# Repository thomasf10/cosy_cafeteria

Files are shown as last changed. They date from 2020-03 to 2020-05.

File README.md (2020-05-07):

# cosy cafeteria: project embedded systems design 2 
This repository contains the developed software and hardware for the lab project of embedded systems design 2.

## Structure
- [Software](Software)
  * [Python server script](Software/python_wifi/WiFi.py)
  * [ESP32 code](Software/fullcode)
- [Hardware](Hardware)
  * [Main PCB](Hardware/MainPCB)
  * [Sensor PCB](Hardware/SesnorBoard)
- [Website/Dashboard](Dashboard)
- [Report](Report/Report.pdf)

## Project discription
To  improve  the  experience  of  the  students  in  the  cafeteria,  an  embeddedsystem will be developed to gather a variety of data.  This data will then bedisplay to the students through an online medium such as a website.  Themain focus will be to gather information about the amount of people thatare in the cafeteria. There are two main goals. The first goal is to display theestimated waiting time to get a meal to the students.  Secondly the amountof available seats will be tracked and displayed to the students.  Next to thissome additional information will be gathered.  The temperature, air-qualityand sound level will be monitored to give the student a general idea about theconditions in the cafeteria.  This way the student can gauge if the cafeteriais suitable to study in at a certain moment.  An overview of the envisioned system is displayed in the figure bellow. 

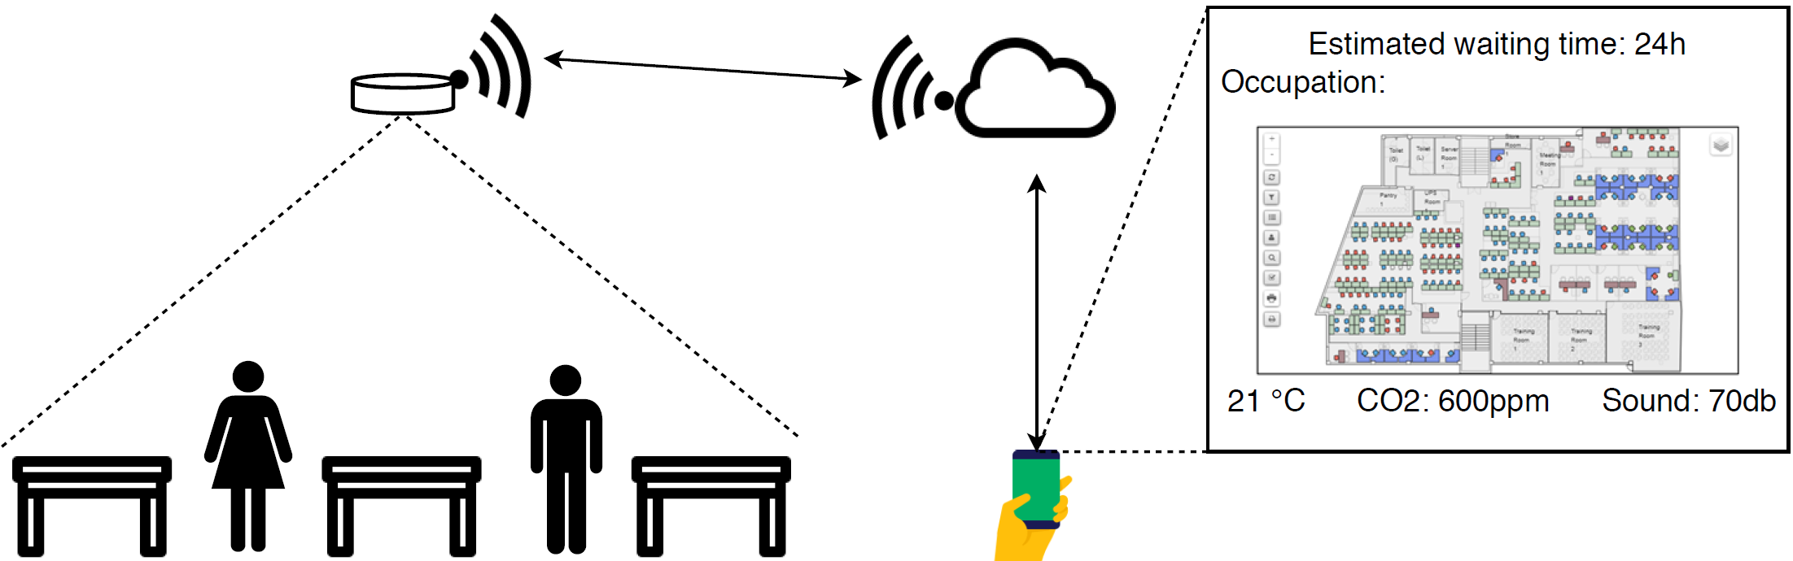
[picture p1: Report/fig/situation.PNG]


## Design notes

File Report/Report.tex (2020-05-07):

\documentclass[11pt,a4paper]{article}
\usepackage{siunitx} % si eenheden
\usepackage{hyperref}					% maak PDF van de thesis navigeerbaar
\usepackage{url}
\usepackage[toc,acronym,xindy]{glossaries}%voor afkortingen
\usepackage{amsmath}
\usepackage[official]{eurosym} % om euro symbool te kunnen gebruiken
\usepackage{graphicx}
\usepackage{svg}
\usepackage[final]{pdfpages}
\usepackage[square,numbers]{natbib} 
\bibliographystyle{IEEEtran}
\usepackage{tabularx}  % betere tabellen
\usepackage[small,bf,hang]{caption} % verbetering captions
\captionsetup[table]{singlelinecheck=off} % caption van tabellen links uitlijnen
\usepackage{color, colortbl}
\definecolor{Gray}{gray}{0.9}
\usepackage{longtable}
\usepackage{titlesec} 					% voor mooiere paragraph
\titleformat{\paragraph}
{\normalfont\normalsize\bfseries}{\theparagraph}{1em}{}
\titlespacing*{\paragraph}
{0pt}{3.25ex plus 1ex minus .2ex}{1.5ex plus .2ex} % nog steeds voor paragraph

% =========== BELANGRIJK VR IN HET VERSLAG: Tonen dat je hebt nagedacht over dimensionering componenten! ===========

% MFA: zet zoekpad voor figure
\graphicspath{{fig/}}
\usepackage{float}                      % De optie H voor de plaatsing van figuren op de plaats waar je ze invoegt. bvb. \begin{figure}[H]

\begin{document}
\title{Embedded systems 2\\
	\Huge Report Cosy Cafeteria
}
\author{Robin Van de Poel\and Arthur Van den Storme\and Tobias Cromheecke\and Thomas Feys}
\date{\today}
\maketitle
\newpage

\tableofcontents
\newpage

\section{Intro}
To improve the experience of the students in the cafeteria, an embedded system will be developed to gather a variety of data. This data will then be display to the students through an online medium such as a website. The main focus will be to gather information about the amount of people that are in the cafeteria. There are two main goals. The first goal is to display the estimated waiting time to get a meal to the students. Secondly the amount of available seats will be tracked and displayed to the students. Next to this some additional information will be gathered. The temperature, air-quality and sound level will be monitored to give the students a general idea about the conditions in the cafeteria. This way the students can gauge if the cafeteria is suitable to study in at a certain moment. An overview of the envisioned system is displayed in figure~\ref{fig:system}. All the developed hardware and software is displayed at: \url{https://github.com/thomasf10/cosy_cafeteria}.
\begin{figure}[H]
	\centering
	
	\caption{Situation sketch}
	\label{fig:system}
\end{figure}

\section{Specifications}
%Zoals we geleerd hebben in dit vak? eerst specs opstellen
%Hierbij moet de keuze's vermeld worden over:
% - Dimensions
% - Microcontroller 
\subsection{Functional specifications}
\begin{itemize}
	\item Monitor the available seats
	\item Monitor the queue to get a meal
	\item Display the data to the students
	\item Energy provision for 1 semester (4-5 months)
	\item Wireless coverage over the entire campus
	\item Measure new data every 10 minutes
	\item Send the data to the online medium every hour 
	\item If the data changes with a large amount (needs to be specified) update the online medium sooner
\end{itemize}

\subsection{Other technical specifications}
\begin{itemize}
	\item Enclosure: 10 x \SI{10}{\centi\meter}
	\item Easy deployment: the node must be easy to attach and detach from the sealing
	\item Must be easy to recharge (Wireless or via USB)
	\item Light weight: \SI{300}{\gram} (so it wont detach from the sealing)
\end{itemize}

\subsection{Non-technical specifications}
\begin{itemize}
	\item Cost: $<$ \euro{100}
	\item The data should be easy accessible to the students
\end{itemize}

\section{System architecture}
An overview of the full system is displayed in figure~\ref{fig:architecture}.
\begin{figure}[!ht]
	\centering
	
	\caption{System architecture}
	\label{fig:architecture}
\end{figure}
The developed system uses three sensors: 
\begin{itemize}
	\item AMG8833: IR grid sensor
	\item CSS811: air quality sensors
	\item Sparkfun sound detector: microphone
\end{itemize}
By incorporating these sensors into the system, a variety of sensor data is gathered, namely: ambient temperature [\SI{}{\celsius}], $CO_2$-level [ppm], TVOC-level (total volatile organic compounds) [ppb] and sound level [db]. Next to this the AMG8833 captures the temperature af a two dimensional area in 8 by 8 pixels. 
\\ \\
The 'brain' of the system is an ESP32, this microcontroller has an integrated Wi-Fi module, which will be used to transmit the data. The gathered data is sent to a server, which stores the received data in a database. 
\\ \\
Alongside the reception of data from the ESP32, the server hosts a website which is used to display the data to the students. The website uses the pixel data to generate a heatmap of the cafeteria, this allows the students to see how many people are present in the cafeteria. Unfortunately one module cannot cover the entire cafeteria, to generate the heatmap. In order to do this, several modules have to be deployed in the cafeteria. In this project only one module will be constructed as a proof of concept. Next to the heatmap, the other sensor data is displayed on the website this includes: ambient temperature, $CO_2$-level, TVOC-level and the sound-level. Based on these parameters the students can gauge if the cafeteria is currently suitable as a study-location.

\section{Power management design}
This section explains the different trade-off's which were made in designing the power management part of the system. The first part in designing the power management is choosing a way to supply the circuit. In our case, the device needs to be deployed at the ceiling of a cafeteria. You can't just tap off the electricity cable at any point here, so our device will need a battery to supply the power. Our first aim was to supply the device as long as one semester. Another aspect was the ability to recharge the battery for environmental reasons. This excludes standard cell batteries that have a much lower energy density and are not rechargeable. Our choice was quickly made for the type of battery, namely a Lithium-Ion (Li-Ion) battery which will be discussed in section \ref{sec:liIon}.

\subsection{Lithium-Ion battery}\label{sec:liIon}
Lithium-Ion batteries are now a commonly used battery in consumer electronics. Li-Ion batteries are the most commonly used batteries in phones, MP3 players and other portable equipment. The voltage of a single Li-Ion battery cell is usually fixed at 3.6 V or 3.7 V. We call this the nominal voltage. However, the actual voltage during use can vary from 2.4 V to 4.2 V. When the voltage drops below 2.4 V, the cell is discharged too deeply and damaged beyond repair. Therefore, a safety voltage of 3 V is often maintained. If the cell is discharged to this voltage, nothing is wrong. Charging a Li-Ion battery usually takes 3 hours. Don't be blinded by fast chargers for these batteries, practical tests have shown that it takes 3 hours until a battery is fully charged \cite{LiIon_ledscherp}. A few benefits of a Li-Ion battery are:
\begin{itemize}
	\item Very high energy density
	\item Minor self-discharge
	\item No memory effect
	\item High power, long service life
\end{itemize}
Some disadvantages are:
\begin{itemize}
	\item Relatively expensive to purchase
	\item Dangerous if used incorrectly, can explode/combust
	\item Need a protection circuit to not drop below the 2.4 V threshold value
	\item Charging and discharging process needed 
\end{itemize}
The most common Li-Ion battery is the 18650 cylindrical cell which is 18mm wide, 65mm long and the '0' stands for its cylindrical shape. Another common type of Lithium-Ion battery is the Lithium-Ion Polymer (Li-Po) battery.
%Li-Po's are:
%\begin{itemize}
%	\item Lighter
%	\item Faster recharge
%	\item Higher power: it's easy to produce batteries that can discharge 10C, 20C\footnote{\url{https://batteryuniversity.com/learn/article/what_is_the_c_rate}}.
%	\item Safer: less ability to explode/combust
%	\item Flexible: can bent (up to $90^\circ$) and deform + can be made in a variety of shapes
%	\item More expensive
%\end{itemize}
Li-Po's are preferred over standard Li-Ion batteries in application where weight reduction is important, fast charge opportunity is needed and which need a very high current during discharge time. Li-Po's are more used for drones (where lightweight is a requirement) and electric cars (fast charging requirement). Li-Po's are also less likely to combust or explode and are more expensive. Therefor a Li-Po would be overkill in our application \cite{LiIonVsLiPo_Ovonic,LiIon_Wiki,LiPo_Wiki}. 

\subsubsection{Selected battery}\label{sec:selected_battery}
The reason we chose a single cell Li-Ion battery was:
\begin{itemize}
	\item Voltage range: our microcontroller needs 3.3 V supply voltage, which is only a low dropout voltage of 0.4 V in comparison with the 3.7 V nominal voltage of a single cell Li-Ion battery. This results in less power dissipation in the voltage regulator. 
	\item Rechargeable: for environmental aspects
	\item High capacity: around 3000 mAh, to last a semester
\end{itemize}
The specifications of the chosen NCR18650B are:
\begin{itemize}
	\item Size/package: 18650
	\item Rated capacity: 3200 mAh
	\item Nominal voltage: 3.6 V
	\item Maximum voltage: 4.2 V
	\item Maximum charge current: 1625 mA
	\item Maximum discharge current: 6400 mA\footnote{Maximum discharge rate is 2C. This means discharging the battery capacity in 0.5 hours $\frac{3200 mAh}{0.5 h} = 6400 mA$ .} % https://batteryuniversity.com/learn/article/what_is_the_c_rate
	\item Maximum discharge voltage: 2.5 V
	\item Charge time: 4 hours
	\item No protection circuit
\end{itemize}
To charge the Li-Ion we had to include a charge circuit in our design. We found a high frequently used breakout board to charge a single cell Li-Ion battery via USB with battery protection \href{http://acoptex.com/project/9446/basics-project-082a-lithum-battery-charger-tp4056-at-acoptexcom/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}{here}. Such a charge circuit would be perfect for our application. Because we couldn't use a breakout board we had to integrate the components on one PCB. Unfortunately the components which were used on the breakout board were not available on the websites we're using to order components like Mouser, Digi-Key, Farnell, etc. After some research and a recommendation of a fellow student who had experience with battery charging applications in his master thesis, he advised to go for Texas Instruments IC's for charging Li-Ion batteries. The charger IC didn't have a protection circuit on it, so we also needed a circuit for this. Eventually we also went for a protection IC and voltage regulator of Texas Instruments. To protect the circuit from reverse polarity of the battery we also included a self-designed protection circuit which was first evaluated in LT Spice. All named components will be discussed in the following sections.

\subsection{Reverse polarity protection}
Reverse polarity protection is a nice feature to have te protect a circuit against polarity mismatches of the battery. For the design of this circuit we based us on a design found on the internet \href{http://kaktuscircuits.blogspot.com/2014/07/reverse-polarity-and-overvoltage.html}{here}. Before implementing this circuit in our design we first evaluated it's correct functioning using LT Spice in section \ref{sec:reverse_pol_prot_sim}.

\subsubsection{Simulation}\label{sec:reverse_pol_prot_sim}
Reverse polarity protection is simply done by including a P type MOSFET as shown in figure \ref{fig:reverse_polarity_protection_simulation}. Since the maximum voltage  of the battery is limited to 4.2 V, there is no need for high drain-to-source voltage $V_{DS}$ requirements for the MOSFET. A suitable MOSFET was found \cite{bib:NTR2101P}. Normally there should be a zener diode placed between gate and source to protect the maximum gate-to-source voltage $V_{GS}$. Since the selected MOSFET's $V_{DS}$ = $V_{GS}$ = 8 V there is no need for a zener diode to clamp the voltage. 
% NTR2101P Spice model: https://www.digchip.com/application-notes/52/54566.php
\begin{figure}[H]
	\centering
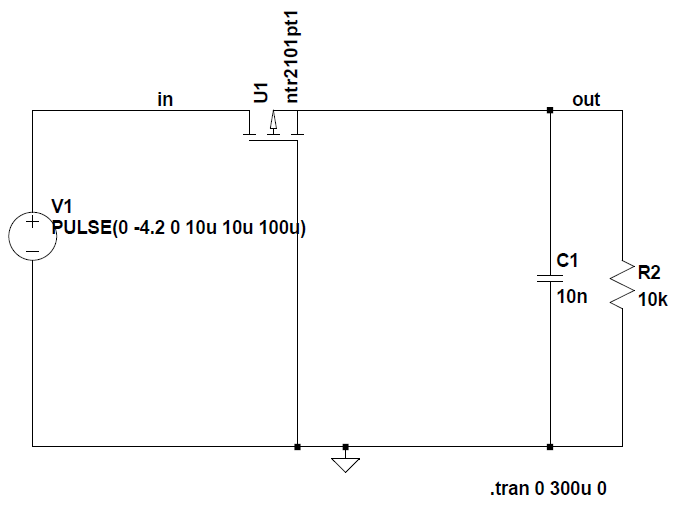
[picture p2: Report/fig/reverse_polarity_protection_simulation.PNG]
	
	\caption{Simulation reverse polarity protection circuit}
	\label{fig:reverse_polarity_protection_simulation}
\end{figure}
Figure \ref{fig:Transient_response_negative_input_pulse} shows the transient response when applying a negative pulse at the input. As can be seen in the figure, the negative pulse doesn't come through the rest of the circuit. The voltage at the output is 0 V.
\begin{figure}[H]
	\centering
	
	\caption{Transient response negative input pulse}
	\label{fig:Transient_response_negative_input_pulse}
\end{figure}
When applying a positive pulse at the input, it can be seen in figure \ref{fig:Transient_response_positive_input_pulse} the output follows the input. We can evaluate the circuit works properly to protect against reverse polarity protection. Now it can be implemented in our design discussed in section \ref{sec:reverse_pol_prot_implementation}.
\begin{figure}[H]
	\centering
	
	\caption{Transient response positive input pulse}
	\label{fig:Transient_response_positive_input_pulse}
\end{figure}

\subsubsection{Implementation}\label{sec:reverse_pol_prot_implementation}
As a precaution we included two batteries in the first version of our design. This was done for debugging reasons: in case our real current consumption would be too high after trying every possibility to reduce it in software, we had an extra battery to meet our lifetime goal. It was possible to include an extra battery because the PCB dimensions were still lesser then 100 x 100 mm. JP1 is a footprint to solder a wire so we are able to measure the current using a current probe. When the battery is inserted with the correct polarity, +BATT is connected to VDD1.
\begin{figure}[H]
	\centering
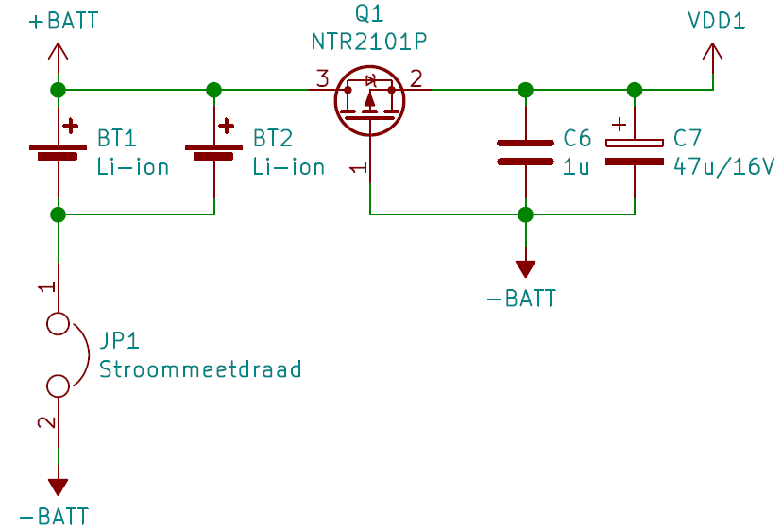
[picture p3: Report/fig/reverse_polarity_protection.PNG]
	
	\caption{Reverse polarity protection circuit}
	\label{fig:reverse_polarity_protection}
\end{figure}

\subsection{Charging choice}
For charging you're free to choose at which voltage and current you charge. Eventually a Li-Ion charger IC will step down the voltage to the maximum 4.2 V for a cell. For charging you could design your own AC-DC converter, we went for the ability to charge the device using USB. Here for we rely on a power adapter which transforms 240 VAC to 5 VDC, or the ability to charge our device using an USB port on a computer. Figure \ref{fig:microUSBinput} shows the input connector micro USB type B with two decoupling capacitors $C_1$ and $C_2$. The charging voltage source is labeled as Vin.
\begin{figure}[H]
	\centering
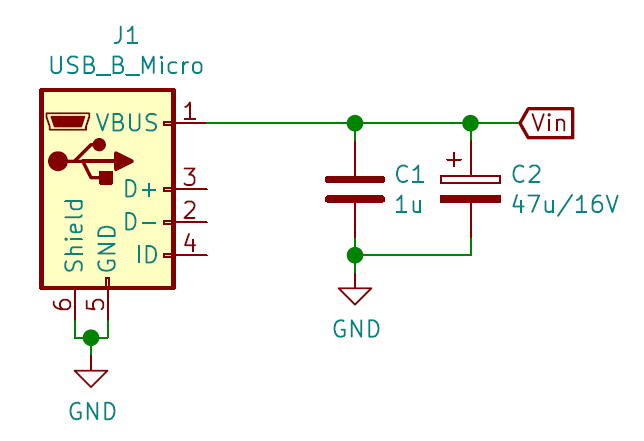
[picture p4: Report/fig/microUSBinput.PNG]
	
	\caption{Micro USB type B input}
	\label{fig:microUSBinput}
\end{figure}

\subsection{Battery charging circuit}
We considerd many chips from different kind of manufacturers. As previously said a TP4056 IC charger is commonly used for single cell Li-Ion batteries, but it's not available on Digi-Key, Farnell, etc. Eventually we went with the BQ24075 IC from Texas Instruments. It's a great choice because it's made to charge a single cell Li-Ion battery, and it's perfectly fit to charge using a USB port. The IC operates from either a USB port or an AC adapter and support charge currents up to 1.5 A. The input voltage range with input overvoltage protection supports unregulated adapters. The USB input current limit accuracy and start up sequence allow the BQ24075 to meet USB-IF inrush current specifications\footnote{\url{http://www.testusb.com/inrush_issue.htm}}. Additionally, the input dynamic power management (VIN-DPM) prevents the charger from crashing incorrectly configured USB sources. An additional specification that was decisive in the choice of charger IC was the availability of 2 pins for status indication:
\begin{enumerate}
	\item \textbf{power good indication:} if the input voltage Vin is in specified range.
	\item \textbf{charge indication:} if the charger is charging (bright up LED) and when the charge cycle is complete (quench LED)
\end{enumerate}
Figure \ref{fig:bq24075_toegepast} shows the BQ24075 IC implemented in our design. A green LED D1 indicates the power good signal, and blue LED D2 indicates the charging stage. When no voltage is applied at the input Vin, the internal transistor Q1 is opened and Q2 is closed. Therefor VDD1 is connected to VDD2. During charge cycle both transistors Q1 and Q2 are closed allowing the battery to charge. The BQ24075 feature a SYSOFF input that allows the user to turn Q2 off and disconnect the battery from the OUT pin. This is useful for disconnecting the system load from the battery, factory programming where the battery is not installed or for host side impedance track fuel gauging, where the battery open circuit voltage level must be detected before the battery charges or discharges. We don't use this feature so we connect SYSOFF to GND to close Q2 for normal operating mode \cite{bib:BQ24075}. %Connect SYSOFF high to turn off the FET connecting the battery to the system output. When an adapter is connected, charging is also disabled. Connect SYSOFF low for normal operation. SYSOFF is internally pulled up to VBAT through a large resistor (approximately 5 M$\Omega$). Do not leave SYSOFF unconnected to ensure proper operation.
The other features of BQ24075 and schematic components will be discussed in sections \ref{sec:charging_phases} to \ref{sec:BQ24075_caps}.
\begin{figure}[H]
	\centering
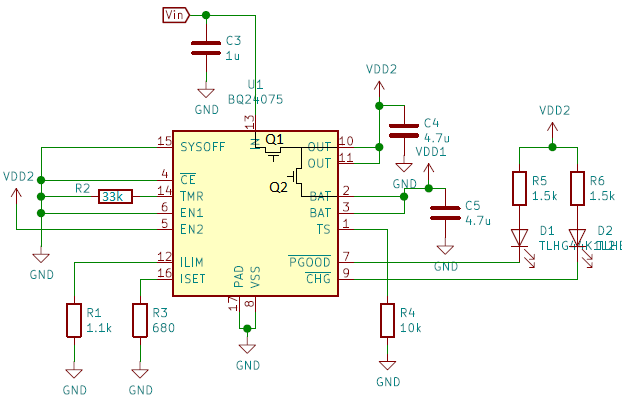
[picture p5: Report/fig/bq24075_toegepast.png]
	
	\caption{Typical application circuit BQ24075}
	\label{fig:bq24075_toegepast}
\end{figure}

\subsubsection{Charging phases}\label{sec:charging_phases}
Set $\overline{CE}$ low to initiate battery charging. The battery is charged in three phases: 
\begin{enumerate}
	\item Conditioning pre-charge
	\item Constant current (CC) fast charge (current regulation) 
	\item Constant voltage (CV) tapering (voltage regulation)
\end{enumerate}
Figure \ref{fig:Charge _cycle} illustrates the three charging phases. In the pre-charge phase, the battery is charged with the pre-charge current $I_{PRECHG}$. Once the battery voltage crosses the $V_{LOWV}$ threshold, the battery is charged with the fast-charge current $I_{CHG}$. As the battery voltage reaches $V_{BAT(REG)}$, the battery is held at a constant voltage of $V_{BAT(REG)}$ and the charge current tapers off as the battery approaches full charge. When the battery current reaches $I_{TERM}$, the CHG pin indicates the charging is done by going high-impedance.
\begin{figure}[H]
	\centering
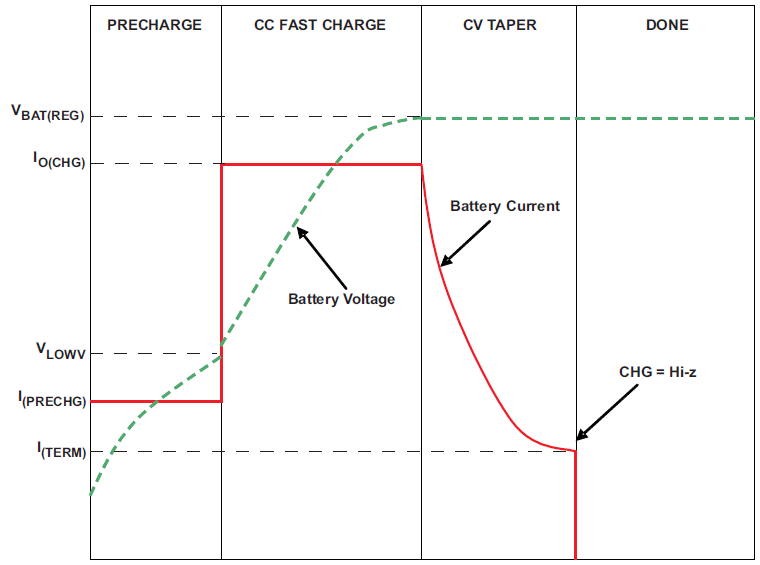
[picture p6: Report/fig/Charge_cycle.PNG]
	
	\caption{Charge cycle \cite{bib:BQ24075}}
	\label{fig:Charge _cycle}
\end{figure}

\subsubsection{Set input current limit $I_{LIM}$}
The BQ24075 IC offers a fully compliant USB charger, meaning:
\begin{enumerate}
	\item Selectable 100 mA and 500 mA maximum input current
	\item 100 mA Maximum current limit ensures compliance to USB-IF standard
	\item Input-based dynamic power management (VINDPM) for protection against poor USB sources
\end{enumerate}
As shown in table \ref{table:USBmode}, EN1 and EN2 are used to configure the USB charge current.
\begin{table}[H]
	\caption{EN1/EN2 Settings \cite{bib:BQ24075}}
	\label{table:USBmode}
	\begin{tabular}{c|c|l}
		EN2 & EN1 & MAXIMUM INPUT CURRENT INTO IN PIN            				\\
		\hline
		0   & 0   & 100 mA. USB100 mode                          				\\
		0   & 1   & 500 mA. USB500 mode                          				\\
		1   & 0   & Set by an external resistor from ILIM to VSS (max. 1.5 A) 	\\
		1   & 1   & Standby (USB suspend mode)                  
	\end{tabular}
\end{table}
USB1.0 specifications allow devices to draw up to 500 mA from one port. USB operates at 5V, so that means a maximum of 2.5 watts. USB 2.0 has the same power limit. But later there were add-ons to the spec for battery charging, allowing up to 1.5A (7.5W) while data transfer is going on, and up to 5A if not. Few USB 2.0 devices can deliver that much power. Also note that the Micro USB connector is only rated to carry 2.1A (10.5W). USB 3.0 increases the power limit to 900mA (4.5W). The battery charging spec from USB 2.0 can optionally be supported \cite{USBpowers}. Since almost all USB chargers and ports are 2.0 and 3.0 nowadays, we can step up the current above 500 mA. The value of the input current limit $I_{LIM}$ is set by the resistor connected from the ILIM pin (pin 12) to VSS, and is given by \cite{bib:BQ24075}
\begin{equation}\label{equ:relationK_ILIM}
R_{ILIM} = \frac{K_{ILIM}}{I_{LIM}} \,,
\end{equation}
with 
\begin{equation}\label{equ:K_ILIM}
K_{ILIM} = 1610 A\Omega \,.
\end{equation}
The valid resistor range is 1.1 k$\Omega$ to 8 k$\Omega$. A value of 1.1 k$\Omega$ results in an input current limit 
\begin{equation}\label{equ:I_LIM}
I_{LIM} = \frac{1610 A\Omega}{1.1 k\Omega} = 1.46 A \,.
\end{equation}
The maximum input current limit 1.5 A is reached. \textbf{Caution:} make sure this current doesn't exceed the value of the maximum charge current of the battery, which is in our case within the permitted limit of 1625 mA (section \ref{sec:selected_battery}).

\subsubsection{Fast charge safety timer (TMR)}
TMR controls the pre-charge and fast-charge safety timers. Leave TMR open to set to default safety timers. Connect to VSS to disable safety timers. Connect a 18 k$\Omega$ to 72 k$\Omega$ resistor between TMR and VSS to program the timers a desired length. Reset the timers by toggling the CE pin, or by toggling EN1, EN2 pin to put the device in and out of USB suspend mode (EN1 = 1, EN2 = 1). The charge time of the battery is 4 hours (section \ref{sec:selected_battery}). We will calculate the TMR resistor $R_{TMR}$ to meet the desired charge time of 4 hours, using equation \cite{bib:BQ24075}
\begin{equation}
R_{TMR} = \frac{t_{MAXCHG}}{10 \cdot K_{TMR}} \,,
\end{equation}
with 
\begin{equation}
K_{TMR} = 48 \, s/k\Omega \,,
\end{equation}
\begin{equation}
t_{MAXCHG} = 4 hr \,.
\end{equation}
\begin{equation}
R_{TMR} = \frac{t_{MAXCHG}}{10 \cdot K_{TMR}} = \frac{4 \, hr \cdot 3600 \, s/hr}{10 \cdot 48 \, s/k\Omega} = 30 \, k\Omega
\end{equation}
Select a resistor value of 33 k$\Omega$, so it's E6-E12 compliant an to extend its charge time a little bit. Connect this resistor between TMR (pin 2) and VSS.

\subsubsection{Set fast charge current $I_{CHG}$}\label{sec:fastchargecurrent}
The value of fast-charge current $I_{CHG}$ is set by the resistor connected from the ISET pin to VSS, and is given by \cite{bib:BQ24075}
\begin{equation}\label{equ:relationK_ISET}
R_{ISET} = \frac{K_{ISET}}{I_{CHG}} \,,
\end{equation}
with
\begin{equation}\label{equ:K_ISET}
K_{ISET} = 890 A\Omega \,.
\end{equation}
The charge current limit is adjustable up to 1.5 A. The valid resistor range is 590 $\Omega$ to 8.9 k$\Omega$. If $I_{CHG}$ is programmed as greater than the input current limit $I_{LIM}$, the battery will charge at the rate of $I_{LIM}$ instead of $I_{CHG}$. In this case, the charger timers will be proportionately slowed down. The maximum charge current for the Panasonic NCR18650B battery is 1625 mA (section \ref{sec:selected_battery}). Set charge current to 1.3 A to have some margin for the battery lifetime and calculate the resistor value
\begin{equation}
R_{ISET} = \frac{890 A\Omega}{1.3 A} = 684.62 \Omega \approx 680 \Omega \,.
\end{equation}
Select the closest standard value (E6,E12,...), which for this case is 680 $\Omega$. Connect this resistor between ISET (pin 16) and VSS.
%The eventual charge current will be 
%\[ I_{CHG} = \frac{890 A\Omega}{680 \Omega} = 1.31 A \,. \]

%\subsubsection{Charge Current Translator}
%When the charger is enabled, internal circuits generate a current proportional to the charge current at the ISET input. The current out of $I_{SET}$ is 1/400 ($\pm$10\%) of the charge current. This current, when applied to the external charge current programming resistor, $R_{ISET}$, generates an analog voltage that can be monitored by an external host to calculate the current sourced from BAT.
%\[ V_{ISET} = \frac{I_{CHG}}{400} R_{ISET} \]

\subsubsection{TS function}
The TS-pin is the external NTC thermistor input. Connect the TS input to the NTC thermistor in the battery pack. TS monitors a 10 k$\Omega$ NTC thermistor. For applications that do not use the TS function, connect a 10 k$\Omega$ fixed resistor from TS to VSS to maintain a valid voltage level on TS.

\subsubsection{Selecting IN-, OUT-, and BAT-pin capacitors}\label{sec:BQ24075_caps}
In most applications, all that is needed is a high-frequency decoupling capacitor (ceramic) on the power pin, input, output and battery pins. Using the values shown on figure \ref{fig:bq24075_toegepast} (these are taken from the typical application circuit in \cite{bib:BQ24075}) is recommended. After evaluation of these voltage signals with real system operational conditions, one can determine if capacitance values can be adjusted toward the minimum recommended values (DC load application) or higher values for fast high amplitude pulsed load applications. Note if designed high input voltage sources (bad/wrong adaptors), the capacitor needs to be rated appropriately. Ceramic capacitors are tested to 2x their rated values so a 16-V capacitor may be adequate for a 30-V transient (verify tested rating with capacitor manufacturer).

\subsection{Battery protection circuit}\label{sec:bat_prot_circuit}
Because the battery we selected doesn't have an integrated protection circuit, we also needed to consider a battery protection circuit in our design. As discussed in section \ref{sec:liIon} it could lead to battery defect when the voltage of the battery drops below 2.4 V threshold value. A Li-Ion is also likely to explode/combust when charging too high in voltage or current. Therefor a protection circuit is always needed. We went for the BQ29700 which is a battery cell protection IC that provides an accurate monitor and trigger threshold for overcurrent protection during high discharge/charge current operation or battery overcharge conditions. The BQ29700 provides the protection functions for Li-Ion/Li-Po cells, and monitors across the external power FETs for protection due to high charge or discharge currents. Figure \ref{fig:bq29700_principeschema} shows a typical application circuit of the BQ29700 IC. In normal mode FETs Charge FET (CHG) and Discharge FET (DSG) are closed, however in one of the following conditions the FETs will open to stop the current flow from/to the battery:
%The system is operating in NORMAL mode when the battery voltage range is between the over-discharge detection threshold (VUVP) and the overcharge detection threshold (VOVP), and the V– pin voltage is within the range for charge overcurrent threshold (VOCC) to over-discharge current threshold (VOCD) when measured with respect to VSS. If these conditions are satisfied, the device turns ON the drive for COUT and DOUT FET control.
\begin{enumerate}
	\item \textbf{Overcharge detection (OVP):} When the cell exceeds the overcharge detection threshold voltage $V_{OVP}$ during charge, the safety circuit will interrupt the flow of current into the cell. When the overcharge voltage is exceeded, a delay of up to $t_{OVP}$ will occur before the FETs open the circuit.
	\item \textbf{Over-discharge detection (UVP):} When the cell exceeds the over-discharge detection threshold voltage $V_{UVP}$ during discharge, the safety circuit will interrupt the flow of current out of the cell. When the over-discharge voltage is reached, a delay $t_{UVP}$ will occur before the FETs open the circuit.
	\item \textbf{Charge overcurrent detection (OCC):} When the pack output current the charge overcurrent detection threshold voltage $V_{OCC}$ during charge, the safety circuit will interrupt the flow of current out of the pack. When the charge overcurrent threshold voltage is exceeded, a delay of up to $t_{OCC}$ will occur before the FETs open the circuit.
	\item \textbf{Discharge overcurrent detection (OCD):} When the pack output current the discharge overcurrent detection threshold voltage $V_{OCD}$ during discharge, the safety circuit will interrupt the flow of current out of the pack. When the discharge overcurrent threshold voltage is exceeded, a delay of up to $t_{OCD}$ will occur before the FETs open the circuit.
	\item \textbf{Load short-circuit detection (SCD):} Similar to overcurrent threshold values, except a short circuit will result in a much higher current, thus a higher sense voltage. The short-circuit detection threshold voltage is indicated as $V_{SCD}$ with delay $t_{SCD}$.
\end{enumerate}
Specifications of the BQ29700 IC are \cite{bib:BQ29700}:
\begin{itemize}
	\item $V_{OVP}$ = 4.275 V
	\item $t_{OVP}$ = 1.25 s
	\item $V_{UVP}$ = 2.8 V
	\item $t_{UVP}$ = 144 ms
	\item $V_{OCC}$ = –0.1 V
	\item $t_{OCC}$ = 8 ms
	\item $V_{OCD}$ = 0.1 V
	\item $t_{OCD}$ = 20 ms
	\item $V_{SCD}$ = 0.5 V
	\item $t_{SCD}$ = 250 $\mu s$
\end{itemize}
\begin{figure}[H]
	\centering
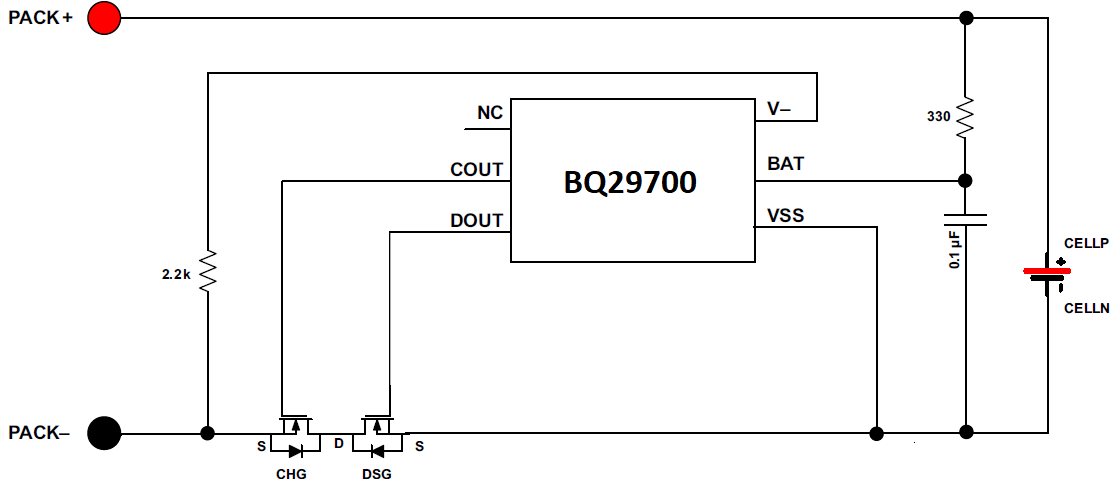
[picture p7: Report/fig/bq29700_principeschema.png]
	
	\caption{Typical application circuit BQ29700 \cite{bib:BQ29700}}
	\label{fig:bq29700_principeschema}
\end{figure}

\subsubsection{Dimensioning}
Figure \ref{fig:bq29700_toegepast} shows the implemented BQ29700 IC in our design. An RC filter is required on the BAT-pin for noise, and enables the device to operate during sharp negative transients. The 330 $\Omega$ resistor also limits the current during a reverse connection on the system. TI recommends placing a high impedance 5 M$\Omega$ across the gate source of each external FET to deplete any charge on the gate-source capacitance. The voltage sense node $V_-$ is a sense node used for measuring several fault detection conditions, such as overcurrent charging or
overcurrent discharging configured as Vds sensing for protection. This input, in conjunction with VSS, forms the differential measurement for the stated fault detection conditions. A 2.2 k$\Omega$ resistor is connected between this input pin and Pack– terminal of the system in the application.
\\ \\
\textbf{FET Selection:} These should be MOSFETs who operate at relativly low voltages (2.8-4.2V battery cell) and that can handle a current of 1.3 A for charging (section \ref{sec:fastchargecurrent}). Because the current is measured by the voltage drop across the FETs, it's $R_{DSON}$ value is also an important value when choosing the right MOSFET. We chose FDS9926A, as it's a dual N-channel MOSFET IC. So both charge and discharge MOSFETs are integrated in one IC. Each FET's $R_{DSON}$ = 35 m$\Omega$ at Tj = 25 $^\circ$C and Vgs = 3.7 V (nominal battery voltage) \cite{bib:FDS9926A}. Because both discharge and charge overcurrent detection levels are the same (100 mV), the discharge and charge current are limited to approximately $\frac{100 mV}{2 \cdot 35m\Omega}$ = 1.43 A \cite{bib:BQ29700, bib:FDS9926A}.
\begin{figure}[H]
	\centering
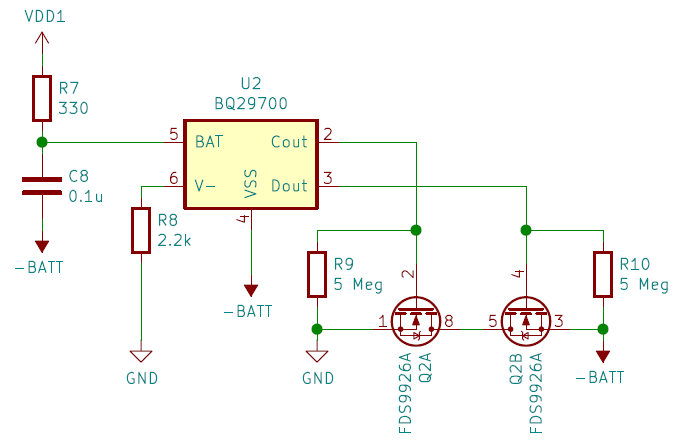
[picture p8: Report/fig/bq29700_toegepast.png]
	
	\caption{BQ29700 applied schematic}  %% AANPASSEN!!!
	\label{fig:bq29700_toegepast}
\end{figure}

\subsection{Voltage regulator}
A few important points to consider when selecting the voltage regulator are:
\begin{enumerate}
	\item Low quiescent current\footnote{Current which is flowing though the converter when no load is applied.} $I_Q$ to reduce power losses for extended battery lifetime.
	\item Low dropout voltage\footnote{The Dropout Voltage of a regulator is the amount of voltage that a regulator needs to be fed above its rated output voltage to maintain the output voltage.} $V_{DO}$ due to the small difference between the 3.7 V nominal voltage of the battery and 3.3 V supply voltage for the ESP32 microcontroller.
	\item At least 500 mA maximum output current $I_{OUT,MAX}$ needed for ESP32 spikes \cite{bib:ESP32-SOLO-1}.
\end{enumerate}
In low power applications a linear regulator is preferred over a switching regulator due the fact switching converters are inefficient at very low loads, and power dissipation in the linear regulator is also low when combined with a low dropout voltage ($P^{\downarrow\downarrow} = U_{DO}^\downarrow\cdot I^\downarrow$). Linear regulators also have much lower quiescent currents in comparison to switching regulators \cite{LDOvsSwitch:1, LDOvsSwitch:2}

\subsubsection{Selected regulator}
As shown in figure \ref{fig:TLV75533_toegepast} we chose TLV75533 from Texas Instruments, with the following parameters:
\begin{itemize}
	\item $I_Q$ = 25 $\mu$A (Typical)
	\item $V_{DO}$ = 150-238 mV (@ $I_{OUT}$ = 500 mA and $V_{OUT}$ = 3.3 V)
	\item $I_{OUT,MAX}$ = 500 mA
\end{itemize}
This device features an internal soft-start to lower inrush current, thus providing a controlled voltage to the load and minimizing the input voltage drop during start up. When shutdown, the device actively pulls down the output to quickly discharge the outputs and ensure a known start-up state. For protection reasons the TLV75533 has an integrated thermal shutdown, current limit, and undervoltage lockout (UVLO). 
\\ \\
Additionally, the TLV75533 has an enable functionality to minimize standby power. Unfortunately we can't use this function because the LDO supplies the microcontroller (these control signals to drive the enable pin should originate from the microcontroller). Therefor the enable pin is connected to the input pin to enable when an input voltage is supplied. 
\\ \\
The TLV75533 requires an output capacitance of 0.47-200 $\mu$F for stability. Use X5R- and X7R-type ceramic capacitors because these capacitors have minimal variation in capacitance value and equivalent series resistance (ESR) over temperature. Place a 1 $\mu$F or greater capacitor on the input pin of the LDO. Some input supplies have a high impedance. Placing a capacitor on the input supply reduces the input impedance \cite{bib:TLV755P}.
\begin{figure}[H]
	\centering
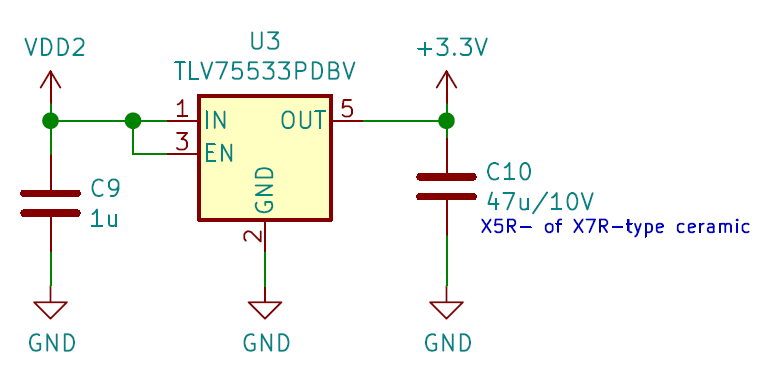
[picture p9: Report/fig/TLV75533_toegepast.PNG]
	
	\caption{TLV75533 applied schematic}
	\label{fig:TLV75533_toegepast}
\end{figure}

\subsection{Load switches}
To reduce power even further you can disable the sensors by shutting off their supply voltage if they're not needed. This can be done by load switches or relays. A load switch is a small electronic switch used to configure and manage power distribution. You can make a load switch with discrete components, but there are significant advantages to using a fully integrated IC load switch \cite{loadSwitch}:
\begin{enumerate}
	\item \textbf{Saves space:} A key advantage of the integrated device over discrete load switches is the small footprint. 
	\item \textbf{Simpler design:} No discrete design time is required. Just buy the integrated chip and design it in to get all benefits and features.
\end{enumerate}
Load switches also has several advantages over relays \cite{loadSwitch}:
\begin{enumerate}
	\item \textbf{Quick output discharge:} An internal resistance in the form of a conducting MOSFET is connected across the load. It serves to discharge to the output capacitor quickly when the enable input goes low.
	\item \textbf{Reverse-current blocking:} Some IC load switches implement a feature that blocks any reverse current. When the enable input goes low to turn off the switch, the reverse current block circuit is enabled thereby reducing any potential reverse current from output back to input to a very low level.
	\item \textbf{Saves power:} Using load switches to manage the power output of the supply minimizes power consumption, saves energy, and provides for longer battery life in portable applications. In its off state, the IC draws minimal quiescent current.
	\item \textbf{Manages inrush current:} This feature prevents input voltage droop that may transpire when the switch is first turned on. This is the result of a high inrush current that occurs when charging the output capacitor. Most load switches provide a controlled ramp up of the output voltage as it charges the output capacitor.
	\item \textbf{Implements sequencing:} Load switches let you implement the sequencing of loads during a turn-on or turn-off operation. Some designs with processors, FPGAs, and other chips require that different supply voltages be applied or disconnected in a specific order. Multiple load switches for each supply that are operated by the related embedded controller for timing meet this need. Certain load switches also feature an output signal that indicates when the output is fully turned on. This signal can be used in sequencing operations with other load switches in the system.
\end{enumerate}

\subsubsection{Selected load switches}
The TPS22919 device is a small, single channel load switch with controlled slew rate. The device contains an N-channel MOSFET that can operate over an input voltage range of 1.6 V to 5.5 V and can support a maximum continuous current of 1.5 A. A few important specifications are \cite{bib:TPS22919}:
\begin{itemize}
	\item Input operating voltage range $V_{IN}$: 1.6 V to 5.5 V
	\item Maximum output current $I_{OUT,MAX}$ = 1.5 A
	\item Low power consumption:
	\begin{itemize}
		\item ON-state $I_Q$ = 8 $\mu$A (typical)
		\item OFF-state $I_{SD}$ = 2 nA (typical)
	\end{itemize}
	\item On-Resistance $R_{ON}$: 89 m$\Omega$ (typical) @ $V_{IN}$ = 5 V
\end{itemize}
The switch ON state is controlled by a digital input that is capable of interfacing directly with low-voltage control signals. When power is first applied, a Smart Pull Down is used to keep the ON pin from floating until system sequencing is complete. Once the pin is deliberately driven High ($> V_{IH}$), the Smart Pull Down will be disconnected to prevent unnecessary power loss. The TPS22919 load switch is also self-protected, meaning that it will protect itself from short circuit events on the output of the device. It also has thermal shutdown to prevent any damage from overheating.
\\ \\
Figure \ref{fig:TPS22919_toegepast} shows the application of TPS22919 for our 3 sensors. The resistor between VOUT and QOD pin is a quick discharge resistor to discharge the output capacitor when the enable pin goes low. For both in- and output capacitors, and the resistor, we used the recommended value as given in the datasheet \cite{bib:TPS22919}.
\begin{figure}[H]
	\centering
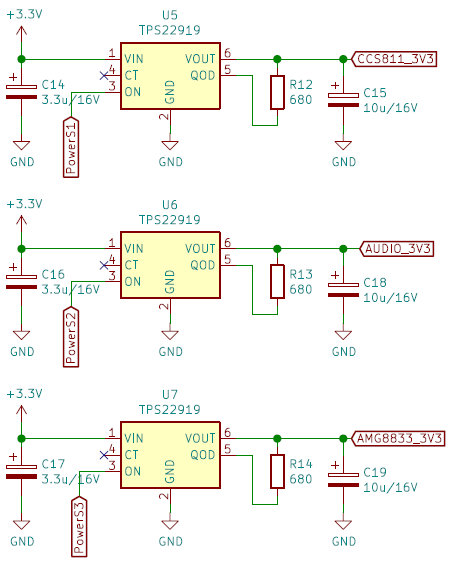
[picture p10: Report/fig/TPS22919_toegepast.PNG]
	
	\caption{TPS22919 applied schematic}
	\label{fig:TPS22919_toegepast}
\end{figure}

\section{Microcontroller}
The microcontroller for this project had to be able to do a few things: connect to the school network, which is an enterprise network, send data over Wi-Fi, have the necessary IO pins to read out all the sensors and be low power.
At first the ESP8266 was considered as this is an easy to use microcontroller. The problem with this microcontroller is that it can't connect to the Wi-Fi network at school as it doesn't support enterprise networks.
Because of this the ESP32 was used, this is the 'bigger' brother of the ESP8266 that supports the enterprise connection. To be more specific the single core version of this ESP32 is used because it uses less power then the normal two core model.
In figure~\ref{fig:ESP32_toegepast} the schematic design is displayed. The PowerS1-3 pins are used to control the loadswitches. SDA and SCL are the clock and data line for the i\textsuperscript{2}c  bus that is used to communicate with the AMG8833 and CSS811.
Then there are also interrupt pins, those are recognisable by the int in the name. The detector from the microphone is labelled Detector\_out and is connected to a pin that is internally connected to an ADC.
Two buttons were also added to be able to put the ESP32 in flash mode, the pins used to flash the ESP32 are the TX and RX pins. 
\begin{figure}[H]
	\centering
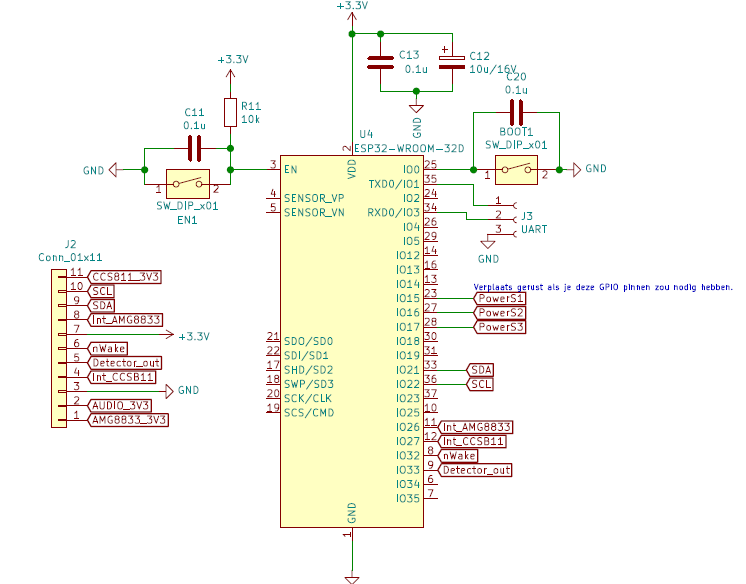
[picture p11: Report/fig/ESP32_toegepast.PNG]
	
	\caption{ESP32 applied schematic}
	\label{fig:ESP32_toegepast}
\end{figure}

\section{Sensorboard}
\subsection{Design considerations}
For the sensorboard design, we have decided to go for a separated board from the main board. This gave us the possibility to design it more freely. For the design, we have chosen to go for a two sided printed circuit board or PCB. All sensors will be placed on the top side of the board for it will be plugged onto the CPU board. Then, we looked what sensors are needed for the design. The parameters that need to be sensed are the sound level, air quality, temperature and the the presences of people.
With this in mind we have chosen the following sensors:
\begin{itemize}
	\item AMG8833 IR-sensor
	\item CCS811 air quality sensor
	\item BOB-12758 microphone breakout board
\end{itemize}
The main goal for the sensor board was to make it as low power as possible. As already mentioned above we have foreseen load switches to cut off the power to the sensors, when the system is non-active for a long period of time. Beside the load switches, we have studied the sensors to optimize the measuring sequence.

\subsection{AMG8833 IR-sensor}
\begin{figure}[H]
	\centering
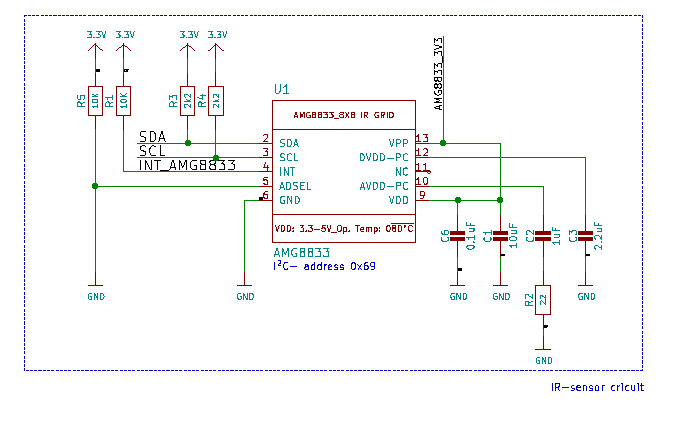
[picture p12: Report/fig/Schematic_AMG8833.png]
	
	\caption{Schematic AMG8833}
	\label{fig:AMG8833}
\end{figure}
To detect human presence, we have decided to use an infrared sensor. The human body produces quite some body heat that is emitted. The AMG8833 is an 8x8-pixel IR-sensor, that maps the heat per pixel this is illustrated in figure \ref{fig:heatmap}. This allows us to determine how many people are present in a certain area. For example we can determine if there is a single person present or a group of persons in a row.
\begin{figure}[H]
	\centering
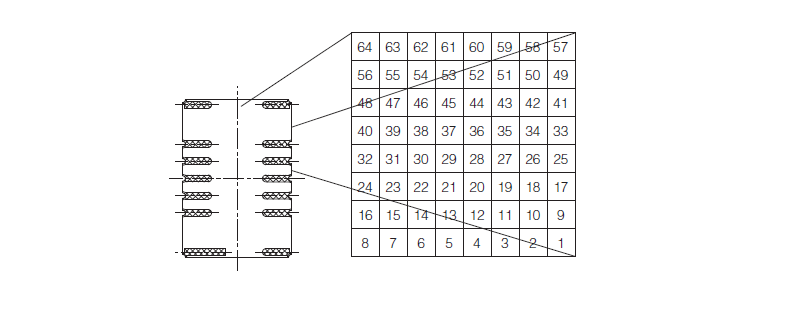
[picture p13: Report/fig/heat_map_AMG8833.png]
	
	\caption{Heatmap as a pixel grid \cite{bib:AMG8833}}
	\label{fig:heatmap}
\end{figure}
One of the considerations that has to be studied is the effect of distance, ambient temperature and the field of view of the sensor. The sensor has a total angle view of \SI{60}{\degree}, as illustrated in figure \ref{fig:angleview}, for the horizontal and vertical axis of the pixel grid \cite{bib:AMG8833}. Depending on the height, the area that the sensor covers, changes. If the height increases, the area also increases. Not only the field of view is influenced by the height but also the result of the measurements. The further the heat source is from the sensor, the lower the measured temperature will be.
\begin{figure}[H]
	\centering
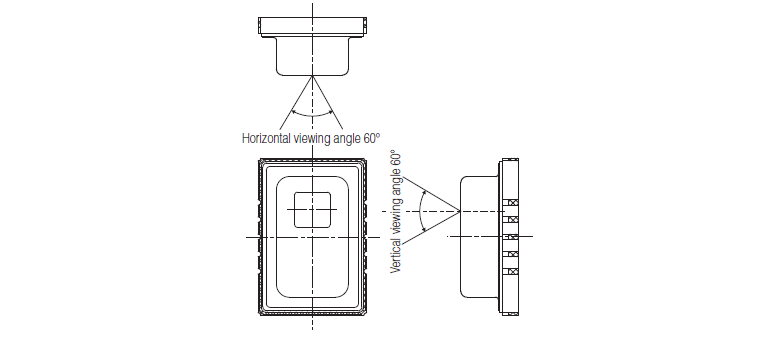
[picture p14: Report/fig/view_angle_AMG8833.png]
	
	\caption{View angle AMG8833 \cite{bib:AMG8833}}
	\label{fig:angleview}
\end{figure}
The sensor operates in a temperature range of \SI{0}{\celsius} up to \SI{50}{\celsius} for the full humidity range between the 15 \%RH and up to about 85 \%RH \cite{bib:AMG8833} . Higher temperatures can be handles if the humidity stays below a certain value. Because, the system will be deployed in the cafeteria, this should not be a problem. An other aspect is the ambient temperature. The sensor has to be capable to determine the difference between the heat of a person and the heat of the surroundings. This will be tested and implemented in the software. 
\\ \\
All communication to and from the sensor is done over $\text{I}^2$C. In addition to the $\text{I}^2$C-communication there is a AD-select input to set the $\text{I}^2$C-address, you can set the address to 0x58 or 0x59 \cite{bib:AMG8833} . There is also an interrupt output if you want to work with interrupts \cite{bib:AMG8833}. 
\\ \\
The last important aspect for this sensor is the power consumption. In the documentation it is stated that the sensor has a typical current of 4.5 mA in normal operation mode \cite{bib:AMG8833} . When the sensor is brought to sleep the current drops to 0.2 mA \cite{bib:AMG8833} . Our goal is to wake the sensor from sleep and when we have the measurement put it back to sleep as fast as possible.

\subsection{CCS811 air quality sensor}
\begin{figure}[H]
	\centering
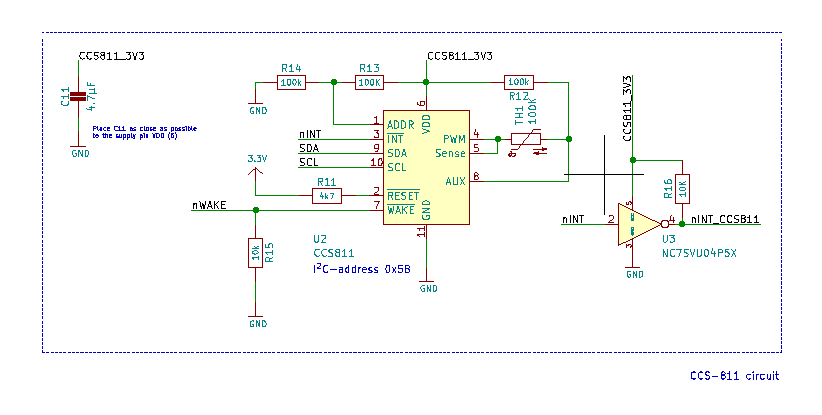
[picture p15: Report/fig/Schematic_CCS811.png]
	
	\caption{Schematic CCS811}
	\label{fig:CCS811}
\end{figure}
For the air quality in the cafeteria, we have chosen to go for the CCS811 air quality sensor. The CCS811 is an ultra low power gas sensor with probable algoritm system for detecting gasses \cite{bib:CCS811}. It has the ability to sense TVOC and an equivalent $CO_{2}$ concentration. This sensor has different measure modes which can help to make the application more flexible but also suitable for mobile equipment and battery powered systems. All settings and communication to the sensor is again done with $\text{I}^2$C. The $\text{I}^2$C-addresses are 0x5A and 0x5B, depending on the ADDR-pin. Besides the $\text{I}^2$C-communication there are some other signals that can control/monitor the sensor. 
\begin{itemize}
	\item There is a \textbf{ADDR}-pin for setting the $\text{I}^2$C-address to 0x5A or 0x5B
	\item The\textbf{ nINT}-pin is an active low pin, that generates interrupts depending on the settings. This pin can generate interrupts when a measurement is available or when the equivalent $CO_{2}$ is above or under a certain value. This is a value that is best buffered before monitoring with a GPIO-pin.
	\item The \textbf{nReset}-pin is not only a reset pin but it can also be monitored to detect a software reset. This can also be an input. If this pin is pulled low you can reset the sensor.
	\item The \textbf{nWake}-pin is also an active low pin. This pin can be used to put the sensor into sleep just by pulling the pin low.
\end{itemize}
The following modes \cite{bib:CCS811} are possible:
\begin{itemize}
	\item \textbf{Idle}: sensor does not perform a measurement: low current mode
	\item \textbf{Mode 1}: a measurement is performed every second: constant power mode
	\item \textbf{Mode 2:}  a measurement is performed every 10 seconds: Pulse heating mode
	\item \textbf{Mode 3}:  a measurement is performed 60 every seconds: Low power pulse heating mode
	\item \textbf{Mode 4}: a measurement is performed every 250 millisecond: constant power mode
\end{itemize}
The Idle-mode has a second purpose when switching from one mode to another. There is a requirement when changing the mode from one with a higher sample rate to one with a lower sample rate. If this occurs, the sensor has to be placed in idle mode for at least 10 minutes. However, this is not necessary in our application. When changing the mode from a lower to a higher sample rate this is not needed. In our application, we have chosen to search for one mode to operate in and always place the sensor back to sleep after the measurement has been read out.
\\ \\
In the documentation \cite{bib:CCS811} it is stated that the average current for a pulse cycle is 0.7 mA with a power supply of 1.8 V. If we calculate the power, we get the following result:
\\ \\
$P= U \cdot I=1.8 V \cdot 0.7 mA = 1.26 mW$
\\ \\
What is the power consumption of mode 3. And, if we compare it with the power consumption of mode 2 we can find:
\\ \\
$\frac{P_{pulse mode}}{P_{low pulse mode}}= \frac{7 mW}{1.26 mW}= 5.556$
\\ \\
This is not expected, You can perform 6 times the measurements with a lower power consumption.
\\ \\
If we now perform the same comparison with mode 1 \& 4, we get the following result:
\\ \\
$\frac{P_{constant power}} {P_{low pulse power}}= \frac{46mW}{1.2 mW}= 38.333$
\\ \\
The power consumption of the constant power modes is only a factor 38,333 bigger then it is in the low pulse power mode. While the amount of measurement is much higher in the constant power mode. This is something that could make our application more low power. This will be investigated by studying the measure behaviour of the sensor. To make it possible that we could use the interrupt functionality of the CSS811, we have foreseen a buffer with an operational amplifier for the nINT-signal.  This is foreseen in the prototype and if this is eventually not implemented in the final design, this can be removed. The nINT is not an essential connection for the CSS811 to work properly.

\subsection{BOB-12758 microphone breakout board}
We have informed us by colleague students who had used a microphone module in the first semester. One group came with a breakout board with a microphone and a triple operational amplifier circuit. The proposed breakout board could do several things, one of them was peak detection. For our application, there is only the need to check the average sound level, so we only needed a microphone and one operational amplifier. In figure \ref{fig:BOB-12758}, we can see the schematic of the breakout board \cite{bib:breakout_microphone}.

\begin{figure}[H]
	\centering
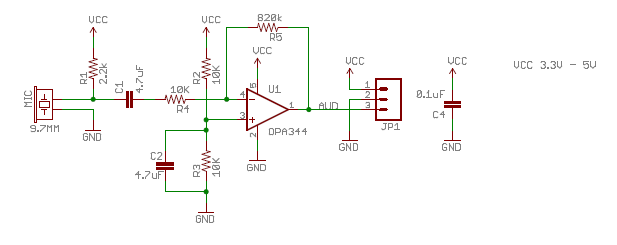
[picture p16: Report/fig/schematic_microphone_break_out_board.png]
	
	\caption{Schematic BOB-12758 microphone breakout board \cite{bib:breakout_microphone}}
	\label{fig:BOB-12758}
\end{figure}
Because we wanted to have the average sound level, we decided to place a detector behind the opamp. The second reason to use the detector is that the ESP32 can sample up to about 27 ksps \cite{ADC_speed}. By just looking at the sample rate, it is clear that the ADC is not fast enough to fulfil the Nyquist theorem. 
\\ \\
The detector needs time to come from the low level to the sound level. Finding the best value of $\tau$ will be one of the investigations. This will be determine along with the test of the other sensors. The microphone must receive power for about 10 times $\tau$. We know from the theory that after 5 $\tau$, 97\% of the applied voltage is reached. The extra 5 $\tau$ is chosen for two reasons. Firstly to compensate the rectified signal by the detector and secondly to have a stable value of the average sound level.

\subsection{Board design}
When designing the board, we have started from the basic schematics of the provided break out boards of the sensor boards (see figures \ref{fig:AMG8833} and \ref{fig:CCS811}) \cite{bib:AMG8833_schematic} \cite{bib:CCS811_schematic}. With some extra guidelines from the documentations of the sensors  \cite{bib:AMG8833} \cite{bib:CCS811}. For the microphone sensorboard as mentioned, we needed to design a detector circuit. We have chosen to go for a simple detector with a diode followed by an RC circuit, this is illustrated in figure \ref{fig:simple_detector}.
\begin{figure}[H]
	\centering
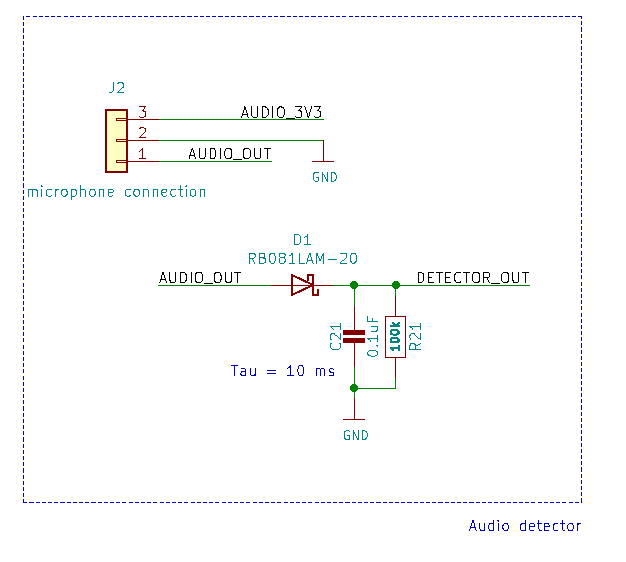
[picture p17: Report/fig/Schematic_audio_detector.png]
	
	\caption{Schematic simple detector \cite{bib:breakout_microphone}}
	\label{fig:simple_detector}
\end{figure}
During the documentation of the circuit it was noticed that the audiosignal of the breakout board is superpositioned onto a DC-voltage that is the half of the supply voltage \cite{bib:breakout_microphone}. This can be seen on figure \ref{fig:BOB-12758}. The resistor circuit R2 and R3 will divide the supply in half, so half of the supply voltage will be available at the non-inverting input of the operational amplifier.

 In the prototype of the board, this was not taken into consideration. This can be solved in different ways not only by hardware but also by software. If we want to solve this with hardware without loosing information, we can just put several diodes in series until we come to a sum of the forward voltages that is the half of our voltage supply. The power supply is $3.3 V$. This method will not increase the accuracy of the measurement so it is not an improvement. \\ \\
$V_{DC offset} = \frac{V_{CC}}{2}= \frac{3.3V}{2} = 1.65V$\\ \\
This $1.65 V$ can approximately be obtained by placing 2 Schottky diodes with $V_{f}=0.45 V$ and a normal diode with $V_{f} = 0.7 V$ in series.\\
$V_{f total} = 2\cdot V_{f schottkey} + V_{f normal diode} = 1.6 V$\\
This will almost eliminate all the DC-voltage in the audiosignal. But still, there could be some DC- voltage left or some information on the amplitude could get lost. \\
A better approach to the problem would be to solve this with software. Then, there is no chance that any information of the sound gets lost expect the information below $ 0.45 V$, but also this could be solved by providing an own DC-offset on top of the audio signal. To solve it with software, we need to know what the ADC value would be if no sound was detected. The DC-voltage after the detector will be $0.45 V$ lower because of the Schottky diode.\\
$V_{DC offset} = \frac{V_{CC}}{2}-V_{f schottkey}= \frac{3.3 V}{2}- 0.45 V = 1.2 V$ \\
The reference level for no sound is $1.2 V$. The maximum audio voltage level would be $2.85 V$. What sound level this would be is unknow to us. Because, it is more a relative perception with a visual indication, exact values are not necessary. The DC-offset has a positive effect on the detection of the sound level. Because the value is above the forward voltage of the diode we do not loose information on the amplitude. But as mentioned we need to do a comparison with the reference level. We can set some thresholds for indicating the experience of a certain value. For example, if the sound level is above a certain value, it is not pleasant to study in the cafeteria.

To determin the optimal value for the resistor and the capacitor of the detector, we would wait to look at the other response time of the other two sensors. We have taken a initial value of 1 ms. This can be realized with a resistor of $ 10 k\Omega$ and a capacitor of $0.1 \mu$F.
\\ \\
For the other two sensors we have, as mentioned, based our schematic on the schematic of the break out boards \cite{bib:AMG8833_schematic} \cite{bib:CCS811_schematic}. We only needed one extra component and that was an operational amplifier to buffer the nINt of the CCS811. This was recommended by the documentation of the CCS811. Also, if this interrupt function is not desired, we can just remove this part of the circuit and the system will work just fine. We have brought all the other connections of the sensors to a central header of 11 pins, so the board can be plugged onto the CPU board. The break out board of the microphone will be placed on top of this board by a 3 pins header.  The schematic drawing of the sensor board can be found in appendix \ref{app:sensorboard_schematic}.

Unfortunately during the prototype phase, the pitch of the pinheader was not found, we have based the pitch according to a recommended connector of the dealer. Afterwards, we came to the idea to check the value at the developer of the breakout board and found a recommended pinheader with a different pitch. The drawing has been updated. Also, this has not been verified because of the corona situation.
\\ \\
For making the system as low power as possible we have an exclusive power supply for every sensor, so we can control the supply for every single sensor separately.
So, the system is flexible depending on the need of what stimulus needs to be monitored.

\subsection{Investigations}
In this section, we are reviewing all our investigations on the sensors. The last part of this section will be the conclusion of all results and how we will implement the sensors in the system.

\paragraph{Time needed before measurement is available}
We started to do some measurements on the \textbf{CCS811} what is the difference in the following to situation:
\begin{itemize}
	\item Time needed for initialization
	\item Time needed for the sensor to wake from sleep
\end{itemize}
The first situation is to see if we could save some energy if we shut down the power supply of the sensor. Also, this is interesting to know if we use the load switches to turn of the power of each sensor. The second situation is as the CCS811 is normally used in an application. The test procedure for these tests was as followed. After the sensor was waked or initialized, a timer was started. After every ms, we looked in the registers of the sensor if a measurement was available. This was done with the following method \textbf{Adafruit\_CCS811::available()} from the \textbf{Adafruit\_CCS811} \cite{lib_CCS811} . If we get \textbf{True} back from this method, we stop the timer and made it visible.
\\ \\
We got the following results from these test.
\begin{itemize}
\item \textbf{Time after initialization:} It takes more than several sample period before we get a result. Also in the documentation, it is stated that after initialization the results are not that reliable.
\item \textbf{Time after sleep:} About the sample rate of the mode that the sensor is set in. the shortest time is 250 ms in \textbf{mode 4}. 
\item \textbf{ Time started from idle:} It took more time before the first measurement was available when changed from idle to the wanted mode.
\end{itemize}
\textbf{Conclusion:} \\ The first conclusion of these tests is that bringing the sensors out of sleep is the fastest way to get a measurement. This is because for getting the sensor out of sleep we just need to alter the mode. 
\\ Second conclusion, the sample period has always been respected. It is not the case that the sensor will perform a measurement at wake up. If the sensor is woken up, it will take the time of the sample period for a measurement to be available.
\\ \\
The second sensor we needed to check was the \textbf{AMG8833}. The procedure was the same, the only difference is, to bring the AMG8833 out of sleep, this needs to be done with an $\text{I}^2$C-command instead of a GPIO pin. Also, for this we use the library \textbf{SparkFun\_GridEYE\_Arduino\_Library} \cite{lib_AMG8833} . The method to wake the sensor is wake() and putting it back to sleep with sleep(). We have chosen to use the sample rate of 10 samples per second. For reading out the raw data of a single pixel there is the method "getPixelTemperatureRaw" \cite{lib_AMG8833} . We checked every millisecond if the first pixel data was available. We noticed during testing that not all pixel data was available after 100ms. So we changed the check so that the timer may be stopped if the first pixel and the last pixel of the array had a value. With this measurement principle, we found that after 105 ms the data of all pixels was available.
\\ \\  
Before going further with the last sensor, we wanted to see if we put the the readings after each other what the effect would be. How much time it cost to read out the AMG8833 sensor. We made a method that read both sensors after each other. We found that the CCS811 was ready to read out. What this means for the implementation will be explained further on in this report. 
\\  \\ Now, we have come to the last sensor the microphone, we have chosen to use a breakout pcb as mentioned above. The only thing, we needed to check is which $\tau$ we can take for the filter of the detector. We could not test this because there was no hardware available for this. Based on the previous results, there is a delay of 105 ms between waking the sensors and have the measurements available. As mentioned, we wanted a period of 10 $\tau$ beacause the detector has to reach a stable average value to measure. If we divide 105 ms  by 10, we get  a $\tau$ of 10.5 ms. If we round this to 10 ms, we can realized this $\tau$ with a resistor of 100 k$\Omega$ and a capacitor of 100 nF.\\
$\tau= R \cdot C =  100 k\Omega \cdot 100 nF= 10 ms$.\\
Which are values that are easily found as SMT-components. If we look more deeply into the 10.5 ms for $\tau$, this is also interesting for audio in another way. All frequency higher then 100 Hz will be detected quite enough. Only some lower frequencies will probably not be detected. But if we look at the chart of equal loudness for the different frequency at different sound pressures. We can see that for frequencies lower then say about 400 Hz the amount of sound pressure needed for a same loudness experience is much larger. 
\\ \\ With this substantiated scientific information, we can state the value of 10 ms is a good value for a quick and correct response for indicating the loudness of noise in the cafeteria. If we also take a look at the frequency response of the breakout board. The signals from 100 Hz will be picked up to about 1 kHz with the same gain value. Outside these boundaries, the gain of the audio signal will fall back. The value of 10 ms is again a good value for the $\tau$.

\paragraph{Human presence detection}\label{sec:amg}
For this we have done two straight forward experiments with the \textbf{AMG8833}.
\begin{itemize}
\item \textbf{First experiment:} Heat detection on a person
\item \textbf{Second experiment:} Detecting a person from a height
\end{itemize}
For the first experiment we have put a person in front of the AMG8833 at about 20 cm, 40 cm. Then measurements were performed when pointing the sensor at the face, a lined body part and the crown of the head. There was some difference in the measured values. The  difference between the lined body part and the face was noticeable. There is a small difference between the face and the crown but not that much. 
\\ \\ 
This concludes, we can detect a human by the radiation coming from the crown of the head.
\\ \\
With this confirmed, we progressed into the second experiment. Is it possible to detect a human below the sensor at a height of 3,4 metres (possible to test at home during corona pandemic). The height difference between the head of an average standing person and the sensor is about 1,7 metres \cite{average_height}. At this height the sensor will covers an area of $3.85 m^2$. We know the sensor had a angle view of \SI{60}{\degree}. If we then calculate according to the principal geometric drawing in figure \ref{fig:prinicipal drawing},  we find:
\\ \\
$ x = height \cdot tan (\SI{30}{\degree}) = 1.7 m \cdot 0.577 = 0.981 m$
\\ \\
\begin{figure}[H]
	\centering
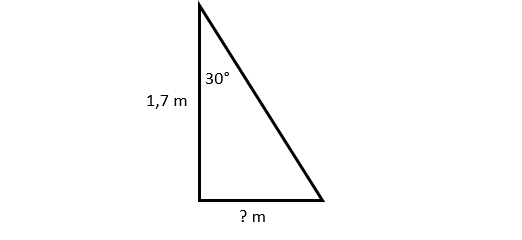
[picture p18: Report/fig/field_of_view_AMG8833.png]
	
	\caption{Principale drawing view sensor AMG8833}
	\label{fig:prinicipal drawing}
\end{figure}
Finding the field of view of the sensor at this height, $\textbf{x}$ must be doubled and squared:\\
$ A = (2 \cdot x)^2 = (2 \cdot 0.981 m)^2 =  3.85 m^2$
\\
If the sensor is at a height of 3.4 metres the covered area will be 3.85 $m^2$, which is a workable area for noticing someone is sitting at a table.
The area will be even bigger because the distance will be bigger. We wanted to know if it is possible to detect a person and to track the person.
For this we have placed the sensor at this height and analysed the results if someone moved beneath the sensor. When analysing the result we found that a person was represented by 1 or 2 pixels, with a value that is about 2-\SI{3}{\celsius} higher than the surroundings this is illustrated in figure~\ref{fig:humandetection}. 
\begin{figure}[H]
	\centering
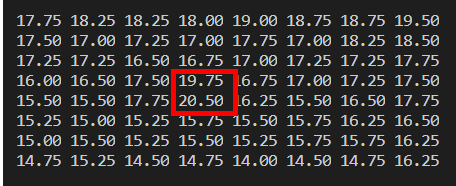
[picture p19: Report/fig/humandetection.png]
	
	\caption{Human detection at a height of 3.4 metre}
	\label{fig:humandetection}
\end{figure}
The test was performed in a space with an overall temperature of about 17 degrees on ground level. Which is not a normal room temperature. During testing the results were fluctuating about \SI{0.25}{\celsius} which is the resolution of the sensor in \SI{}{\celsius}. Notice the higher numbers at the top pixels. This could be because the test setup was attached on a wooden staircase at 3.4 metres high where some light bulbs hang.\\ \\
\textbf{Conclusion:} It is possible to detect a person at a height of 3.4 m in a room with a temperature of \SI{17}{\celsius}. It was also possible the follow his movements. If placing this into practice The best way is to compare the value of a pixel top an overall temperature or to a reference value. This should have been tested at the cafeteria during optimization of the system.

\subsection{Programming the sensors}
With the experiments mentioned above we made some methods for initializing the sensors and getting the measurement results of the sensors. For having a clear overview of our code we have made a own library with these methods, that combines our own code with code from the already mentioned libraries.  

We can divide the created methods in two types: initializations methods, for initializing the sensors after power on and methods for reading the sensor data. We have foreseen for the initialisation a main method were the different methods will be called one after each other with the correct flow. The slowest sensor will be initialized first so the time to start up can be use to initialize the other sensors.

For the initialization of the sensors, we just enable the $\text{I}^2$C-communication, set some GPIO-pins, set the ADC and set some sensor registers with the methods of the libraries. For setting, the GPIO's and the ADC we use the standard libraries of the system \textbf{driver/gpio.h}  and \textbf{driver/adc.h}.

For the methods for retrieving the data from the sensor. The method is made in the following steps:
\begin{itemize}
\item Wake the sensors
\item Wait until data available
\item Retrieve data
\item Put the sensor back to sleep
\end{itemize}

% ============ Geofrey wil zien dat we hebben nagedacht over de dimensionering van de componenten !!! ============

\section{Wireless connectivity}
\subsection{Wi-Fi connection} \label{wifiCon}
In order to transmit the sensor data to the server, the Wi-Fi connectivity of the ESP32 is used. The transmission is provided by a TCP connection that is established between the ESP32 and the python server. At the initialisation of the python server, a socket is opened, this socket is used to receive the data. In this manner the server is always listening on the socket, until a message is received. The ESP32 sends the data in the following order: pixeldata (64 floats), temperature (1 float), audio level (1 float), $CO_2$-level (1 unint16), TVOC-level (1 unint64) and an ID (1 uint8). The received data is processed by order to determine which data is represented by the received values. The data is parsed into different variable, these variables are then used to update the values in the database. 

\subsection{Power consumption}
To determine the power that is consumed when the sensor data is transmitted once, a measurement is performed. The result is displayed in figure~\ref{fig:wifi_pwr}.
\begin{figure}[H]
	\centering
	
	\caption{Power consumption of one Wi-Fi transmission}
	\label{fig:wifi_pwr}
\end{figure}
In order to interpret the current consumption, the used charge is displayed in [mAh]. This results in 0.041 mAh of charge that is used in order to transmit the sensor data once. With this knowledge, we can calculate the amount of Wi-Fi transmissions that are possible with the 6400 mAh battery:

\begin{equation}
	\frac{6400}{0.041} \approx 156097 \text{ transmissions}
\end{equation}

If there are 6 transmissions per hour and the system is active for 7 hours a day, this leads to a battery life off 3716 days.  However, this calculation only accounts for the Wi-Fi transmission, other power consumption such as stand-by power, CPU power and sensor power are not accounted for in this calculation. 

\section{Software design}
\paragraph{Functionality}
\begin{itemize}
	\item Pull sensors from sleep state every 10 minutes and read sensor values
	\item Send sensor data to server, over Wi-Fi
	\item Perform periodic synchronisations to get time information
	\item Use time information to disable power to sensors and put CPU in deepsleep during the night
\end{itemize}
\paragraph{Overview}
The software is based on a number of states, these states are: NTPsync, checktime, nightsleep, wakefromnightsleep, wakesensors, readsensors, senddata and sleep. An overview of the complete software and the transitions between the states is illustrated in figure~\ref{fig:statediagram}. The states are discussed further below. 
\begin{figure}[!ht]
	\centering
	
	\caption{State diagram}
	\label{fig:statediagram}
\end{figure}
\paragraph{NTP-sync}
In this state an NTP synchronisation is performed. This provides time information which is stored in the RTC memory and maintained by the RTC clock. The time information allows the system to know when it is night time. During the night the sensors can be disabled, using the load switches, and the microcontroller can go in to deepsleep until the morning. This way the sensors only receive power between 9 AM and 4 PM. 

\paragraph{Check time}
This state has two functionalities. Firstly the current time of day is retrieved from the RTC clock. If this time info is not available, the NTP synchronisation was not successful. When this is the case the microcontroller goes in to deepsleep for five minutes and the next state will be the NTP sync to retry the synchronisation. If the synchronisation fails three times, the system is rebooted. Next to this, when the synchronisation was successful, the time information will be available. This time information is then used to check the current time. If the time is between 9 AM and 4 PM the system remains active, thus the next state is set to wakesensors. If the time is after 4 PM and before 9 AM, the system has to go to sleep, thus the next state is set to nightsleep.

\paragraph{Night sleep}
This state is entered when it is past 4 PM and before 9 AM. During this time the sensors are disabled and the microcontroller goes in deepsleep. The sensors are disabled by raising the GPIO pins which control the load switches. When the GPIO pins are high, the load switches cut off the power to the sensors. Before entering deepsleep, the next state is set to wakefromnightsleep. During the night, no sensor data has to be collected and transmitted because the campus is closed. So by cutting off the power to the sensors and putting the microcontroller in deepsleep during the night the power consumption is drastically reduced. 

\paragraph{Wake from night sleep}
When the system wakes up at 9 AM, the power to the sensors has to be enabled. This is done by lowering the GPIO pins which control the load switches. Next to this, the system checks when the last synchronisation was performed. Because the RTC clock is derived from an internal RC oscillator with a frequency of \SI{150}{\kilo\hertz} and an accuracy of +/-5\% the clock time will drift away from the actual time. In order to prevent this, an NTP synchronisation has to be performed periodically. In order to retain an accurate clock, the synchronisation is performed every 14 days. Thus if the last synchronisation was performed 14 days ago, the next state is set to NTPsync. If the last synchronisation was more recent, the next state is set to checktime. 

\paragraph{Wake sensors}
In the wake sensors state, the sensors are taken out of their sleep state and put in active mode. When the sensors wake from their sleep state the sensor values can not be read immediately. A waiting period of 105 milliseconds is necessary in order to have stable sensor values. During these 105 milliseconds the sensors remain active but the microcontroller is put into deepsleep mode. Before entering deepsleep, the next state is set to readsensors. 

\paragraph{Read sensors}
In this state the sensor values are read out. Once the data is acquired, the sensors are put back in to their sleep state and the next state is set to senddata.

\paragraph{Send data}
In this state, the sensor data is transmitted to the python server which is running on a raspberry pi. Once the transmission is successful or the connection has timed-out the next state is set to sleep.

\paragraph{Sleep}
Once the sensor data has been transmitted to the server, the sleep state is entered. In this state, the microcontroller is put into deepsleep for 10 minutes. Before entering deepsleep, the next state is set to check time.

\section{Autonomy}

\subsection{Consumption sources}
In this section the different sources that consume power will be discussed.

\paragraph{Wi-Fi communication}
The system transmits the sensor data to the server over a Wi-Fi connection. This data transfer happens every 10 minutes. Because the sensors are disabled between 4 PM and 9 AM, no Wi-Fi connection is needed during that time. With a wake time of seven hours and 6 transmissions per hour, this leads to 42 transmissions per day. A measurement of the typical power consumption for one Wi-Fi transmission is illustrates in figure~\ref{fig:wifipwr}.
\begin{figure}[!ht]
	\centering
	
	\caption{Power consumption of one Wi-Fi transmission}
	\label{fig:wifipwr}
\end{figure}
The charge that is used for one transmission is 0.041 mAh. This leads to the following consumption per day:
\begin{equation}
42 \cdot 0.041 = 1.722 \text{ mAh/day}
\end{equation}

\paragraph{Sensors}
The sensors are read out every ten minutes. With a wake time of 7 hours\footnote{Only awake between 9 AM and 4 PM}, this leads to 42 sensor measurements per day. The power consumption to read out the sensors once is illustrates in figure~\ref{fig:sens_pwr}.

\begin{figure}[H]
	\centering
	
	\caption{Power consumption of one sensor measurement}
	\label{fig:sens_pwr}
\end{figure}

The charge that is used to read out the sensors once is 0.035 mAh. This leads to the following consumption per day:
\begin{equation}
	42 \cdot 0.035 = 1.47\text{ mAh/day}
\end{equation}

\paragraph{NTP synchronisation}
In order to synchronise the RTC clock an NTP synchronisation has to be performed periodically. This synchronisation is performed once every 14 days. The power consumption for one synchronisation is illustrates in figure~\ref{fig:ntp_pwr}.

\begin{figure}[H]
	\centering
	
	\caption{Power consumption of one NTP synchronisation}
	\label{fig:ntp_pwr}
\end{figure}

The charge that is used for one synchronisation is 0.08 mAh. However, this synchronisation only happens once every 14 days, this leads to the following consumption per day:
\begin{equation}
	\frac{1}{14} \cdot 0.08 = 0.0057 \text{ mAh/day}
\end{equation}

\paragraph{Standby daytime}\footnote{No measurement were performed to determine the stand-by power, this has two reasons. 1: the development board to test the software has an onboard LED which increases the power consumption so the gathered measurements wouldn't be representative. 2: to measure the power consumption a \SI{1}{\ohm} resistor was inserted between the power source and the development board. This resistor is used as a sense resistor but can not provide accurate \SI{}{\micro\ampere} measurements due to the noice that is introduced. }
Between 9 AM and 4 PM the system is 'active', this means that the sensors receive power. However when the sensors are not being read out they will be put in their respective sleep modes. The theoretical consumption that is gathered from the datasheets is listed below:
\begin{itemize}
	\item AMG8833 sleep mode: 0.2 mA
	\item CCS811 sleep mode: with $V_{dd}$ = \SI{1.8}{\volt}: 19 $\mu$A \\$\Rightarrow$ with $V_{dd}$ = \SI{3.3}{\volt}: $\frac{19}{1.8}\cdot 3.3 = 34.83 \text{ }\mu\text{A}$
	\item microphone: the power to the microphone is only enabled just before the measurement because of this the microphone has no stand-by/sleep consumption. 
\end{itemize}
Next to the consumption of the sensors, there is the sleep consumption of the microcontroller. If the microcontroller is not active, it is put in deepsleep. In deepsleep there is a consumption of 10 $\mu$A. Next to this consumption, two GPIO pins have to remain high during deepsleep: one to keep the CCS811 in sleep (nWake) and on to drive the load switch to disable the power to the microphone. The GPIO pins use an internal pull-up resistor of \SI{45}{\kilo\ohm} this leads to the following consumption for one GPIO pin: 
\begin{equation}
	\frac{3.3 \text{V}}{45000\Omega} = 73.33 \text{ } \mu\text{A} 
\end{equation}
For both GPIO pins this results in a consumption of 146.67 $\mu$A.
\\
For 7 hours a day the system is in active mode, this results in a charge consumption of:
\begin{equation}
	7 \cdot (0.2 + 0.03483 + 0.01 + 0.1467) = 2.74\text{ mAh/day}
\end{equation}

\paragraph{Standby nighttime}\footnote{No measurement were performed to determine the stand-by power, this has two reasons. 1: the development board to test the software has an onboard LED which increases the power consumption so the gathered measurements wouldn't be representative. 2: to measure the power consumption a \SI{1}{\ohm} resistor was inserted between the power source and the development board. This resistor is used as a sense resistor but can not provide accurate \SI{}{\micro\ampere} measurements due to the noice that is introduced. }
Between 4 PM and 9 AM the system goes in to sleep mode. In sleep mode no sensor measurements are performed and no data is transferred via Wi-Fi. To reduce the power, the power to the sensors is cut-off by using the load switches. The remaining stand-by/sleep consumption originates from the CPU consumption in deepsleep and the three GPIO pins that are kept high to drive the load switches. This leads to the following consumption:
\begin{equation}
	10 \text{ }\mu\text{A} + 3\cdot 73.33\text{ }\mu\text{A} = 230\text{ }\mu\text{A}
\end{equation}
The system remains in sleep mode for 17 hours a day this leads to the following consumption per day:
\begin{equation}
	17 \cdot 230\text{ }\mu\text{A}= 3.91\text{ mAh}
\end{equation}

\subsection{Total power consumption}
In the previous section all the different sources that consume power were discussed an overview is given in table~\ref{tab:pwr}.

\begin{table}[H]
	\centering
	\begin{tabular}{|l|l|}
	\hline
	\textit{\textbf{Source}} & \textbf{Charge per day {[}mAh/day{]}} \\ \hline
	Wi-Fi                    & 1.722 mAh/day                         \\ \hline
	Sensors                  & 1.47 mAh/day                          \\ \hline
	NTP sync                 & 0.0057 mAh/day                        \\ \hline
	Standby daytime          & 2.74 mAh/day                          \\ \hline
	Standby nighttime        & 3.91 mAh/day                          \\ \hline
	\rowcolor{Gray}
	Total                    & 9.85 mAh/day  						 \\ \hline
	\end{tabular}
	\captionsetup{justification=centering}
	\caption{Overview of the power consumption per day}
	\label{tab:pwr}
\end{table}

There are two Li-Ion cells that are used to power the system, they both have a capacity of 3200 mAh which results in a total capacity of 6400 mAh. This leads to the following battery life:
\begin{equation}
	\frac{6400}{9.85}=649 \text{ days}
\end{equation}
The original goal was to provide power to the system for one semester which is approximately 180 days. The final result can provide power for 649 days. This is a much better result than desired in advance. However, the actual power consumption will probably be a bit higher due to: self discharge of the batteries, quiescent current of the voltage regulator, quiescent current of the loadswitches, etc. Because the calculated result is 649 days, this leaves a good amount of buffer for this additional consumption. Thus we can conclude that the practical implementation will not have a battery provision of 649 days, but a little bit lower. However, the goal of one semester will definitely be met.

\section{DashBoard}
\paragraph{Functionality}
\begin{itemize}
	\item Receive the data from the sensor
	\item Store the data in a database
	\item Display an overview with the averages of every sensor
	\item Display the data from each sensor on a heatmap
\end{itemize}

\paragraph{Overview}
The intention of this dashboard is to display the data that the different sensors on all the devices in the cafeteria generate.
It gives an overview of what's happening in the cafeteria in an air quality, temperature and sound perspective. 
The infrared camera data which is an 8 by 8 pixel picture is drawn on a heatmap. 
This gives a nice overview of the busy and the less busy area's in the cafeteria.  

\subsection{Backend}
The backend is what runs on our server, in this project a raspberry pi was chosen as it's an easy to use and small computer
 that can easily be set up to be used as a webserver, apache2 was used in this project to host our dashboard. Myqsl is used for the database that stores the sensor data.

\paragraph{Recieve data}
To receive the data a python script (WiFi.py) is used that listens to the 8091 port, this is the port that the device sends his payload to.
The protocol that is used to send data from the device to the raspberry pi is TCP. A more in depth explanation can be found in \nameref{wifiCon}.

\paragraph{Store data}
The received data is stored in a mysql database, this is also implemented in the WiFi.py script that is used to receive the data.
To use the database in the python script a mysql.connector is used.
The database uses 3 tables: 
\begin{itemize}
	\item location: this table is used to store the location of the sensor. It has an x-, y-coordinate and the location id.
	\item sensor: this table stores the sensor id  and has the location id as a foreign key.
	\item readings: This is the table that stores all the sensor data with the date and time that it was received on. 
					All the data that isn't an array is stored as a float, the arrays with the 64 pixels from the infrared camera are stored as a json string.
					The two other columns in this table are the reading id and the sensor id.  
\end{itemize}
A visual representation of the database descript above can be seen in figure~\ref{fig:db_des}.

\begin{figure}[H]
	\centering
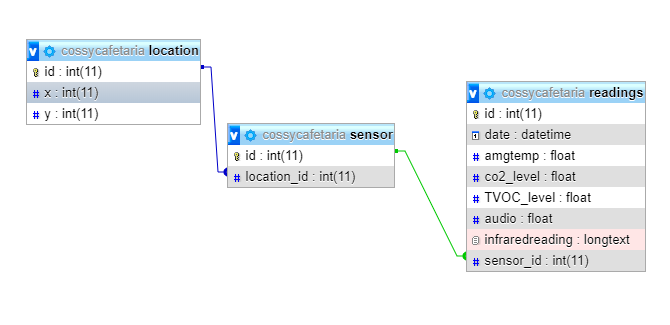
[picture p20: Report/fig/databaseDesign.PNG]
	
	\caption{Visual representation of the database}
	\label{fig:db_des}
\end{figure}

\paragraph{Data from database to dashboard}
A php script is used to serve the data to the frontend of the dashboard. This php script is called database.php. 
It's a simple script that connects to the database on the raspberry pi and gets the last received reading from all the different devices.
Then all this data is encoded as json and passed on to the website, this website is the dashboard. 

\subsection{Frontend}
The frontend is the part of the dashboard that people can interact with and view the data from all the different devices and sensors.
This website has 6 different pages, an overview page that shows the averages of all the sensor data from all the different sensornodes.
The other pages show a heatmap with the specific sensor data of each sensornode separately drawn on it. 
For example, there is an activity page that display where the infrared camera picks up heat signals, a temperature page that displays where it is warmer or colder.
Each type of sensor reading has it's own page.

\paragraph{Overview page}
As already stated in the short description above, this page takes the average of all the sensor data from the different sensornodes. 
On this page two subsection are made, the first one is named activity and under it the busyness of the cafeteria is show by giving the average of all the pixeldata from all the sensornodes.
In the second subsection the sensor data related the the environment is shown, the numbers displayed here are also an average taken from all the different sensornodes. 
The displayed data here is: Co2 level, TVOC level, Sound and temperature. Al this can be seen in figure~\ref{fig:overview_page}. 
\begin{figure}[H]
	\centering
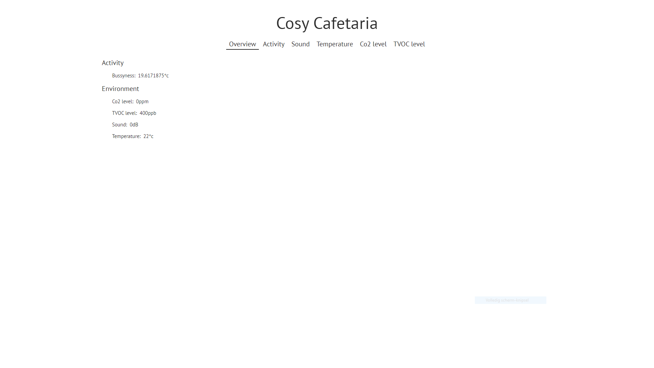
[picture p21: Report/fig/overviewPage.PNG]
	
	\caption{Screenshot from the overview page}
	\label{fig:overview_page}
\end{figure}
The averages of all the data are calculated using a javascript script in the website, so each time there is new data and the webpage is reloaded this will update to the latest data.
The javascript loops through the data from the database that it get's in the JSON format from the database.php backend script.

\paragraph{Page with heatmap}
These pages show one single type of data from that the sensor node gathers, in this case the pixeldata from the infrared camera.
On figure~\ref{fig:heatmap_example} you can clearly see the different elements of this dashboard page. up top there is the Cosy Cafeteria title with the menu to navigate all the different pages below it.
Under this menu is where the actual data is displayed on the floor plan of the cafeteria. This floor plan is loaded in as an image that is used as background to draw the heatmap over.
For the heatmap a javascript library is used called heatmap.js \cite{heatmap.js}, this library makes it easy to add the data points with there value and location and draw them on top of the floor plan.
It also draws a legend in the bottom right corner.
\begin{figure}[H]
	\centering
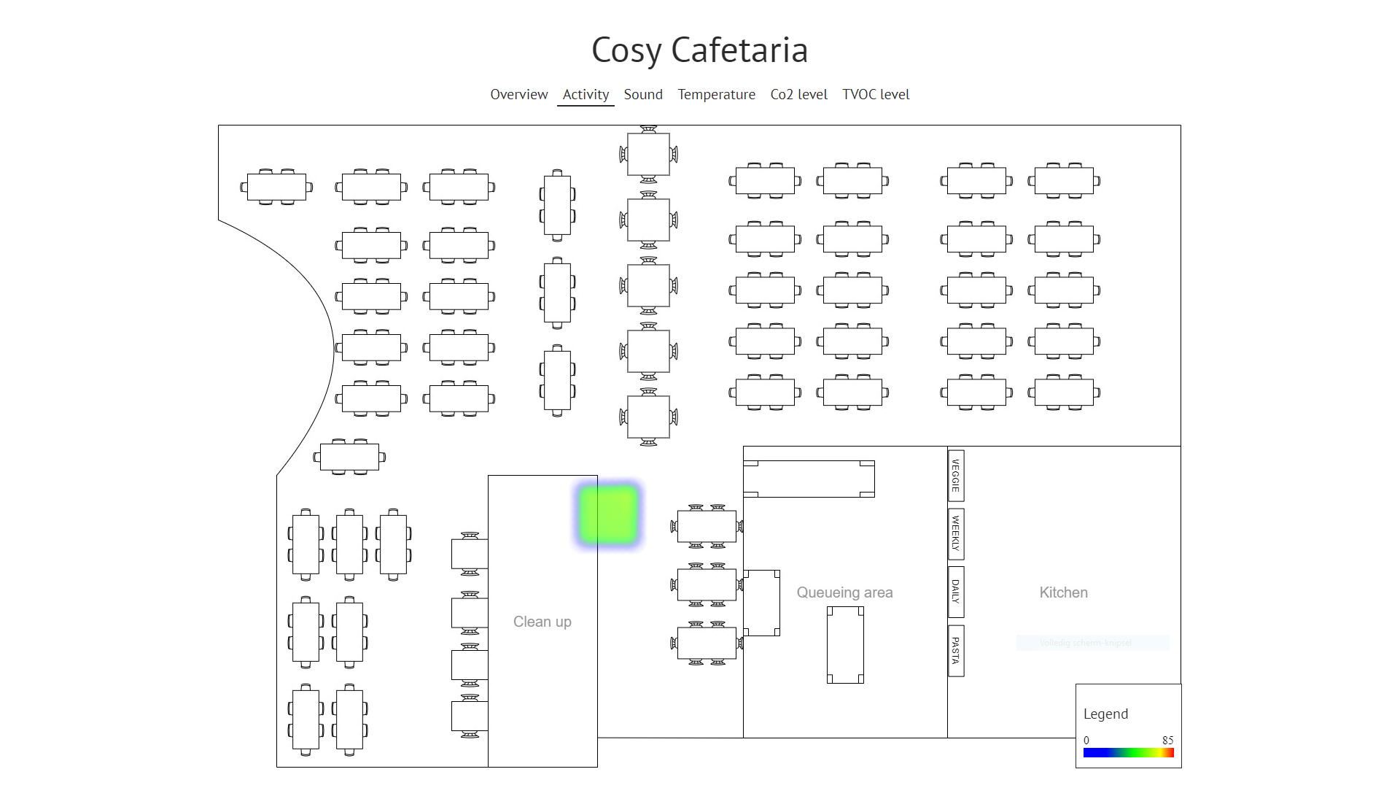
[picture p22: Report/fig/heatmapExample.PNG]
	
	\caption{Screenshot from the activity page}
	\label{fig:heatmap_example}
\end{figure}
If the cafeteria would be fully equipped with our sensornodes a completer map could be drawn on which you could clearly see the heat signature of every person in the cafeteria.
This would make it easy to see if your favourite spot was still available or not and how busy it is in the queue.
\\
On the other pages of the dashboard the other sensor data is displayed in the same way. 
The temperature data would make it easy to spot where it's is hotter or rather where it's colder.
Same goes for the other data that is collected by the sensornodes.

\section{Case Design}
\begin{figure}[H]
	\centering
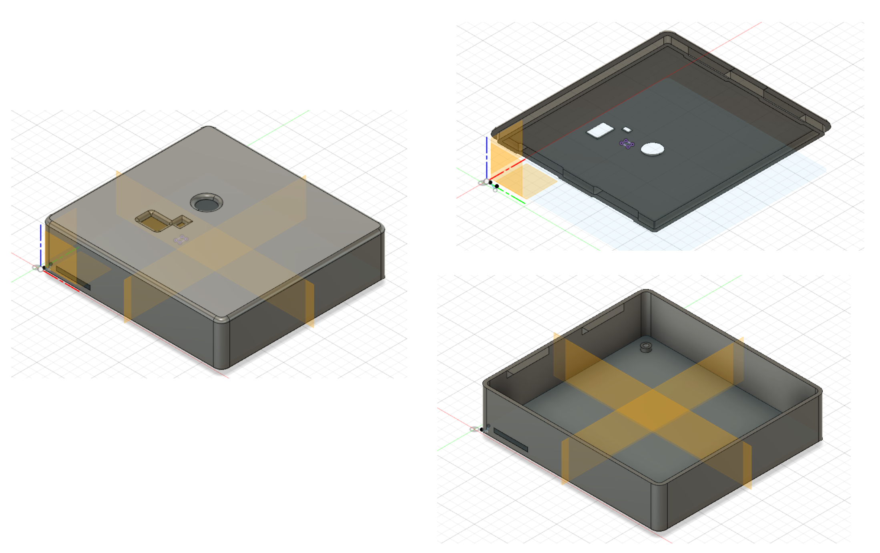
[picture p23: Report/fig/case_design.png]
	
	\caption{Case design different parts}
	\label{fig:case_design}
\end{figure}
For our system, we have designed a simple case with snapfits for building in the system, this is illustrated in figure \ref{fig:snapfits_total}. We have made the design with fusion 360. 
\begin{figure}[H]
	\centering
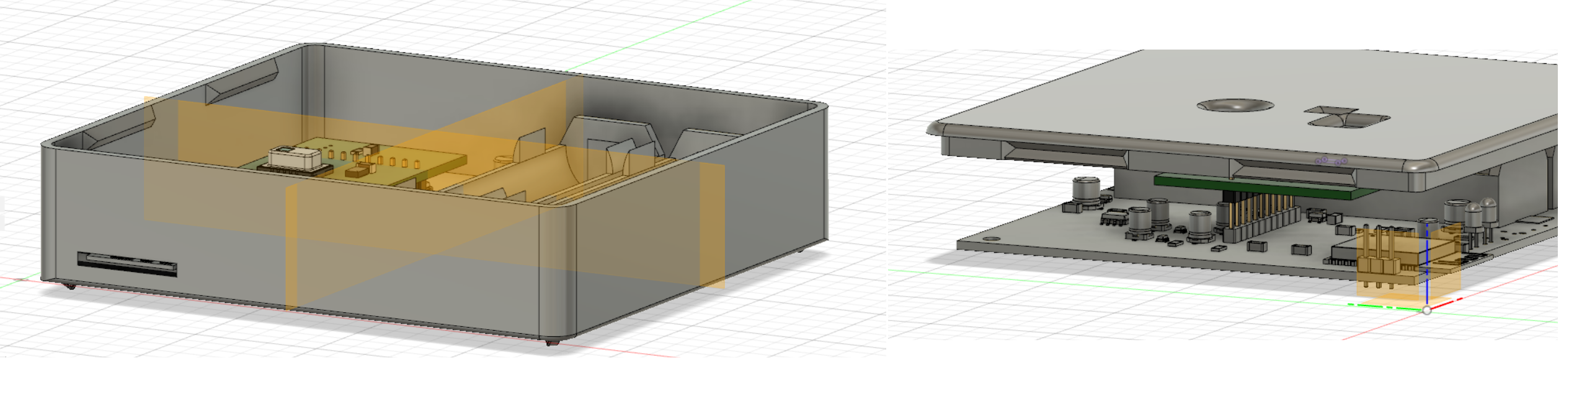
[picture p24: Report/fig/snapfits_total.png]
	
	\caption{Design with internal parts integrated}
	\label{fig:snapfits_total}
\end{figure}
This program has the ability to import different types of 3D-files, as can be seen in figure \ref{fig:electronic_system}. 
\begin{figure}[H]
	\centering
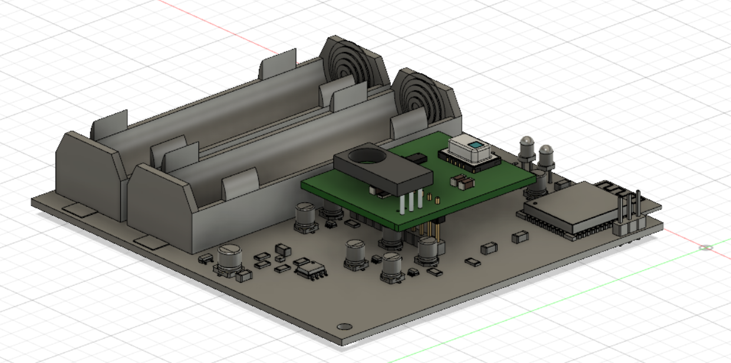
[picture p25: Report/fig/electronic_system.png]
	
	\caption{Individual parts imported in Fusion 360}
	\label{fig:electronic_system}
\end{figure}
By importing all our separate parts of the design and aligning them. We could make a case that fits with some holes so the sensors have an opening above them to measure the different parameters, as can be seen in figure \ref{fig:opening_sensors}. 
\begin{figure}[H]
	\centering
	
	\caption{Opening in cover for sensors}
	\label{fig:opening_sensors}
\end{figure}
There is also a slot for the Wi-Fi-antenna, this is visible in figure \ref{fig:snapfits_total}. This antenna is uncovered but the circuit is placed in such a way that the antenna is not coming outside of the case. This is to protected and expose it at the same time.
\\ \\
The design of the case is not a very complex design but there have been taken some important design considerations. For the opening above the AMG8833, we have made the opening a little bit wider so it will not cover parts of the field of view of the sensor (see figure \ref{fig:opening_sensors}). To instal the design to the ceiling, we have put four loops at the upper side of the case, as can be seen in figure \ref{fig:loops_hang_system}. With these loops the case can be fixed with a cable to the ceiling everywhere the systems needs to be installed at the chosen height.
\begin{figure}[H]
	\centering
	
	\caption{Loops for installing the system to the ceiling}
	\label{fig:loops_hang_system}
\end{figure}
\paragraph{Possible improvements}
The case could be made more closely to the internal parts. Specific at the AMG8833 and the CCS811. For the CCS811 this is not  really an issue because it is a gas sensor but for the AMG8833, the case could block the view of the sensor if the opening is not big enough. The weight distribution is not optimal, the batteries are at one side of the design, so the balance is not even spread through the design. This could result in a not perfect horizontal hanging case. We could adapt the string to balance out the weight so it will hang horizontal.

\section{Financial estimate}
The price of all the components used in this project is 71,70 Euro, this price can be found in the BOM in appendix~\ref{app:BOM}.
For the case we calculated the price of the print based on how much filament it would use to print it. It takes about 60 grams of filament and that would cost about 1 euro.
The price for both the pcb's is about 71,45 euro. The total estimated price for this project would be \euro 144,15. 

\section{Validation and testing}
In this section the different functionalities are validated. The aspects that couldn't be validated because of the lack of equipment during the corona pandemic are also discussed. 
\subsection{Successfully validated}
In order to validate the correct operation of the system a number of tests were performed. The system was tested on an ESP32-DEVKitC which is illustrated in figure~\ref{fig:devkit}.
\begin{figure}[H]
	\centering
	
	\caption{ESP32-DeVKit~\cite{devkit}}
	\label{fig:devkit}
\end{figure}
This devkit uses the same ESP32-SOLO-1 chip that is used in our design, which makes it perfect to test the software. Next to this devkit two breakout boards were used, namely a breakout board for the AMG8833 and one for the CCS811. Unfortunately no breakout board was available for the microphone, so this wasn't fully tested. 
\paragraph{AMG8833}
To verify the correct functionality of the AMG8833 the developed code was tested on the ESP32-DEVKitC, together with a breakout board for the AMG8833. When a heat source is brought closer to the sensor, it is clear that this is picked up by the sensor and correctly translated in a higher pixel value. This has already been discussed in section~\ref{sec:amg}. We can conclude that the AMG8833 functions correctly. 
\paragraph{CCS811}
To verify the correct functionality of the CCS811 the developed code was tested on the ESP32-DEVKitC, together with a breakout board for the CCS811. This sensor measures $CO_2$ levels and TVOC levels. To verify that the correct values are read out, a person exhaled on the sensor, this resulted in higher $CO_2$ and TVOC levels, as expected. This ensures that we can conclude that the sensor is working correctly
\paragraph{Microphone}
Unfortunately no breakout board was available for the microphone. However, the microphone produces an analog signal that has to be read out with the ADC of the ESP32. The correct operation of the ADC was tested by connecting an analog output pin of the ESP32 to the ADC of the ESP32. By setting a value on the output pin and registering the same value with the ADC, the correct functionality of the ADC was verified. Given that the developed sensorboard for the microphone produces a correct output signal, it can be read out correctly by the ESP23. 

\paragraph{Full system}
In order to test the full system, the final code was uploaded to the ESP32-DeVKitC. The devkit was connected to the AMG8833 and the CCS811 on a breadboard, the ADC pin for the microphone was left floating, because no microphone board was available. This was set up at one students house. Next to this a raspberry pi was setup in another students house, to act as the server which receives the sensor data and hosts the website. This setup was used to test the system for one full day. Every ten minutes the system correctly read out the sensors and successfully sent the data to the server that was running on the raspberry pi. On the server side the sensor values that were received, were then used to update the Mysql databases that stores the data. From this test we can conclude that the full system works correctly and can retrieve and send the sensor data every 10 minutes. \\

To verify the correct working of the NTP synchronisation and the use of the timing information, the system was tested for one full day. As expected, when it was 4 PM the system went to sleep for the night and raised the GPIO pins to disable the power to the sensors through the load switches. Unfortunately the final hardware wasn't available to test the correct functionality of the load switches. However, the correct functionality of the software can be assured. 

\subsection{To validate}
\paragraph{Hardware}
The hardware has been fully developed but unfortunately due to the corona pandemic, couldn't be verified. The main parts that need verification are:
\begin{itemize}
	\item Power management
	\item Correct functionality load switches
	\item Correct functionality sensor board
	\item Correct functionality ESP32
\end{itemize}

\paragraph{Power consumption}
The power consumption of the different sensors, Wi-Fi communication and NTP synchronisation could be verified by placing a one ohm resistor between the power supply and the devkit and measuring the voltage across this resistor. However, the stand-by/sleep consumption could not be verified because the devkit has an onboard LED which causes an additional consumption. Next to this, the measurement principle couldn't provide the necessary accuracy to measure \SI{}{\micro\ampere} currents, because there was a lot of noise present in the measurement. 

% bibliografie toevoegen
\newpage
\bibliography{bibliography}	

%----------------------------------------------------------------------------------------
%	Bijlagen
%----------------------------------------------------------------------------------------
\newpage
\appendix
\section{MainPCB schematic}\label{app:mainpcb_schematic}
%\begin{figure}[H]
%	\centering
%	\includegraphics[width=1\linewidth]{MainPCB_schematic.pdf}
%\end{figure}
\includepdf[pages=-,landscape=true]{fig/MainPCB_schematic.pdf}

\newpage

\section{Sensor board schematic}\label{app:sensorboard_schematic}
%\begin{figure}[H]
%	\centering
%	\includegraphics[width=1\linewidth]{schematic drawing sensorboard.pdf}
%\end{figure}
\includepdf[pages=-,landscape=true]{fig/schematic_drawing_sensorboard.pdf}
\newpage

\section{Pricing main PCB}\label{app:pricing main pcb}
%\begin{figure}[H]
%	\centering
%	\includegraphics[width=1\linewidth]{schematic drawing sensorboard.pdf}
%\end{figure}
\includepdf[pages=-]{fig/Pricing_information_PI-1200952.pdf}
\newpage

\section{pricing sensor PCB}\label{app:pricing sensor pcb}
%\begin{figure}[H]
%	\centering
%	\includegraphics[width=1\linewidth]{schematic drawing sensorboard.pdf}
%\end{figure}
\includepdf[pages=-]{fig/Pricing_information_PI-1200953.pdf}
\newpage

\section{BOM for main pcb and sensor pcb}\label{app:BOM}
%\begin{table}
 %   \centering
    \begin{longtable}{|p{.15\textwidth}|p{.15\textwidth}||p{.15\textwidth}|p{.15\textwidth}||p{.11\textwidth}|p{.09\textwidth}||p{.09\textwidth}|} %{\linewidth}{|X|X|X|X|X|X|X|}
    \hline
        Function & Description & Part No. & Package & Quantity & Prijs & Prijs tot \\ \hline
        Battery & 18650 Li-ion Batterij, 3350mAh & NCR18650B &  & 2 & \euro 4,95 & \euro 9,90 \\ \hline
        Battery holder & BATTERY HOLDER 18650 PC PIN & 534-1042P &  & 2 & \euro 2,17 & \euro 4,34 \\ \hline
        Power management & Charger chip & BQ24075 RGTR & VQFN-16 & 1 & \euro 1,99 & \euro 1,99 \\ \hline
         & Protection IC & BQ29700 DSER & WSON-6 & 1 & \euro 0,60 & \euro 0,60 \\ \hline
         & Dual N-channel MOSFETs & 512-FDS9926A & 8-SOIC & 1 & \euro 0,54 & \euro 0,54 \\ \hline
         & LDO 3,3V 500 mA & TLV75533 PDBVR & SOT23-5 & 1 & \euro 0,56 & \euro 0,56 \\ \hline
        Micro USB  B &  & Wurth 629105 150521 &  & 1 & \euro 1,89 & \euro 1,89 \\ \hline
        Reverse polarity protection & PMOS & NTR2101 PT1G & SOT-23-3 & 1 & \euro 0,33 & \euro 0,33 \\ \hline
        Load switch &  & TPS22919 DCKT &  & 3 & \euro 0,38 & \euro 1,14 \\ \hline
        Microfoon & BOB-09964  & BOB-12758 & Eval bord & 1 & \euro 6,26 & \euro 6,26 \\ \hline
        Air quality sensor  & CCS-811 & CCS811B-JOPR5K & LGA & 1 & \euro 10,17 & \euro 10,17 \\ \hline
        IR sensor & AMG8833 & AMG8833  &  & 1 & \euro 27,04 & \euro 27,04 \\ \hline
        Shottkey-diode & RB081LAM-20 & RB081LAM-20 & SOD-128 & 1 & \euro 0,35 & \euro 0,35 \\ \hline
        Microcontroller + WiFi module & ESP32 & ESP32-SOLO-1 &  & 1 & \euro 3,06 & \euro 3,06 \\ \hline
        Buttons &  & 430481 035816 &  & 2 & \euro 0,46 & \euro 0,92 \\ \hline
        Inverter & Unbuffered inverter interrupt CCS811 & NC7SV U04P5X & SC-70 & 1 & \euro 0,42 & \euro 0,42 \\ \hline
        Thermistor & 100kOhm thermistor & NCU18WF1 04D60RB & 1608 & 1 & \euro 0,30 & \euro 0,30 \\ \hline
        Blue led &  & TLHB44 K2M1 & TH & 1 & \euro 0,92 & \euro 0,92 \\ \hline
        Green led &  & TLHG4 4K1L2 & TH & 1 & \euro 0,52 & \euro 0,52 \\ \hline
        11 Pin header &  &  & TH & 2 & \euro 0,32 & \euro 0,64 \\ \hline
        11 jumper wires female-female &  &  &  &  &  & \euro 0,00 \\ \hline
        Resistors (main board) & 22 Ohm & CRCW 12062 2R0FKEAC & 1206 & 1 & \euro 0,09 & \euro 0,09 \\ \hline
         & 330 &  & 1206 & 1 & \euro 0,09 & \euro 0,09 \\ \hline
         & 680 &  & 1206 & 4 & \euro 0,09 & \euro 0,36 \\ \hline
         & 1,1k &  & 1206 & 1 & \euro 0,09 & \euro 0,09 \\ \hline
         & 1,5k &  & 1206 & 2 & \euro 0,09 & \euro 0,18 \\ \hline
         & 2,2k &  & 1206 & 1 & \euro 0,09 & \euro 0,09 \\ \hline
         & 4,7 kOhm & CRCW12 064K70 FKEAC & 1206 & 1 & \euro 0,09 & \euro 0,09 \\ \hline
         & 10k &  & 1206 & 6 & \euro 0,09 & \euro 0,54 \\ \hline
         & 47k &  & 1206 & 1 & \euro 0,09 & \euro 0,09 \\ \hline
         & 100 kOhm & CRCW1206 100KFKEAC  & 1206 & 4 & \euro 0,09 & \euro 0,36 \\ \hline
         & 5 Meg &  & 1206 & 2 & \euro 0,09 & \euro 0,18 \\ \hline
        Pol Capacitors (main board) & 47u/16V & EDK476 M016A 9DAA & 5x5,4mm & 2 & \euro 0,23 & \euro 0,46 \\ \hline
         & 10u/16V & EDH106M0 16A9BAA & 4x5,4mm & 4 & \euro 0,22 & \euro 0,88 \\ \hline
         & 3,3u/16V & 710-86525034 0001 & 4x5,5mm & 3 & \euro 0,24 & \euro 0,72 \\ \hline
        Capacitors & 100 nF & GRM319R7 2A104K A01D & 1206 & 5 & \euro 0,35 & \euro 1,75 \\ \hline
         & 1 $\mu$F & GRM31M R71C105 KA01L & 1206 & 5 & \euro 0,26 & \euro 1,31 \\ \hline
         & 2,2 $\mu$F & GRM31MR 71C225 KA35L & 1206 & 1 & \euro 0,30 & \euro 0,30 \\ \hline
         & 4,7 $\mu$F & GRM31C R61A475 KA01L & 1206 & 3 & \euro 0,37 & \euro 1,11 \\ \hline
         & 10 $\mu$F & GRM319 C81C106M A12J & 1206 & 1 & \euro 0,28 & \euro 0,28 \\ \hline
         & 47u/10V X5R & GRM31CR 61A476 ME15L & 1206 & 1 & \euro 0,76 & \euro 0,76 \\ \hline
         &  &  &  &  &  &  \\ \hline
         &  &  &  &  & Tot: & \euro 71,70 \\ \hline
    \end{longtable}
%\end{table}
\end{document}

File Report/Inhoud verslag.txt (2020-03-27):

afmetingen print moet kleiner zijn dan 100x100mm

Inhoud verslag:
 - wat gaat uw systeem juist doen
 - functionaliteit
 - opgebouwd
 - bespreking
 - energiebeheer - autonomiteit
 - manier om aan te tonen dat het werkt - metingen
 - url's github
 - financiële schatting

Tonen dat je hebt nagedacht over dimensionering componenten.

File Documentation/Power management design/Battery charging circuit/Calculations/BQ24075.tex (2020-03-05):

\documentclass{article}
\usepackage[utf8]{inputenc}
\usepackage{graphicx}
\graphicspath{ {./fig/} }

\title{Calculations BQ24075}
\author{Tobias Cromheecke}

\begin{document}
\maketitle

\section{Charging}
Set $\overline{CE}$ low to initiate battery charging. The battery is charged in three phases: 
\begin{enumerate}
\item Conditioning pre-charge
\item Constant current fast charge (current regulation) 
\item Constant voltage tapering (voltage regulation)
\end{enumerate}
\begin{figure}[!ht]
	\centering
	
	\caption{Charge cycle}
	\label{fig:Charge _cycle}
\end{figure}
In the pre-charge phase, the battery is charged at with the pre-charge current $I_{PRECHG}$. Once the battery voltage crosses the $V_{LOWV}$ threshold, the battery is charged with the fast-charge current $I_{CHG}$. As the battery voltage reaches $V_{BAT(REG)}$, the battery is held at a constant voltage of $V_{BAT(REG)}$ and the charge current tapers off as the battery approaches full charge. When the battery current reaches $I_{TERM}$, the CHG pin indicates charging done by going high-impedance.

The value of the fast-charge current is set by the resistor connected from the ISET pin to VSS, and is given by the equation:
\[ I_{CHG} = \frac{K_{ISET}}{R_{ISET}} \]
The charge current limit is adjustable up to 1.5 A. The valid resistor range is 590 $\Omega$ to 8.9 k$\Omega$. If $I_{CHG}$ is programmed as greater than the input current limit, the battery will not charge at the rate of $I_{CHG}$, but at the slower rate of $I_{IN(MAX)}$ (minus the load current on the OUT pin, if any). In this case, the charger timers will be proportionately slowed down.

\subsection{Charge Current Translator}
When the charger is enabled, internal circuits generate a current proportional to the charge current at the ISET input. The current out of $I_{SET}$ is 1/400 ($\pm$10\%) of the charge current. This current, when applied to the external charge current programming resistor, $R_{ISET}$, generates an analog voltage that can be monitored by an external host to calculate the current sourced from BAT.
\[ V_{ISET} = \frac{I_{CHG}}{400} R_{ISET} \]

\section{System enable input}
Connect SYSOFF high to turn off the FET connecting the battery to the system output. When an adapter is connected, charging is also disabled. Connect SYSOFF low for normal operation. SYSOFF is internally pulled up to VBAT through a large resistor (approximately 5 M$\Omega$). Do not leave SYSOFF unconnected to ensure proper operation.
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

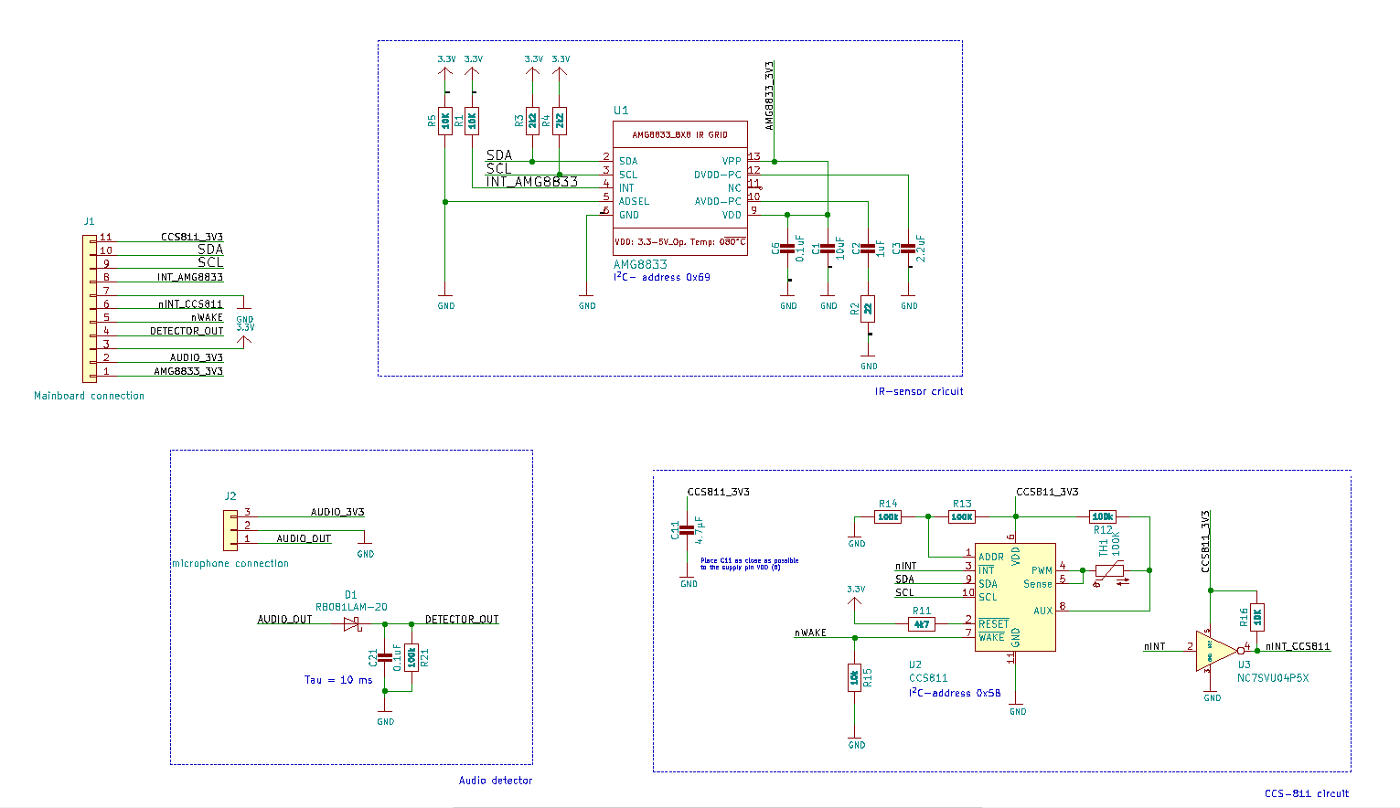
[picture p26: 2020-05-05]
Report/fig/Schematic sensor board.png

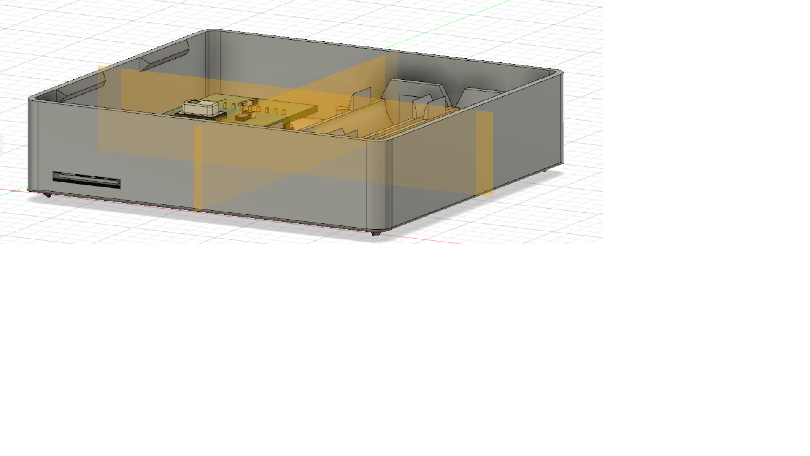
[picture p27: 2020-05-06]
Report/fig/snapfits_case_opening_wifiantenne.png

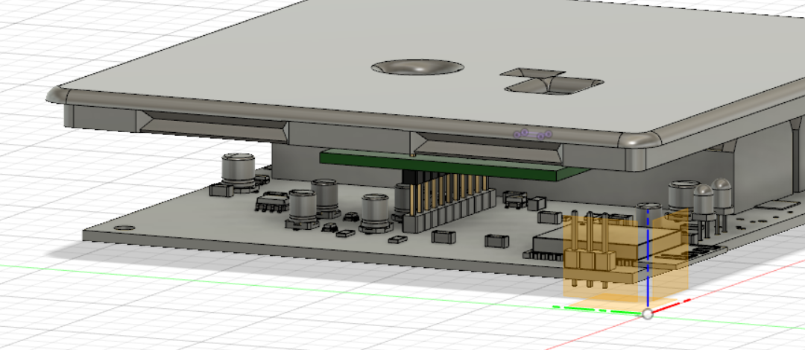
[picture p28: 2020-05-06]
Report/fig/snapfits.png

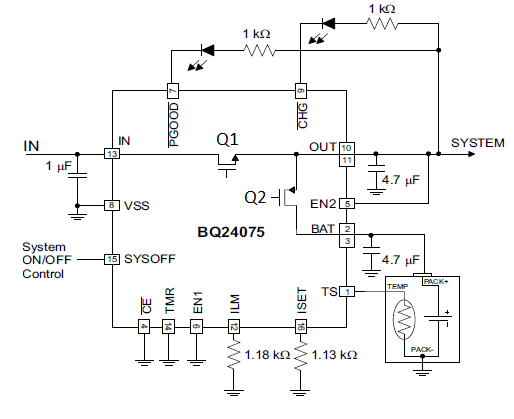
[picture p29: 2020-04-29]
Report/fig/bq24075_principeschema.png

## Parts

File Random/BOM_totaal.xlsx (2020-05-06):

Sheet: Blad1
Function | Description | Part No. | Package | Quantity | Prijs | Prijs tot | link
Battery | 18650 Li-ion Batterij, 3350mAh | NCR18650B |  | 2 | €4.95 | €9.90 | https://www.tinytronics.nl/shop/nl/batterij-en-accu/18650/panasonic-18650-li-ion-batterij-3350mah-6.7a-ncr18650b
 |  |  |  |  | battery is too expensive on farnell and digi-key (30 euro) | #VALUE!
Battery holder | BATTERY HOLDER 18650 PC PIN | 534-1042P |  | 2 | €2.17 | €4.34 | https://www.mouser.be/ProductDetail/Keystone-Electronics/1042P
Power management | Charger chip | BQ24075RGTR | VQFN-16 | 1 | €1.99 | €1.99 | https://www.mouser.be/ProductDetail/Texas-Instruments/BQ24075RGTR
 | Protection IC | BQ29700DSER | WSON-6 | 1 | €0.60 | €0.60 | https://www.mouser.be/ProductDetail/Texas-Instruments/BQ29700DSER
 | Dual N-channel MOSFETs | 512-FDS9926A | 8-SOIC | 1 | €0.54 | €0.54 | https://www.mouser.be/ProductDetail/ON-Semiconductor-Fairchild/FDS9926A
 | LDO 3,3V 500 mA | TLV75533PDBVR | SOT23-5 | 1 | €0.56 | €0.56 | https://www.mouser.be/ProductDetail/Texas-Instruments/TLV75533PDBVR
Micro USB B |  | Wurth 629105150521 |  | 1 | €1.89 | €1.89 | https://www.mouser.be/ProductDetail/Wurth-Elektronik/629105150521
Reverse polarity protection | PMOS | NTR2101PT1G | SOT-23-3 | 1 | €0.33 | €0.33 | https://www.mouser.be/ProductDetail/ON-Semiconductor/NTR2101PT1G?qs=sGAEpiMZZMtqO%252BWUGLBzeMZnYjT0HBB3
Load switch |  | TPS22919DCKT |  | 3 | €0.38 | €1.14 | https://www.mouser.be/ProductDetail/Texas-Instruments/TPS22919DCKT
Microfoon | BOB-09964 | BOB-12758 | Eval bord | 1 | €6.26 | €6.26 | https://www.mouser.be/ProductDetail/SparkFun/BOB-12758
Air quality sensor | CCS-811 | CCS811B-JOPR5K | LGA | 1 | €10.17 | €10.17 | https://www.mouser.be/ProductDetail/ams/CCS811B-JOPR5K
IR sensor | AMG8833 | AMG8833 |  | 1 | €27.04 | €27.04 | https://www.mouser.be/Search/Refine?Keyword=AMG8833
Shottkey-diode | RB081LAM-20 | RB081LAM-20 | SOD-128 | 1 | €0.35 | €0.35 | https://www.mouser.be/ProductDetail/ROHM-Semiconductor/RB081LAM-20TR
Microcontroller + WiFi module | ESP32 | ESP32-SOLO-1 |  | 1 | €3.06 | €3.06 | https://www.mouser.be/ProductDetail/Espressif-Systems/ESP32-SOLO-1
Buttons |  | 430481035816 |  | 2 | €0.46 | €0.92 | https://www.mouser.be/ProductDetail/Wurth-Elektronik/430481035816
Inverter | Unbuffered inverter interrupt CCS811 | NC7SVU04P5X | SC-70 | 1 | €0.42 | €0.42 | https://www.mouser.be/ProductDetail/ON-Semiconductor-Fairchild/NC7SVU04P5X?qs=38EqnX883HDDLypsSV1NLg==
Thermistor | 100kOhm thermistor | NCU18WF104D60RB | 1608 | 1 | €0.30 | €0.30 | https://www.mouser.be/ProductDetail/Murata-Electronics/NCU18WF104D60RB
Blue led |  | TLHB44K2M1 | TH | 1 | €0.92 | €0.92 | https://www.mouser.be/ProductDetail/Vishay-Semiconductors/TLHB44K2M1
Green led |  | TLHG44K1L2 | TH | 1 | €0.52 | €0.52 | https://www.mouser.be/ProductDetail/Vishay-Semiconductors/TLHG44K1L2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
11 Pin header |  |  | TH | 2 | €0.32 | €0.64 | https://www.mouser.be/ProductDetail/Harwin/M20-9771146
11 jumper wires female-female |  |  |  |  |  | €0.00
Resistors (main board) | 22 Ohm | CRCW120622R0FKEAC | 1206 | 1 | €0.09 | €0.09 | https://www.mouser.be/ProductDetail/Vishay-Dale/CRCW060322R0FKEAC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
 | 330 |  | 1206 | 1 | €0.09 | €0.09 | https://www.mouser.be/ProductDetail/Vishay-Dale/CRCW1206330RFKEA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
 | 680 |  | 1206 | 4 | €0.09 | €0.36 | https://www.mouser.be/ProductDetail/Vishay-Dale/CRCW1206680RJNEAIF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
 | 1,1k |  | 1206 | 1 | €0.09 | €0.09 | https://www.mouser.be/ProductDetail/Vishay-Dale/CRCW12061K10FKEA
 | 1,5k |  | 1206 | 2 | €0.09 | €0.18 | https://www.mouser.be/ProductDetail/Vishay-Dale/CRCW12061K50FKEAC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
 | 2,2k |  | 1206 | 1 | €0.09 | €0.09 | https://www.mouser.be/ProductDetail/Vishay-Dale/CRCW12062K20FKEAC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
 | 4,7 kOhm | CRCW12064K70FKEAC | 1206 | 1 | €0.09 | €0.09 | https://www.mouser.be/ProductDetail/Vishay-Dale/CRCW06034K70FKEAC
 | 10k |  | 1206 | 6 | €0.09 | €0.54 | https://www.mouser.be/ProductDetail/Vishay-Dale/CRCW120610K0FKEAC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
 | 47k |  | 1206 | 1 | €0.09 | €0.09 | https://www.mouser.be/ProductDetail/Vishay-Dale/CRCW120647K0FKEAC
 | 100 kOhm | CRCW1206100KFKEAC | 1206 | 4 | €0.09 | €0.36 | https://www.mouser.be/ProductDetail/Vishay-Dale/CRCW1206100KFKEAC
 | 5 Meg |  | 1206 | 2 | €0.09 | €0.18 | https://www.mouser.be/ProductDetail/Vishay-Dale/CRCW12064M99FKEA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
Pol Capacitors (main board) | 47u/16V | EDK476M016A9DAA | 5x5,4mm | 2 | €0.23 | €0.46 | https://www.mouser.be/ProductDetail/KEMET/EDK476M016A9DAA
 | 10u/16V | EDH106M016A9BAA | 4x5,4mm | 4 | €0.22 | €0.88 | https://www.mouser.be/ProductDetail/KEMET/EDH106M016A9BAA
 | 3,3u/16V | 710-865250340001 | 4x5,5mm | 3 | €0.24 | €0.72 | https://www.mouser.be/ProductDetail/Wurth-Elektronik/865250340001
Capacitors | 100 nF | GRM319R72A104KA01D | 1206 | 5 | €0.35 | €1.75 | https://www.mouser.be/ProductDetail/Murata-Electronics/GRM319R72A104KA01D
 | 1 µF | GRM31MR71C105KA01L | 1206 | 5 | €0.26 | €1.31 | https://www.mouser.be/ProductDetail/Murata-Electronics/GRM31MR71C105KA01L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
 | 2,2 µF | GRM31MR71C225KA35L | 1206 | 1 | €0.30 | €0.30 | https://www.mouser.be/ProductDetail/Murata-Electronics/GRM31MR71C225KA35L
 | 4,7 µF | GRM31CR61A475KA01L | 1206 | 3 | €0.37 | €1.11 | https://www.mouser.be/ProductDetail/Murata-Electronics/GRM31CR61A475KA01L
 | 10 µF | GRM319C81C106MA12J | 1206 | 1 | €0.28 | €0.28 | https://www.mouser.be/ProductDetail/Murata-Electronics/GRM319C81C106MA12J
 | 47u/10V X5R | GRM31CR61A476ME15L | 1206 | 1 | €0.76 | €0.76 | https://www.mouser.be/ProductDetail/Murata-Electronics/GRM31CR61A476ME15L
 |  |  |  |  | Tot: | €71.70

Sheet: niet nodig normaal
TS321 | 1 | TS321IDBVRE4 | SOT23-5 | €0.70 | https://www.mouser.be/ProductDetail/Texas-Instruments/TS321IDBVRE4
CMA-4544PF-W | 1 | CMA-4544PF-W | microfoon | €0.70 | https://www.digikey.be/product-detail/en/cui-devices/CMA-4544PF-W/102-1721-ND/1869981

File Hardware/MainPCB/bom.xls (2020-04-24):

Index | Reference | Value | Footprint | Count | Rating | PartNumber | Description
1 | U2 | BQ29700 | WSON-6_1.5x1.5mm_P0.5mm | 1
2 | Q2 | FDS9926A | SOIC-8_3.9x4.9mm_P1.27mm | 1
3 | R3,R12,R13,R14 | 680 | R_1206_3216Metric_Pad1.42x1.75mm_HandSolder | 4
4 | R6,R5 | 1.5k | R_1206_3216Metric_Pad1.42x1.75mm_HandSolder | 2
5 | U1 | BQ24075 | VQFN-16-1EP_3x3mm_P0.5mm_EP1.6x1.6mm | 1
6 | D1 | LED_Green | LED_D3.0mm | 1
7 | D2 | LED_Blue | LED_D3.0mm | 1
8 | BT1,BT2 | Li-ion | BatteryHolder_Keystone_1042_1x18650 | 2
9 | R1 | 1.1k | R_1206_3216Metric_Pad1.42x1.75mm_HandSolder | 1
10 | R4,R11 | 10k | R_1206_3216Metric_Pad1.42x1.75mm_HandSolder | 2
11 | C3,C1,C9,C6 | 1u | C_1206_3216Metric_Pad1.42x1.75mm_HandSolder | 4
12 | C8,C13,C11,C20 | 0.1u | C_1206_3216Metric_Pad1.42x1.75mm_HandSolder | 4
13 | R7 | 330 | R_1206_3216Metric_Pad1.42x1.75mm_HandSolder | 1
14 | C5,C4 | 4.7u | C_1206_3216Metric_Pad1.42x1.75mm_HandSolder | 2
15 | R8 | 2.2k | R_1206_3216Metric_Pad1.42x1.75mm_HandSolder | 1
16 | U3 | TLV75533PDBV | SOT-23-5 | 1
17 | C10 | 47u/10V | C_1206_3216Metric_Pad1.42x1.75mm_HandSolder | 1
18 | C2,C7 | 47u/16V | CP_Elec_5x5.4 | 2
19 | R9,R10 | Meg" | R_1206_3216Metric_Pad1.42x1.75mm_HandSolder | 2
20 | J1 | USB_B_Micro | USB_Micro-B_Wuerth_629105150521 | 1
21 | Q1 | NTR2101P | SOT-23 | 1
22 | R2 | 47k | R_1206_3216Metric_Pad1.42x1.75mm_HandSolder | 1
23 | JP1 | Stroommeetdraad | Wire | 1
24 | U5,U6,U7 | TPS22919 | SOT-363_SC-70-6 | 3
25 | C14,C16,C17 | 3.3u/16V | CP_Elec_4x5.4 | 3
26 | C15,C12,C18,C19 | 10u/16V | CP_Elec_4x5.4 | 4
27 | U4 | ESP32-WROOM-32D | ESP32-WROOM-32 | 1
28 | EN1,BOOT1 | SW_DIP_x01 | SW_Push_1P1T_NO_6x6mm_H9.5mm | 2
29 | J3 | UART | PinHeader_1x03_P2.54mm_Vertical | 1
30 | J2 | Conn_01x11 | PinHeader_1x11_P2.54mm_Vertical | 1

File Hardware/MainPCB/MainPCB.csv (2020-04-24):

Id | Designator | Package | Quantity | Designation | Supplier and ref
1 | REF**,REF** | MountingHole_3.2mm_M3 | 2 | MountingHole_3.2mm_M3
2 | U4 | ESP32-WROOM-32 | 1 | ESP32-WROOM-32D
3 | C20,C13,C11,C8 | C_1206_3216Metric_Pad1.42x1.75mm_HandSolder | 4 | 0.1u
4 | J2 | PinHeader_1x11_P2.54mm_Vertical | 1 | Conn_01x11
5 | BT1,BT2 | BatteryHolder_Keystone_1042_1x18650 | 2 | Li-ion
6 | J1 | USB_Micro-B_Wuerth_629105150521 | 1 | USB_B_Micro
7 | U1 | VQFN-16-1EP_3x3mm_P0.5mm_EP1.6x1.6mm | 1 | BQ24075
8 | U7,U6,U5 | SOT-363_SC-70-6 | 3 | TPS22919
9 | R14,R13,R12,R3 | R_1206_3216Metric_Pad1.42x1.75mm_HandSolder | 4 | 680
10 | C19,C18,C15,C12 | CP_Elec_4x5.4 | 4 | 10u/16V
11 | C17,C16,C14 | CP_Elec_4x5.4 | 3 | 3.3u/16V
12 | C7,C2 | CP_Elec_5x5.4 | 2 | 47u/16V
13 | JP1 | Wire | 1 | Stroommeetdraad
14 | D2 | LED_D3.0mm | 1 | LED_Blue
15 | D1 | LED_D3.0mm | 1 | LED_Green
16 | U3 | SOT-23-5 | 1 | TLV75533PDBV
17 | U2 | WSON-6_1.5x1.5mm_P0.5mm | 1 | BQ29700
18 | R11,R4 | R_1206_3216Metric_Pad1.42x1.75mm_HandSolder | 2 | 10k
19 | R10,R9 | R_1206_3216Metric_Pad1.42x1.75mm_HandSolder | 2 | 5 Meg
20 | R8 | R_1206_3216Metric_Pad1.42x1.75mm_HandSolder | 1 | 2.2k
21 | R7 | R_1206_3216Metric_Pad1.42x1.75mm_HandSolder | 1 | 330
22 | R6,R5 | R_1206_3216Metric_Pad1.42x1.75mm_HandSolder | 2 | 1.5k
23 | R2 | R_1206_3216Metric_Pad1.42x1.75mm_HandSolder | 1 | 47k
24 | R1 | R_1206_3216Metric_Pad1.42x1.75mm_HandSolder | 1 | 1.1k
25 | Q2 | SOIC-8_3.9x4.9mm_P1.27mm | 1 | FDS9926A
26 | Q1 | SOT-23 | 1 | NTR2101P
27 | J3 | PinHeader_1x03_P2.54mm_Vertical | 1 | UART
28 | EN1,BOOT1 | SW_Push_1P1T_NO_6x6mm_H9.5mm | 2 | SW_DIP_x01
29 | C10 | C_1206_3216Metric_Pad1.42x1.75mm_HandSolder | 1 | 47u/10V
30 | C9,C6,C3,C1 | C_1206_3216Metric_Pad1.42x1.75mm_HandSolder | 4 | 1u
31 | C5,C4 | C_1206_3216Metric_Pad1.42x1.75mm_HandSolder | 2 | 4.7u

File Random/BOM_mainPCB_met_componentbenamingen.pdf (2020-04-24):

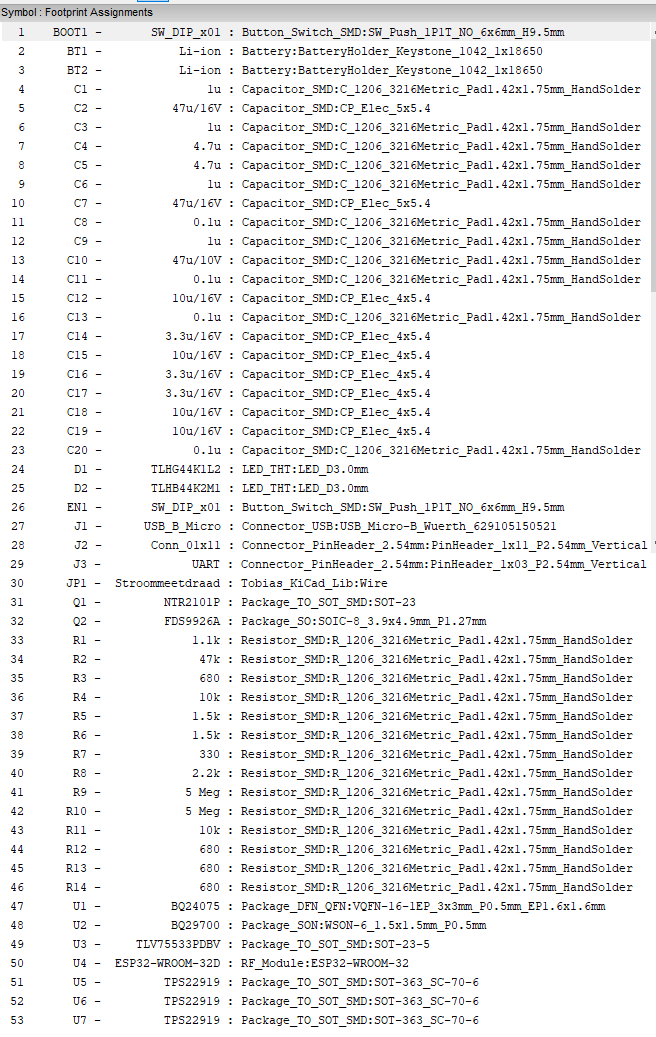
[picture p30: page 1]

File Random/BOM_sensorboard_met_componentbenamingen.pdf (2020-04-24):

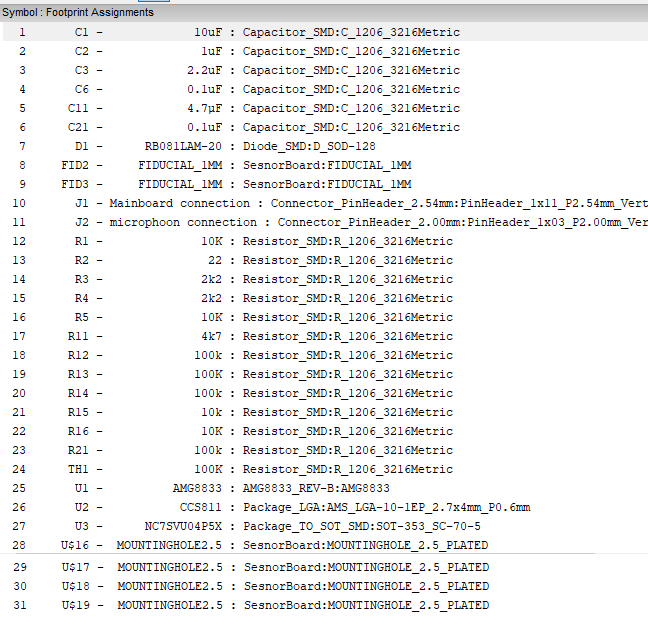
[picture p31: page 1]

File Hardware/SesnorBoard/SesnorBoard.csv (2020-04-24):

Id | Designator | Package | Quantity | Designation | Supplier and ref
1 | J1 | PinHeader_1x11_P2.54mm_Vertical | 1 | Mainboard connection
2 | U1 | AMG8833 | 1 | AMG8833
3 | C3 | C_1206_3216Metric | 1 | 2.2uF
4 | R2 | R_1206_3216Metric | 1 | 22
5 | D1 | D_SOD-128 | 1 | RB081LAM-20
6 | R16,R5,R1 | R_1206_3216Metric | 3 | 10K
7 | C2 | C_1206_3216Metric | 1 | 1uF
8 | R15 | R_1206_3216Metric | 1 | 10k
9 | C6,C21 | C_1206_3216Metric | 2 | 0.1uF
10 | U2 | AMS_LGA-10-1EP_2.7x4mm_P0.6mm | 1 | CCS811
11 | R21,R14,R12 | R_1206_3216Metric | 3 | 100k
12 | R13,TH1 | R_1206_3216Metric | 2 | 100K
13 | R11 | R_1206_3216Metric | 1 | 4k7
14 | C11 | C_1206_3216Metric | 1 | 4.7µF
15 | C1 | C_1206_3216Metric | 1 | 10uF
16 | U3 | SOT-353_SC-70-5 | 1 | NC7SVU04P5X
17 | R3,R4 | R_1206_3216Metric | 2 | 2k2
18 | J2 | PinHeader_1x03_P2.00mm_Vertical | 1 | microphoon connection

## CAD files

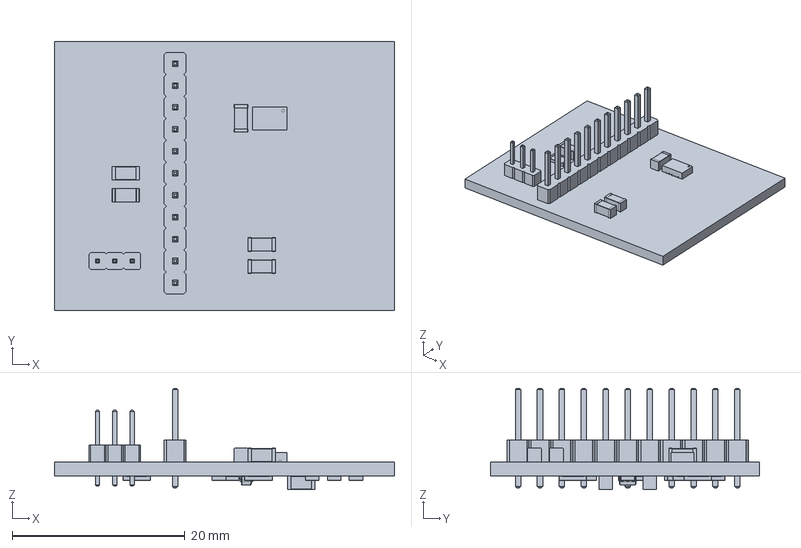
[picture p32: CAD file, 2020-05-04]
Hardware/SesnorBoard/sensorboard.iges
39.4 x 31.1 x 11.7 mm

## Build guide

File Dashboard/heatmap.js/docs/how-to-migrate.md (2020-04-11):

# How to migrate from heatmap.js v1.0 to v2.0

This document will describe the major public API changes and how you have to adapt your code to make your project work with heatmap.js v2.0

## element -> container
I thought this would describe the config property better, now the element property should be called container property:

```javascript

var cfg = {
   "container": domElement
};

```

## opacity -> maxOpacity
With the new heatmap.js v2.0 the opacity config property is affecting the global opacity (it sets the opacity for all datapoints and prevents smooth gradients). If you want to achieve smooth datapoint gradients you now have to use the maxOpacity config property:

```javascript

var cfg = {
   "maxOpacity": .8
}
```

Also, opacity, maxOpacity, and minOpacity should now be a decimal number within [0,1].

## Feeding heatmap.js with data

I decided to reduce the API to a more flat structure. That means you don't have to access the datastore of a heatmap to add the data but rather can add the new data directly at your heatmap instance. I also got rid of naming redundance ( `heatmap.store.addDataPoint` -> `heatmap.addData`, `heatmap.store.setDataSet` -> `heatmap.setData`).

```javascript
var datapoint = { x: 100, y: 100, value: 10 };

heatmap.addData(datapoint);

heatmap.setData({
   max: 10,
   data: [datapoint]
});
```

Also, as you probably have noticed: the count property of a datapoint is now called value by default BUT for migration sake you can tell heatmap.js to use "count" as a valueField:

```javascript
var datapoint = { x: 100, y: 100, count: 10 };

var heatmap = h337.create({
   container: domElement,
   // ...
   valueField: 'count'
});

heatmap.addData(datapoint);

heatmap.setData({
   max: 10,
   data: [datapoint]
});
```

---

# Summary

Old configuration example:

```javascript

var cfg = {
   "element": domElement,
   "opacity": 80
}

var heatmap = h337.create(cfg);

heatmap.store.setDataSet(data);
```

turns into new configuration:

```javascript

var cfg = {
   "container": domElement,
   "maxOpacity": .8
}

var heatmap = h337.create(cfg);

heatmap.setData(data);
```

Have a look at the documentation (it's inside the repo at /docs/) to see the full API

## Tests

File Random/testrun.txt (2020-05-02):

ets Jun  8 2016 00:22:57

rst:0x1 (POWERON_RESET),boot:0x13 (SPI_FAST_FLASH_BOOT)
configsip: 0, SPIWP:0xee
clk_drv:0x00,q_drv:0x00,d_drv:0x00,cs0_drv:0x00,hd_drv:0x00,wp_drv:0x00
mode:DIO, clock div:2
load:0x3fff0018,len:4
load:0x3fff001c,len:1044
load:0x40078000,len:8896
load:0x40080400,len:5828
entry 0x400806ac
Wakeup was not caused by deep sleep
E (133) gpio: gpio_set_intr_type(102): GPIO interrupt type error
IN SYNC
Connecting to telenet-F0116 .. CONNECTED
Thursday, April 30 2020 15:02:56
IN WAKESENSORS
Try to initialize CCS811
Going to sleep...
ets Jun  8 2016 00:22:57

rst:0x5 (DEEPSLEEP_RESET),boot:0x13 (SPI_FAST_FLASH_BOOT)
configsip: 0, SPIWP:0xee
clk_drv:0x00,q_drv:0x00,d_drv:0x00,cs0_drv:0x00,hd_drv:0x00,wp_drv:0x00
mode:DIO, clock div:2
load:0x3fff0018,len:4
load:0x3fff001c,len:1044
load:0x40078000,len:8896
load:0x40080400,len:5828
entry 0x400806ac
Wakeup caused by timer
E (133) gpio: gpio_set_intr_type(102): GPIO interrupt type error
IN READSENSORS
Try to initialize CCS811
audio voltage: 0.04
AMG pixels: 
20.25 : 21.00 : 19.75 : 20.25 : 20.25 : 20.50 : 20.25 : 20.50 : 19.75 : 21.25 : 22.50 : 22.00 : 21.00 : 19.75 : 20.25 : 20.50 : 19.25 : 19.75 : 19.50 : 20.50 : 21.50 : 20.25 : 19.75 : 19.50 : 20.25 : 19.75 : 19.50 : 19.75 : 19.75 : 20.25 : 19.75 : 19.25 : 23.00 : 21.50 : 19.75 : 20.00 : 20.00 : 19.75 : 20.00 : 19.50 : 23.25 : 22.25 : 19.50 : 19.75 : 19.50 : 19.25 : 19.25 : 18.50 : 22.50 : 22.25 : 20.25 : 19.50 : 19.50 : 19.00 : 19.75 : 18.50 : 22.50 : 22.50 : 20.25 : 19.00 : 19.00 : 18.50 : 19.25 : 19.00 :  
 AMG temp: 25.06
CO2: 0
TVOC: 400
IN CHECK time
Thursday, April 30 2020 15:02:58
hour
15
IN SENDDATA
connecting to network
...
WiFi connected
IP address set: 
192.168.0.186
[E][WiFiClient.cpp:258] connect(): socket error on fd 54, errno: 104, "Connection reset by peer"
Connection to server failed
connecting to network
..
WiFi connected
IP address set: 
192.168.0.186
[E][WiFiClient.cpp:258] connect(): socket error on fd 55, errno: 104, "Connection reset by peer"
Connection to server failed
connecting to network
...
WiFi connected
IP address set: 
192.168.0.186
[E][WiFiClient.cpp:258] connect(): socket error on fd 56, errno: 104, "Connection reset by peer"
Connection to server failed
Data transmission failed!IN SLEEP
Going to sleep...

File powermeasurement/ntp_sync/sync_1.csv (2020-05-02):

#Digilent WaveForms Oscilloscope Acquisition
#Device Name: Discovery2
#Serial Number: SN:210321A4216E
#Date Time: 2020-04-30 20:16:13.865
#Sample rate: 800Hz
#Samples: 8000
#Trigger: Source: Channel 1 Type: Edge Condition: Rising Level: 0 V Hyst.: Auto HoldOff: 0 s
#Channel 1: Range: 50 mV/div Offset: -200 mV
Time (s) | Channel 1 (V)
-5 | -0.00172475
-4.99875 | -0.00272614
-4.9975 | -0.00239234
-4.99625 | -0.00172475
-4.995 | -0.000723349
-4.99375 | -0.00038955
-4.9925 | -0.00038955
-4.99125 | -0.000723349
-4.99 | -0.00038955
-4.98875 | 0.000945647
-4.9875 | 0.00228084
-4.98625 | 0.000278049
-4.985 | -0.00139095
-4.98375 | -0.00172475
-4.9825 | -0.00105715
-4.98125 | -0.000723349
-4.98 | -0.00172475
-4.97875 | -0.00272614
-4.9775 | -0.00272614
-4.97625 | -0.00205855
-4.975 | -0.000723349
-4.97375 | -0.00038955
-4.9725 | -0.00038955
-4.97125 | -0.000723349
-4.97 | -0.00038955
-4.96875 | 0.00127945
-4.9675 | 0.00228084
-4.96625 | 0.000278049
-4.965 | -0.00139095
-4.96375 | -0.00205855
-4.9625 | -0.00105715
-4.96125 | -0.000723349
-4.96 | -0.00139095
-4.95875 | -0.00272614
-4.9575 | -0.00239234
-4.95625 | -0.00205855
-4.955 | -0.000723349
-4.95375 | -0.00038955
-4.9525 | -0.00038955
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

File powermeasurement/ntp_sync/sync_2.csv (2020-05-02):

#Digilent WaveForms Oscilloscope Acquisition
#Device Name: Discovery2
#Serial Number: SN:210321A4216E
#Date Time: 2020-04-30 20:21:10.167
#Sample rate: 800Hz
#Samples: 6230
#Trigger: Source: Channel 1 Type: Edge Condition: Rising Level: 0 V Hyst.: Auto HoldOff: 0 s
#Channel 1: Range: 50 mV/div Offset: -200 mV
Time (s) | Channel 1 (V)
-5 | 0.0743815
-4.99875 | -0.00139095
-4.9975 | -0.00205855
-4.99625 | -0.00038955
-4.995 | -0.000723349
-4.99375 | -0.00205855
-4.9925 | -0.00272614
-4.99125 | -0.00205855
-4.99 | -0.00139095
-4.98875 | -5.57504e-05
-4.9875 | -5.57504e-05
-4.98625 | -5.57504e-05
-4.985 | -0.00038955
-4.98375 | 0.000278049
-4.9825 | 0.00194704
-4.98125 | 0.00194704
-4.98 | -5.57504e-05
-4.97875 | -0.00139095
-4.9775 | -0.00205855
-4.97625 | -0.00038955
-4.975 | -0.000723349
-4.97375 | -0.00205855
-4.9725 | -0.00272614
-4.97125 | -0.00205855
-4.97 | -0.00139095
-4.96875 | -0.00038955
-4.9675 | -5.57504e-05
-4.96625 | -0.00038955
-4.965 | -0.000723349
-4.96375 | 0.000278049
-4.9625 | 0.00194704
-4.96125 | 0.00194704
-4.96 | -0.00038955
-4.95875 | -0.00139095
-4.9575 | -0.00205855
-4.95625 | -0.00038955
-4.955 | -0.000723349
-4.95375 | -0.00205855
-4.9525 | -0.00272614
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

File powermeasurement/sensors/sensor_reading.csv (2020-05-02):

#Digilent WaveForms Oscilloscope Acquisition
#Device Name: Discovery2
#Serial Number: SN:210321A4216E
#Date Time: 2020-04-30 20:02:49.283
#Sample rate: 800Hz
#Samples: 4922
#Trigger: Source: Channel 1 Type: Edge Condition: Rising Level: 0 V Hyst.: Auto HoldOff: 0 s
#Channel 1: Range: 20 mV/div Offset: 0 V
Time (s) | Channel 1 (V)
-3.99875 | 0.00808849 | 8.85E-05 | 8.85E-05
-3.9975 | 0.0067533 | -0.0012467 | -0.0012467
-3.99625 | 0.0060857 | -0.0019143 | -0.0019143
-3.995 | 0.0064195 | -0.0015805 | -0.0015805
-3.99375 | 0.0070871 | -0.0009129 | -0.0009129
-3.9925 | 0.00842229 | 0.00042229 | 0.00042229
-3.99125 | 0.00875609 | 0.00075609 | 0.00075609
-3.99 | 0.00842229 | 0.00042229 | 0.00042229
-3.98875 | 0.00808849 | 8.85E-05 | 8.85E-05
-3.9875 | 0.00875609 | 0.00075609 | 0.00075609
-3.98625 | 0.0107589 | 0.0027589 | 0.0027589
-3.985 | 0.0107589 | 0.0027589 | 0.0027589
-3.98375 | 0.00875609 | 0.00075609 | 0.00075609
-3.9825 | 0.0074209 | -0.0005791 | -0.0005791
-3.98125 | 0.0067533 | -0.0012467 | -0.0012467
-3.98 | 0.00842229 | 0.00042229 | 0.00042229
-3.97875 | 0.00808849 | 8.85E-05 | 8.85E-05
-3.9775 | 0.0067533 | -0.0012467 | -0.0012467
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

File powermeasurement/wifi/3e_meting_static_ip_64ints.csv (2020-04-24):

#Digilent WaveForms Oscilloscope Acquisition
#Device Name: Discovery2
#Serial Number: SN:210321A4216E
#Date Time: 2020-04-19 17:14:44.497
#Sample rate: 1600Hz
#Samples: 8000
#Trigger: Source: Channel 1 Type: Edge Condition: Rising Level: 0 V Hyst.: Auto HoldOff: 0 s
#Channel 1: Range: 50 mV/div Offset: -240 mV
#Power Supplies: OFF
#Positive Supply: Rdy
#Voltage: 1 V
#Negative Supply: Rdy
#Voltage: -1 V
Time (s) | Channel 1 (V)
-2.50062 | 4.9312e-05
-2.5 | 4.9312e-05
-2.49937 | 0.00138451
-2.49875 | 0.00205211
-2.49812 | 0.00138451
-2.4975 | 0.000383111
-2.49687 | -0.00128588
-2.49625 | -0.00195348
-2.49562 | -0.00228728
-2.495 | -0.00295488
-2.49437 | -0.00295488
-2.49375 | -0.00128588
-2.49313 | -0.000618286
-2.4925 | -0.000952086
-2.49187 | -0.000952086
-2.49125 | -0.00161968
-2.49063 | -0.00395628
-2.49 | -0.00362248
-2.48937 | -0.00362248
-2.48875 | -0.00328868
-2.48812 | -0.00295488
-2.4875 | -0.00295488
-2.48687 | -0.000618286
-2.48625 | 4.9312e-05
-2.48562 | 0.000383111
-2.485 | 0.000383111
-2.48438 | -0.000284487
-2.48375 | -0.000952086
-2.48312 | -0.000952086
-2.4825 | -0.000952086
-2.48188 | -0.00128588
-2.48125 | -0.00128588
-2.48062 | 4.9312e-05
-2.48 | 4.9312e-05
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

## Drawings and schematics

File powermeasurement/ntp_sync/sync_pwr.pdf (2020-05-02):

## Charge = 0.080 mAh

## Power consumption

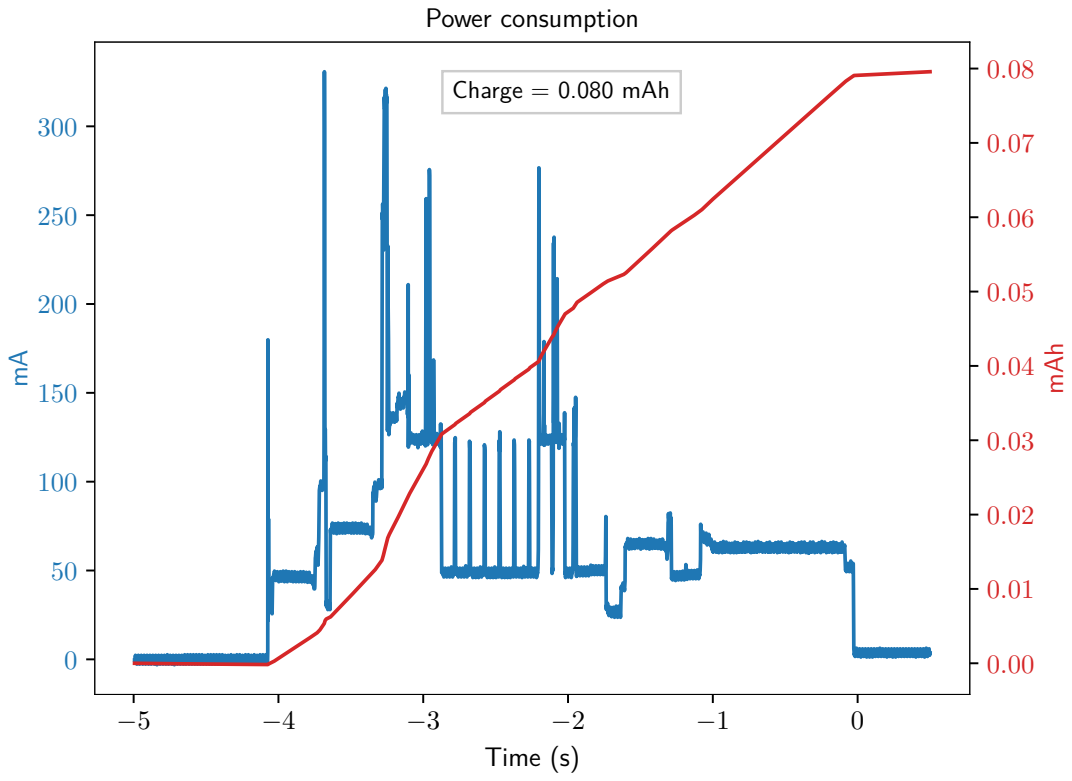
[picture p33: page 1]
Time (s); mAh

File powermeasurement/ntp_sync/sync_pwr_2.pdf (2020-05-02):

## Charge = 0.066 mAh

## Power consumption

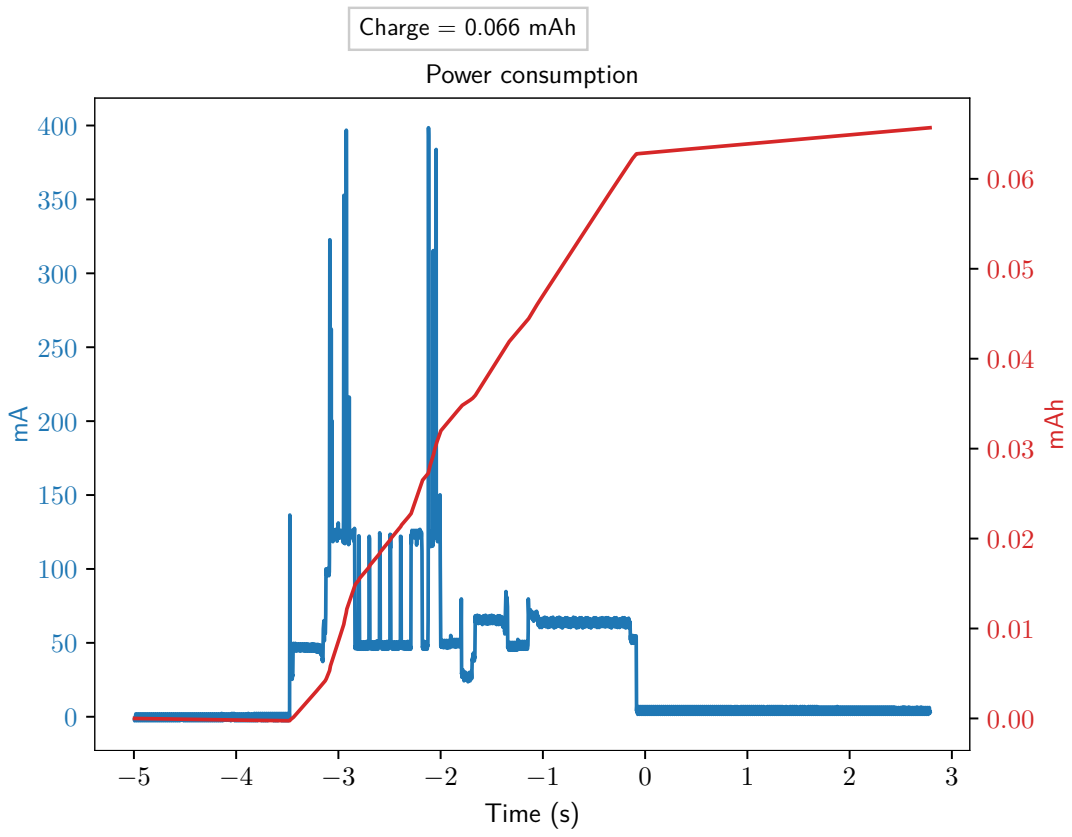
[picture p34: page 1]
Time (s); mAh

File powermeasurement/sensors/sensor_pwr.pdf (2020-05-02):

## Charge = 0.035 mAh

## Power consumption

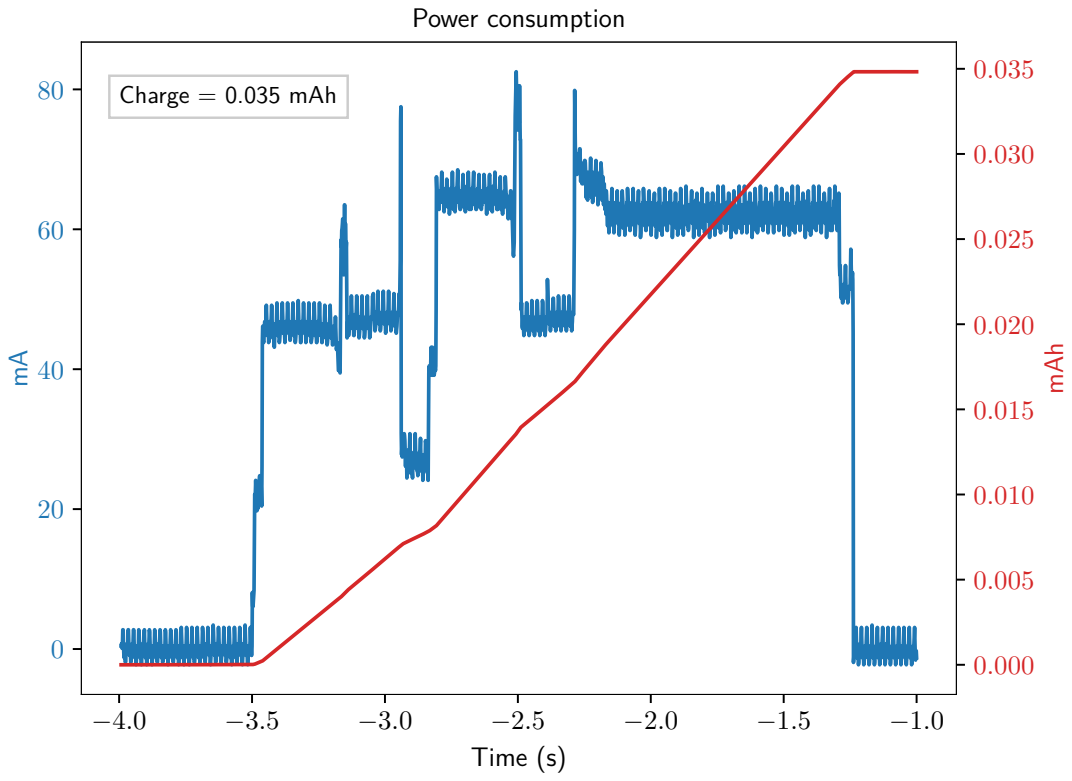
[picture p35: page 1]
Time (s); mAh

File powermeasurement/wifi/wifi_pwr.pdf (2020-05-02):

## Charge = 0.041 mAh

## Power consumption

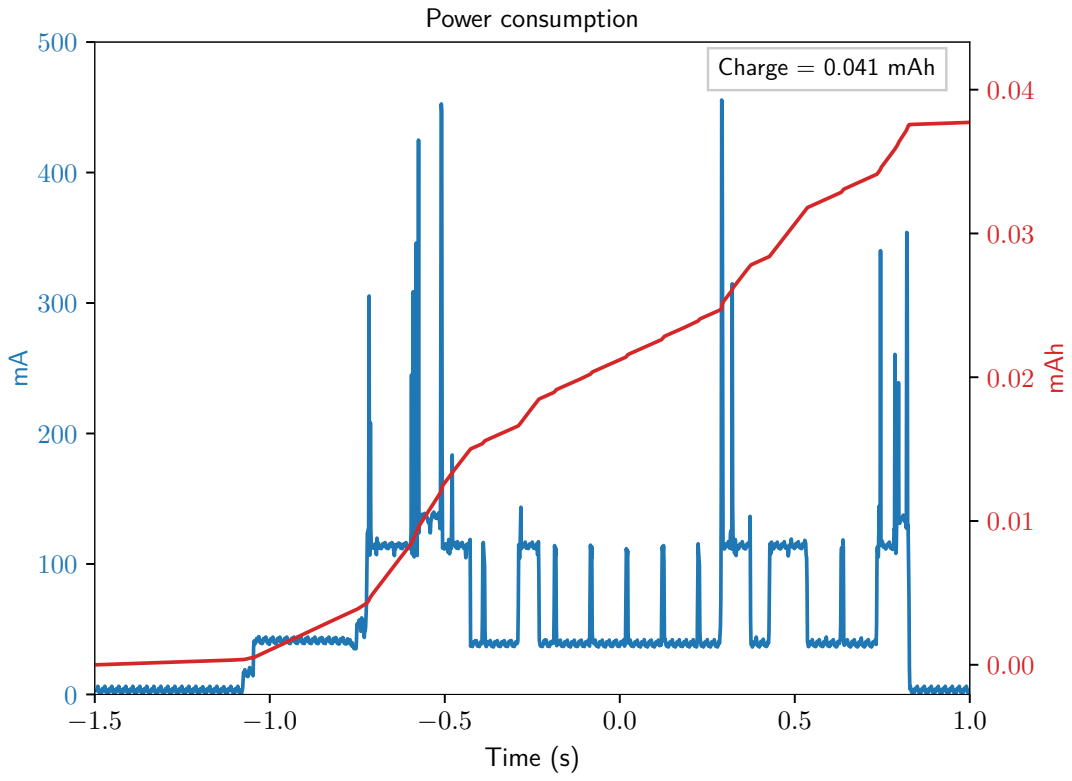
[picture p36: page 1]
Time (s); mAh

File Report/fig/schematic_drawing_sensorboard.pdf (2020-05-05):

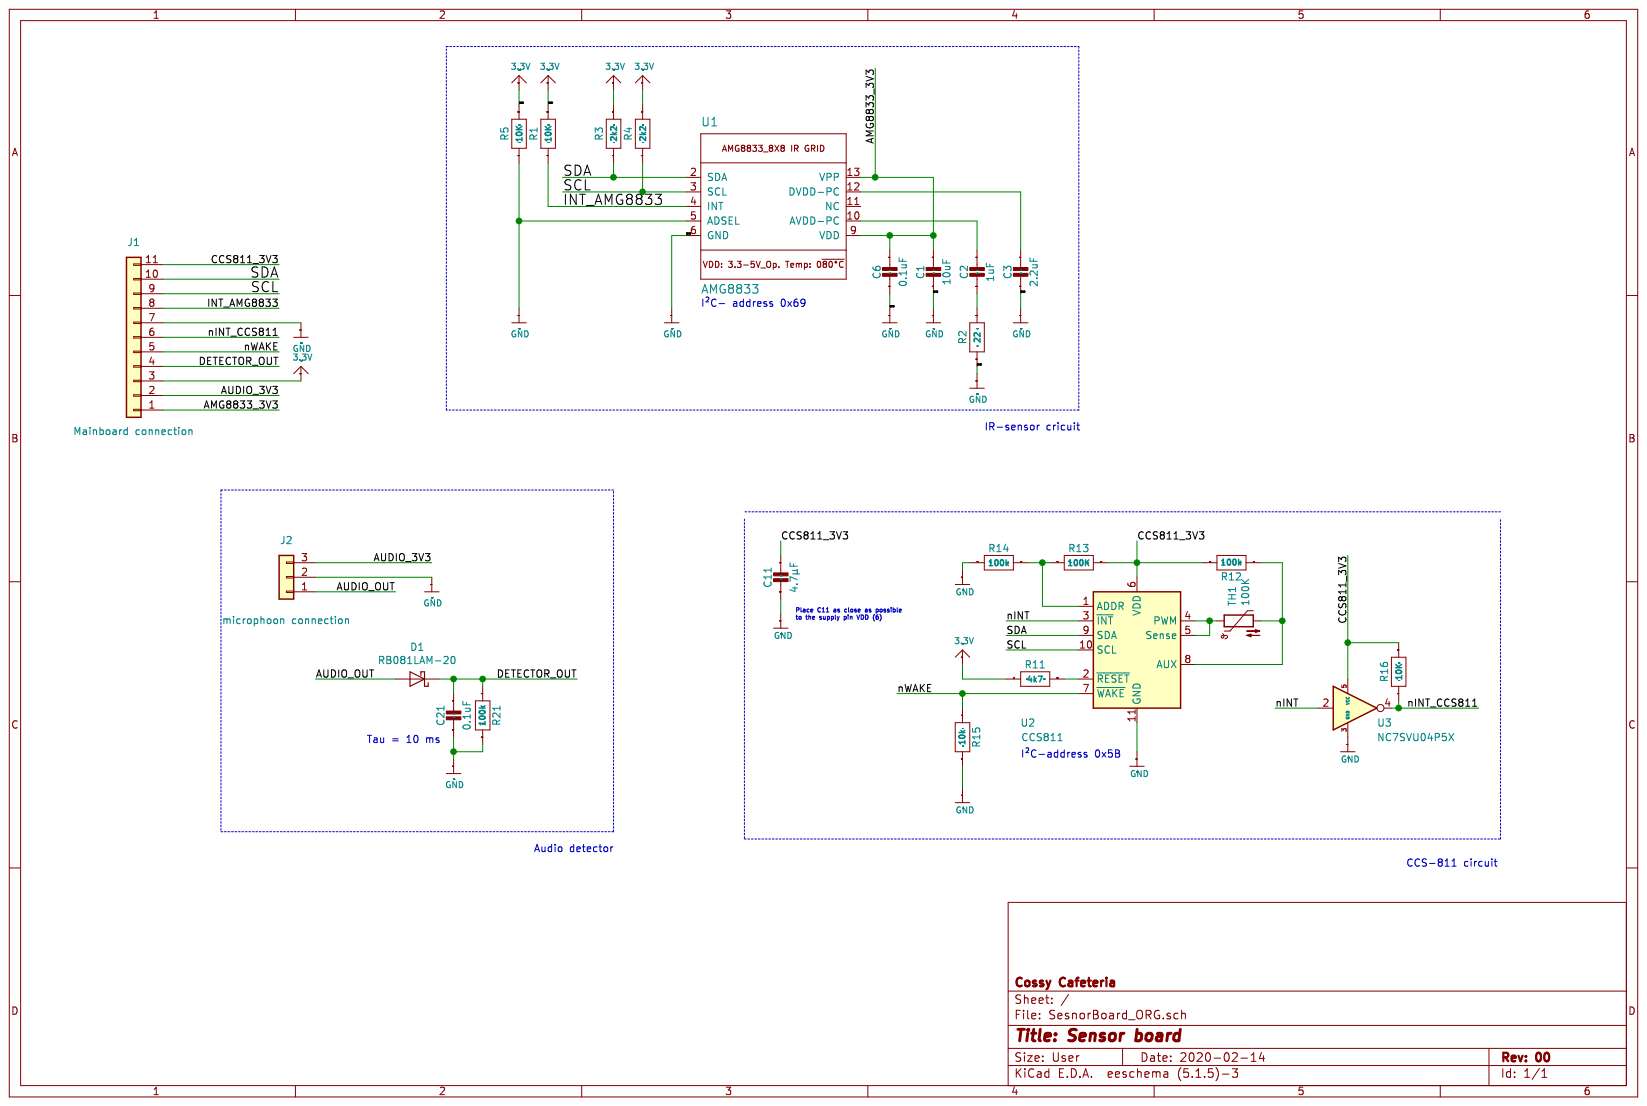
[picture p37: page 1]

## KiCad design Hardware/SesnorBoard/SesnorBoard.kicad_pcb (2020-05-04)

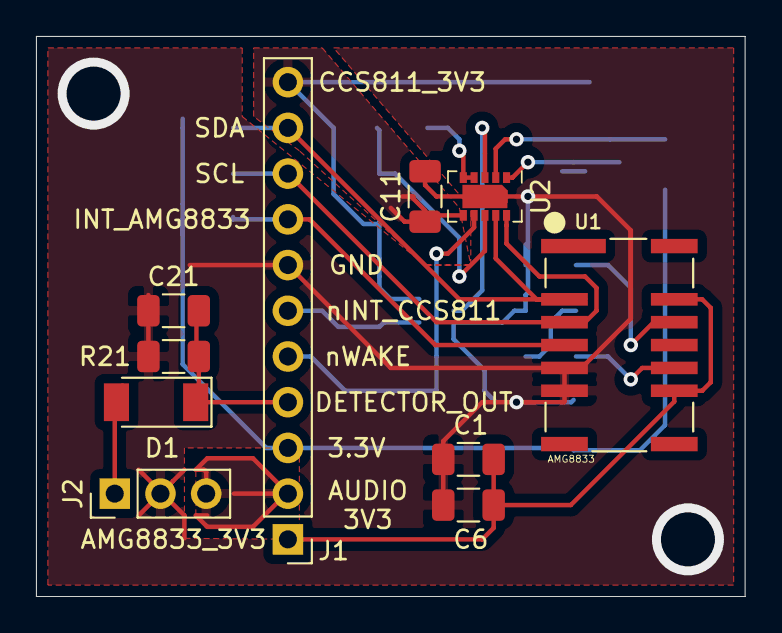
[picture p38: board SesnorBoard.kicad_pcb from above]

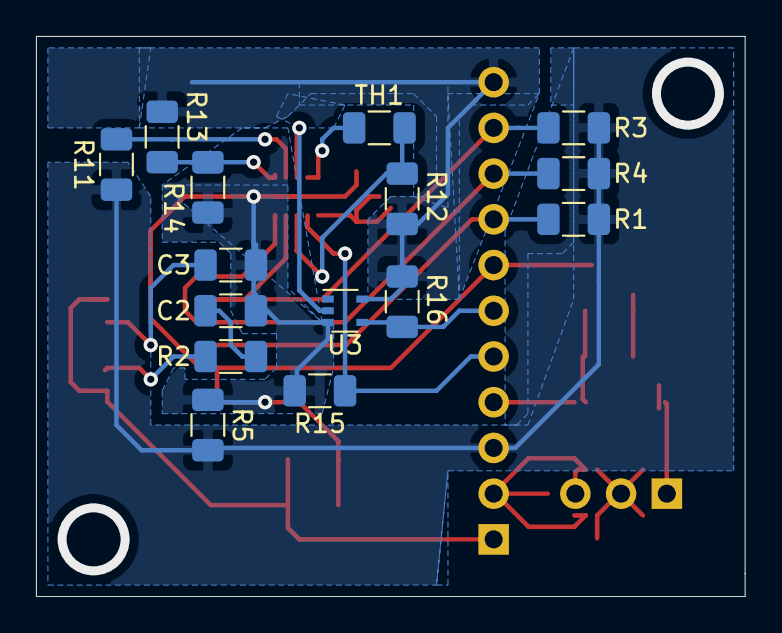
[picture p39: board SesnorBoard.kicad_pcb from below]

Board: 2 copper layers, 39.4 x 31.1 mm, 25 parts (15 on the bottom side), 20 nets.

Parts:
C1: 10uF; C_1206_3216Metric
C2: 1uF; C_1206_3216Metric
C3: 2.2uF; C_1206_3216Metric
C6, C21: 0.1uF; C_1206_3216Metric
C11: 4.7µF; C_1206_3216Metric
D1: RB081LAM-20; D_SOD-128
J1: Mainboard connection; PinHeader_1x11_P2.54mm_Vertical
J2: microphoon connection; PinHeader_1x03_P2.54mm_Vertical
R1, R5, R16: 10K; R_1206_3216Metric
R2: 22; R_1206_3216Metric
R3, R4: 2k2; R_1206_3216Metric
R11: 4k7; R_1206_3216Metric
R12, R14: 100k; R_1206_3216Metric
R13: 100K; R_1206_3216Metric
R15: 10k; R_1206_3216Metric
R21: 1M; R_1206_3216Metric
TH1: 100K; R_1206_3216Metric
U1: AMG8833
U2: CCS811; AMS_LGA-10-1EP_2.7x4mm_P0.6mm
U3: NC7SVU04P5X; SOT-353_SC-70-5

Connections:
3.3V: J1.3, R1.2, R3.2, R4.2, R5.2, R11.1
/AMG8833_3V3: C1.1, C6.1, J1.1, U1.9, U1.13
/AUDIO_3V3: J1.2, J2.3
/AUDIO_OUT: D1.2, J2.1
/CCS811_3V3: C11.1, J1.11, R12.2, R13.2, R16.2, U2.6, U3.5
/DETECTOR_OUT: C21.1, D1.1, J1.4, R21.1
/INT_AMG8833: J1.8, R1.1, U1.4
/SCL: J1.9, R4.1, U1.3, U2.10
/SDA: J1.10, R3.1, U1.2, U2.9
/nINT: U2.3, U3.2
/nINT_CCS811: J1.6, R16.1, U3.4
/nWAKE: J1.5, R15.1, U2.7
GND: C1.2, C3.2, C6.2, C11.2, C21.2, J1.7, J2.2, R2.1, R5.1, R14.1, R15.2, R21.2, U1.5, U1.6, U2.11, U3.3
unnamed: C2.1, U1.10
unnamed: C2.2, R2.2
unnamed: C3.1, U1.12
unnamed: R11.2, U2.2
unnamed: R12.1, TH1.2, U2.8
unnamed: R13.1, R14.2, U2.1
unnamed: TH1.1, U2.4, U2.5

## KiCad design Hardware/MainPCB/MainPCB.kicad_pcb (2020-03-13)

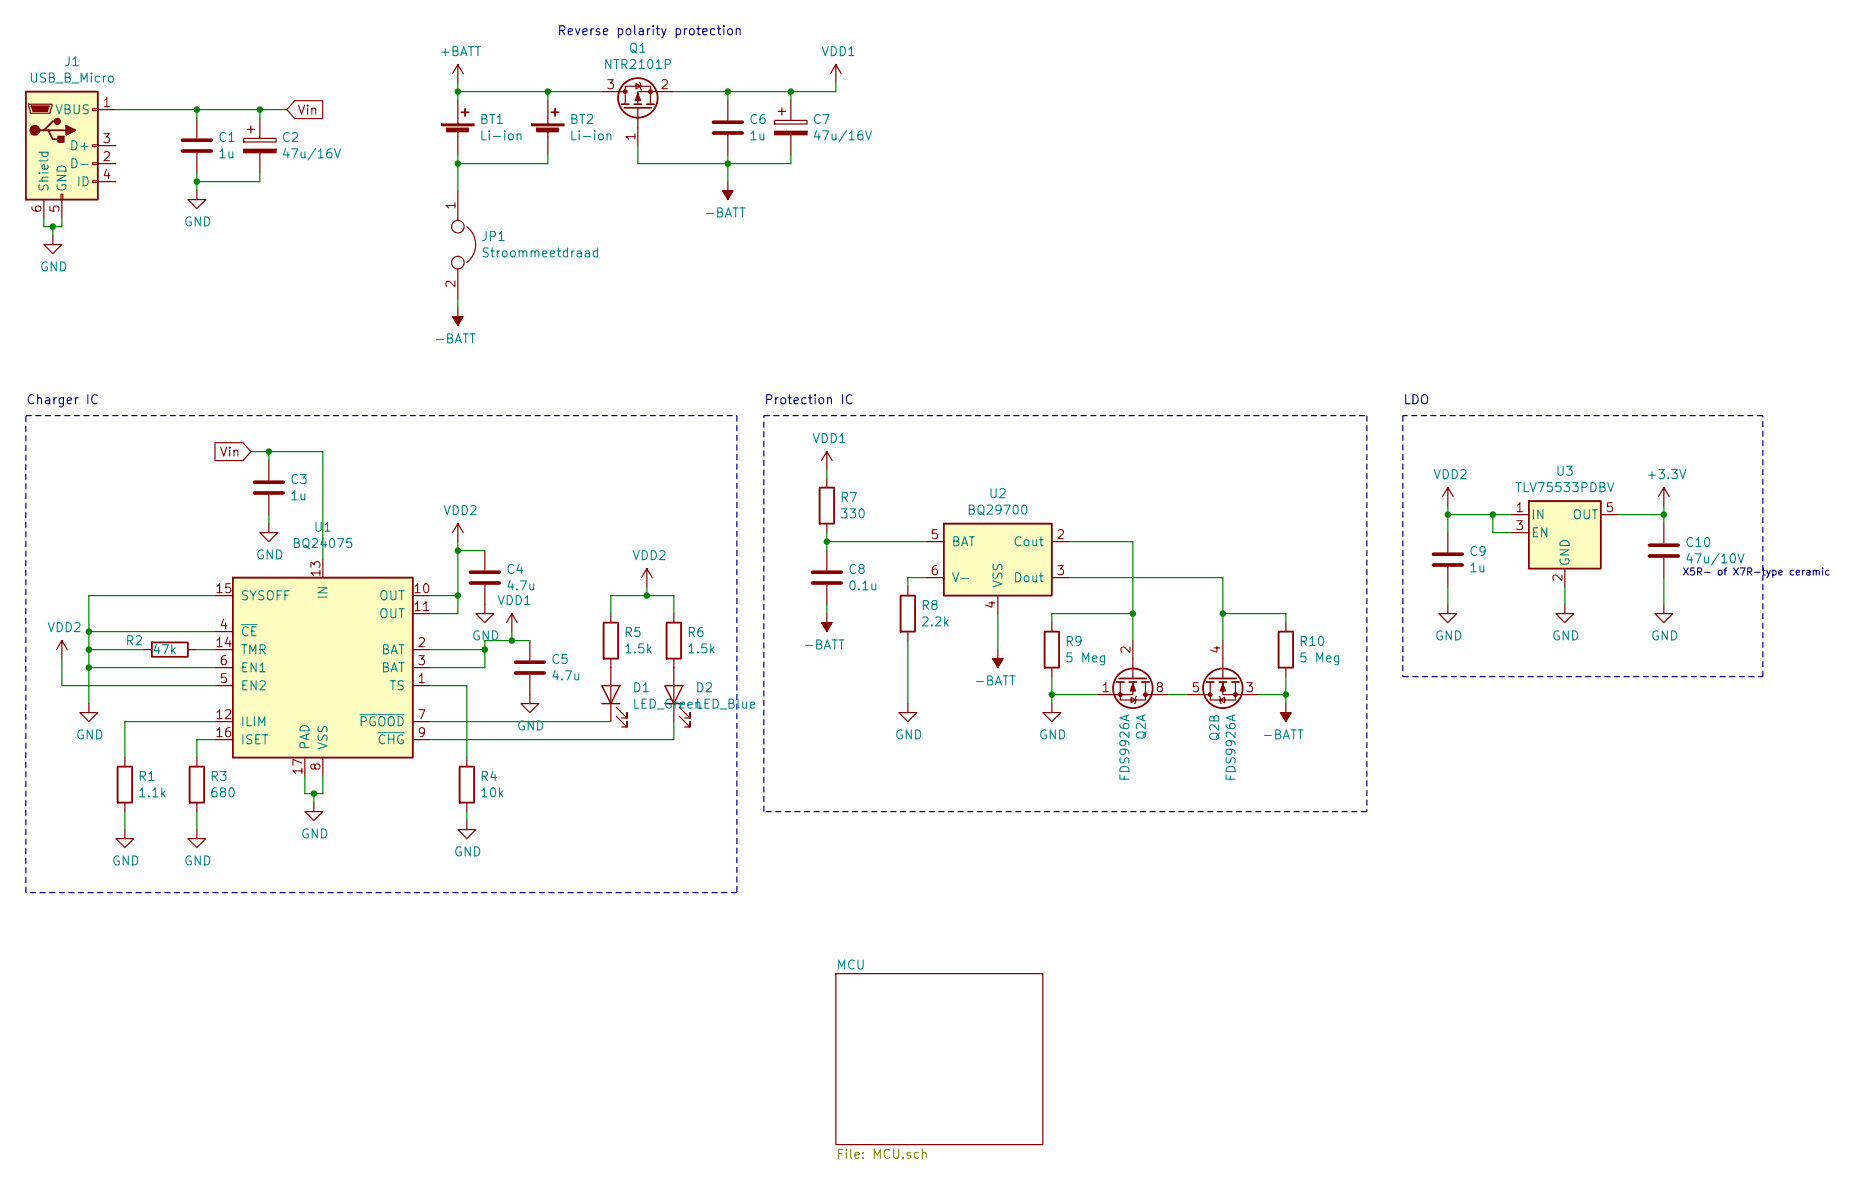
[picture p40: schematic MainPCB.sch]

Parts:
BT1, BT2: Li-ion; BatteryHolder_Keystone_1042_1x18650
C1, C3, C6, C9: 1u; C_1206_3216Metric_Pad1.42x1.75mm_HandSolder
C2, C7: 47u/16V; CP_Elec_5x5.4
C4, C5: 4.7u; C_1206_3216Metric_Pad1.42x1.75mm_HandSolder
C8: 0.1u; C_1206_3216Metric_Pad1.42x1.75mm_HandSolder
C10: 47u/10V; C_1206_3216Metric_Pad1.42x1.75mm_HandSolder
D1: LED_Green; LED_D3.0mm
D2: LED_Blue; LED_D3.0mm
J1: USB_B_Micro; USB_Micro-B_Wuerth_629105150521
JP1: Stroommeetdraad; Wire
Q1: NTR2101P; SOT-23
Q2: FDS9926A; SOIC-8_3.9x4.9mm_P1.27mm
R1: 1.1k; R_1206_3216Metric_Pad1.42x1.75mm_HandSolder
R2: 47k; R_1206_3216Metric_Pad1.42x1.75mm_HandSolder
R3: 680; R_1206_3216Metric_Pad1.42x1.75mm_HandSolder
R4: 10k; R_1206_3216Metric_Pad1.42x1.75mm_HandSolder
R5, R6: 1.5k; R_1206_3216Metric_Pad1.42x1.75mm_HandSolder
R7: 330; R_1206_3216Metric_Pad1.42x1.75mm_HandSolder
R8: 2.2k; R_1206_3216Metric_Pad1.42x1.75mm_HandSolder
R9, R10: 5 Meg; R_1206_3216Metric_Pad1.42x1.75mm_HandSolder
U1: BQ24075; VQFN-16-1EP_3x3mm_P0.5mm_EP1.6x1.6mm
U2: BQ29700; WSON-6_1.5x1.5mm_P0.5mm
U3: TLV75533PDBV; SOT-23-5

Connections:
+3V3: C10.1, U3.5 (OUT); also elsewhere on the board
+BATT: BT1.1 (+), BT2.1 (+), Q1.3 (D)
-BATT: C6.2, C7.2, C8.2, JP1.2, Q1.1 (G), Q2.3 (S2), R10.2, U2.4 (VSS)
GND: C1.2, C2.2, C3.2, C4.2, C5.2, C9.2, C10.2, J1.5 (GND), J1.6 (Shield), Q2.1 (S1), R1.2, R2.2, R3.2, R4.2, R8.2, R9.2, U1.4 (~CE), U1.6 (EN1), U1.8 (VSS), U1.15 (SYSOFF), U1.17 (PAD), U3.2 (GND); also elsewhere on the board
unnamed: BT1.2 (-), BT2.2 (-), JP1.1
unnamed: C8.1, R7.2, U2.5 (BAT)
unnamed: D1.1 (K), U1.7 (~PGOOD)
unnamed: D1.2 (A), R5.2
unnamed: D2.1 (K), U1.9 (~CHG)
unnamed: D2.2 (A), R6.2
unnamed: Q2.2 (G1), R9.1, U2.2 (Cout)
unnamed: Q2.4 (G2), R10.1, U2.3 (Dout)
unnamed: Q2.5 (D2), Q2.6 (D2), Q2.7 (D1), Q2.8 (D1)
unnamed: R1.1, U1.12 (ILIM)
unnamed: R2.1, U1.14 (TMR)
unnamed: R3.1, U1.16 (ISET)
unnamed: R4.1, U1.1 (TS)
unnamed: R8.1, U2.6 (V-)
VDD1: C5.1, C6.1, C7.1, Q1.2 (S), R7.1, U1.2 (BAT), U1.3 (BAT)
VDD2: C4.1, C9.1, R5.1, R6.1, U1.5 (EN2), U1.10 (OUT), U1.11 (OUT), U3.1 (IN), U3.3 (EN)
Vin: C1.1, C2.1, C3.1, J1.1 (VBUS), U1.13 (IN)

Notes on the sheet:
Charger IC
Protection IC
LDO
X5R- of X7R-type ceramic
Reverse polarity protection

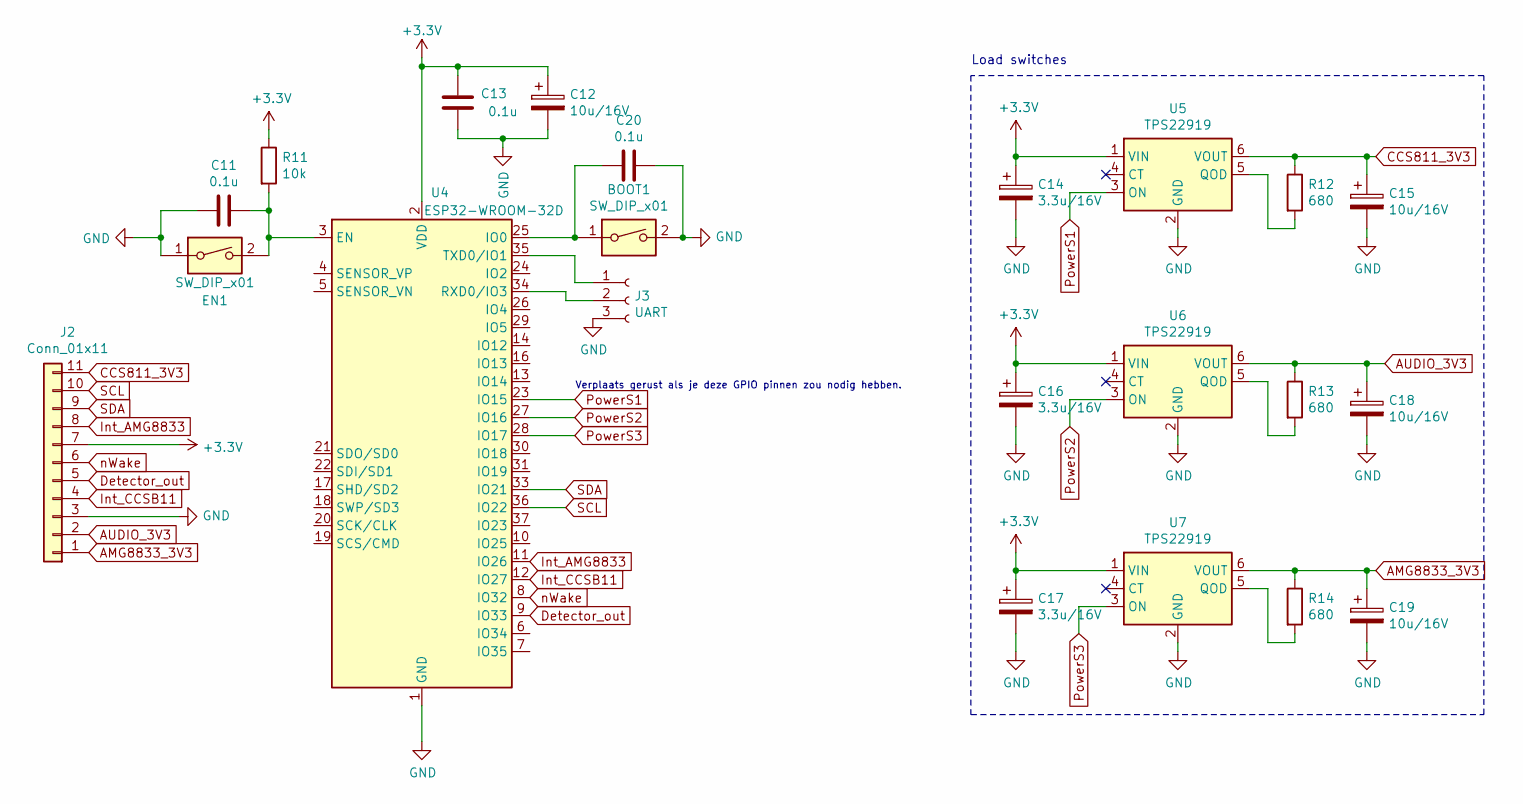
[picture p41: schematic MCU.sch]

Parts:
BOOT1: SW_DIP_x01; SW_Push_1P1T_NO_6x6mm_H9.5mm
C11, C13, C20: 0.1u; C_1206_3216Metric_Pad1.42x1.75mm_HandSolder
C12, C15, C18, C19: 10u/16V; CP_Elec_4x5.4
C14, C16, C17: 3.3u/16V; CP_Elec_4x5.4
EN1: SW_DIP_x01; SW_Push_1P1T_NO_6x6mm_H9.5mm
J2: Conn_01x11; PinHeader_1x11_P2.54mm_Vertical
J3: UART; PinHeader_1x03_P2.54mm_Vertical
R11: 10k; R_1206_3216Metric_Pad1.42x1.75mm_HandSolder
R12, R13, R14: 680; R_1206_3216Metric_Pad1.42x1.75mm_HandSolder
U4: ESP32-WROOM-32D; ESP32-WROOM-32
U5, U6, U7: TPS22919; SOT-363_SC-70-6

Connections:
+3V3: C12.1, C13.2, C14.1, C16.1, C17.1, J2.7, R11.1, U4.2 (VDD), U5.1 (VIN), U6.1 (VIN), U7.1 (VIN); also elsewhere on the board
AMG8833_3V3: C19.1, J2.1, R14.1, U7.6 (VOUT)
AUDIO_3V3: C18.1, J2.2, R13.1, U6.6 (VOUT)
CCS811_3V3: C15.1, J2.11, R12.1, U5.6 (VOUT)
Detector_out: J2.5, U4.9 (IO33)
GND: BOOT1.2, C11.2, C12.2, C13.1, C14.2, C15.2, C16.2, C17.2, C18.2, C19.2, C20.1, EN1.1, J2.3, J3.3, U4.1 (GND), U4.15 (GND), U4.38 (GND), U4.39 (GND), U5.2 (GND), U6.2 (GND), U7.2 (GND); also elsewhere on the board
Int_AMG8833: J2.8, U4.11 (IO26)
Int_CCSB11: J2.4, U4.12 (IO27)
unnamed: BOOT1.1, C20.2, U4.25 (IO0)
unnamed: C11.1, EN1.2, R11.2, U4.3 (EN)
unnamed: J3.1, U4.35 (TXD0/IO1)
unnamed: J3.2, U4.34 (RXD0/IO3)
unnamed: R12.2, U5.5 (QOD)
unnamed: R13.2, U6.5 (QOD)
unnamed: R14.2, U7.5 (QOD)
PowerS1: U4.23 (IO15), U5.3 (ON)
PowerS2: U4.27 (IO16), U6.3 (ON)
PowerS3: U4.28 (IO17), U7.3 (ON)
SCL: J2.10, U4.36 (IO22)
SDA: J2.9, U4.33 (IO21)
nWake: J2.6, U4.8 (IO32)

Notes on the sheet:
Load switches
Verplaats gerust als je deze GPIO pinnen zou nodig hebben.

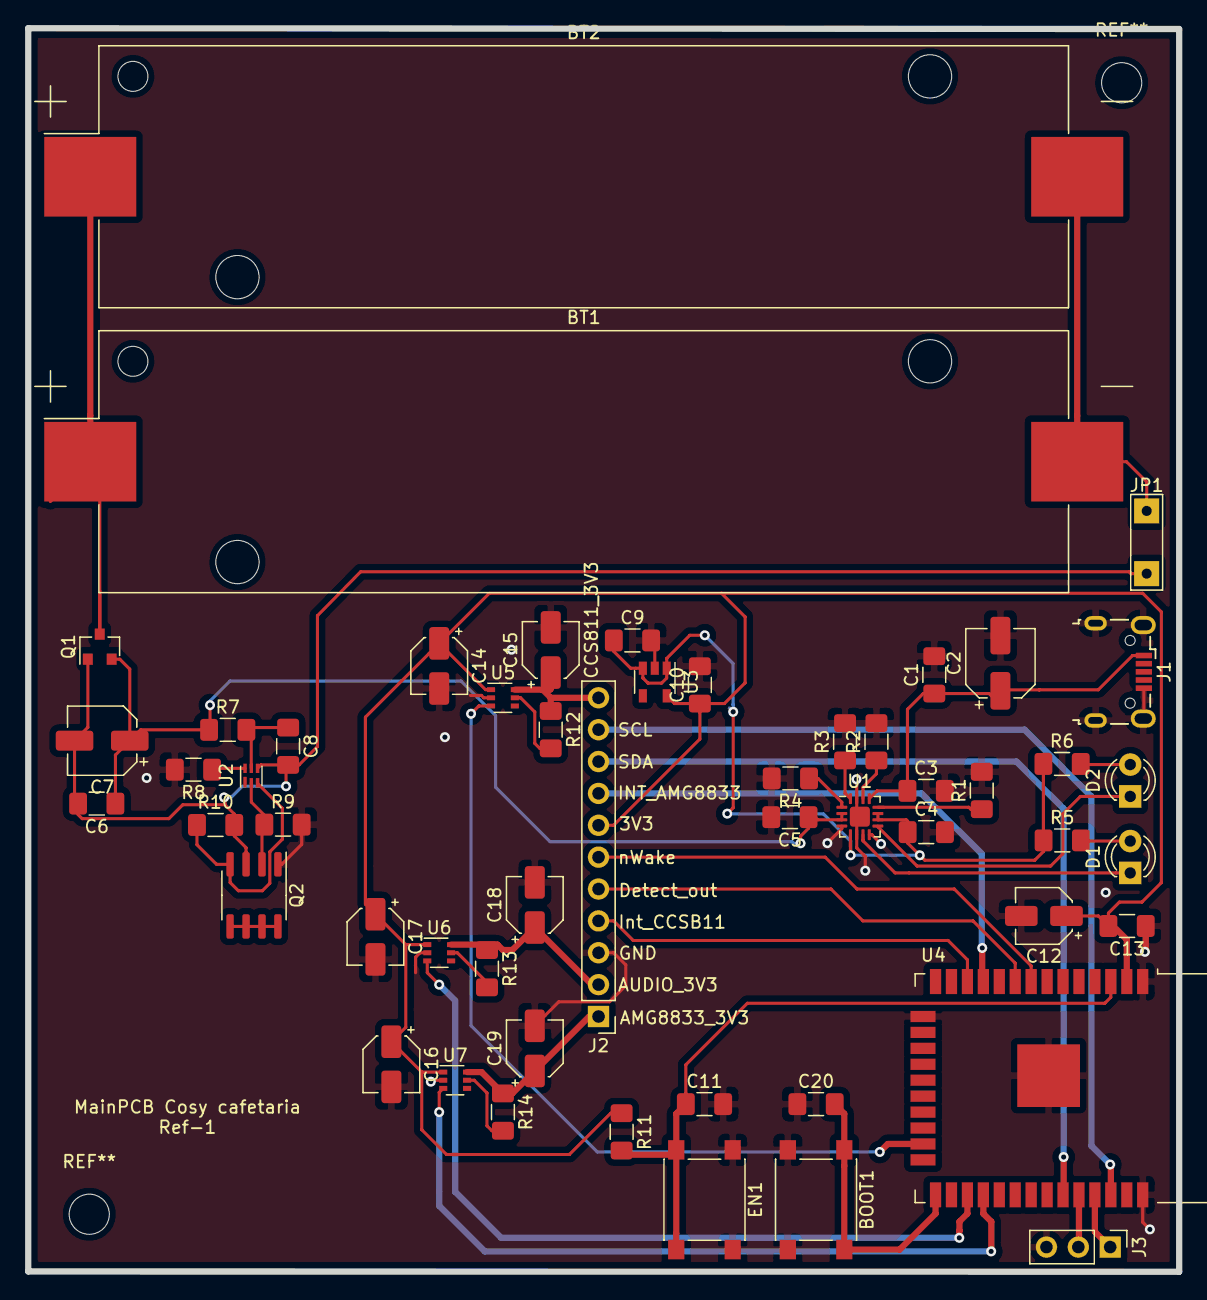
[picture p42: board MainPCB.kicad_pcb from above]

Board: 2 copper layers, 91.7 x 99.1 mm, 53 parts (0 on the bottom side), 40 nets.

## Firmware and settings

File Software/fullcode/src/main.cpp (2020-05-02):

#include <Arduino.h>
#include <WiFi.h>
#include <WiFiClientSecure.h>
#include "esp_wpa2.h"
#include <Wire.h>
#include "driver/adc.h"
#include <esp_wifi.h>
#include <esp_bt.h>
#include "_util.h"
#include <PriUint64.h>
#include "time.h"
#include "sensors.h"

#define ID 1 // id of the node
#define ccs881_pwr_pin 15
#define audio_pwr_pin 16
#define amg_pwr_pin 17
#define css_nwake    32

// data stored in RTC memory when entering deepsleep
RTC_DATA_ATTR static volatile APP_State_t appState = NTPSYNC; 
RTC_DATA_ATTR int days_since_sync = 0;
RTC_DATA_ATTR int sync_failed_count = 0;

// variables for sensor data
float audio_voltage = 0;
float pixeltemperature[64];
float tempAMG = 0;
uint16_t data_CCS811[2];


void setup() {
  // init wifi
  wifi_init_config_t cfg = WIFI_INIT_CONFIG_DEFAULT();
  esp_wifi_init(&cfg);

// for enterprise wifi
/*  
  WiFi.mode(WIFI_STA); //init wifi mode
  esp_wifi_sta_wpa2_ent_set_identity((uint8_t *)EAP_IDENTITY, strlen(EAP_IDENTITY)); //provide identity
  esp_wifi_sta_wpa2_ent_set_username((uint8_t *)EAP_IDENTITY, strlen(EAP_IDENTITY)); //provide username --> identity and username is same
  esp_wifi_sta_wpa2_ent_set_password((uint8_t *)EAP_PASSWORD, strlen(EAP_PASSWORD)); //provide password
  esp_wpa2_config_t config = WPA2_CONFIG_INIT_DEFAULT(); //set config settings to default
  esp_wifi_sta_wpa2_ent_enable(&config); //set config settings to enable function */

  //disable wifi, bluetooth and adc
  WiFi.disconnect(true);
  WiFi.mode(WIFI_OFF);
  btStop();
  adc_power_off();
  esp_wifi_stop();
  esp_bt_controller_disable();
  delay( 1 ); // has to be here!

  //start serial monitor
  Serial.begin(115200);

  //Print the wakeup reason for ESP32
	print_wakeup_reason();

  //enable gpio pins
  pinMode(ccs881_pwr_pin,OUTPUT);
  pinMode(audio_pwr_pin,OUTPUT);
  pinMode(amg_pwr_pin, OUTPUT);
  pinMode(css_nwake, OUTPUT);
  
  //enable i2c
  Wire.begin();

    
  //disable power to audio sensor
  gpio_hold_dis(GPIO_NUM_16); // disable lock
  digitalWrite(audio_pwr_pin, HIGH); 
  gpio_hold_en(GPIO_NUM_16); // lock state 
  gpio_deep_sleep_hold_en(); // to hold state during deepsleep
}


void loop() {

  switch (appState)
  {

  case WAKESENSORS:{
    Serial.println("IN WAKESENSORS");

    init_sensors();
    wake_sensors();
    appState = READSENSORS;// set next appstate
    goToDeepSleep_ms(105);// sleep until sensors are ready
  }break;

  case READSENSORS:{
    Serial.println("IN READSENSORS");

    init_sensors();
    
    // read audio level
    int audio = 0;
    get_audio_level(&audio);
    audio_voltage = (3.3 * audio) / 4095;

    // read AMG sensor data
    get_measurements_AMG8833(pixeltemperature, &tempAMG);

    // read CCSS811 sensor data
    get_measurements_CCS811(data_CCS811);

    // print sensor data
    Serial.print("audio voltage: ");
    Serial.println(audio_voltage);
    Serial.println("AMG pixels: ");
    for(int i=0; i<64; i++){
      Serial.print(pixeltemperature[i]);
      Serial.print(" : ");
    }
    Serial.println(" ");
    Serial.print(" AMG temp: ");
    Serial.println(tempAMG);
    Serial.print("CO2: ");
    Serial.println(data_CCS811[0]);
    Serial.print("TVOC: ");
    Serial.println(data_CCS811[1]);

    //todo determine when to send the data
    // for now: always send the data

    // set next appstate 
    appState = SENDDATA;
  }break;

  case SENDDATA:{
    Serial.println("IN SENDDATA");

    appState = SLEEP;// set next appstate

    int length = sizeof(pixeltemperature);
    int ctr = 0;
    // send sensor data
    while(true){  
      if(sendMessage(pixeltemperature, tempAMG, audio_voltage, data_CCS811, ID, length)){
        break;
      }
      ctr++;
      if(ctr>=2){// timeout after 2 tries
        Serial.print("Data transmission failed!");
        break;
      }
    }
  } break;
   
  case SLEEP:{
    Serial.println("IN SLEEP");
    appState = CHECKTIME;
    goToDeepSleep(600);
  }break;

  case CHECKTIME:{
    Serial.println("IN CHECK time");
    Serial.print("sync failed count: ");
    Serial.println(sync_failed_count);
    appState = WAKESENSORS;// set next appstate

    printLocalTime();

    // check if the system can be disabled during the night
    int hour = checkhour();
    if(hour == -1){ // if time is not availibly retry sync 5 minutes later
      Serial.println("ERROR: failed to obtain time");
      appState = NTPSYNC;// set next appstate
      if(sync_failed_count>=3){
        ESP.restart();
      }
      sync_failed_count++;
      goToDeepSleep(5*60); // sleep for 5 min
    }else{
      sync_failed_count = 0;
      if(hour >= 16 || hour <= 9){
        appState = NIGHTSLEEP;
      }
    }
  }break;
  
  case NTPSYNC:{
    Serial.println("IN SYNC");
    ntp_sync(); //sync rtc clock
    days_since_sync = 0;
    appState = CHECKTIME;// set next appstate
  }break;
  
  case NIGHTSLEEP:{
    Serial.println("NIGHTSLEEP");

    appState = WAKEFROMNIGHTSLEEP;// set next appstate
    
    // disable pwr to sensors
    gpio_hold_dis(GPIO_NUM_15); // disable lock
    gpio_hold_dis(GPIO_NUM_16); // disable lock
    gpio_hold_dis(GPIO_NUM_17); // disable lock
    digitalWrite(amg_pwr_pin, HIGH);
    digitalWrite(ccs881_pwr_pin, HIGH);
    digitalWrite(audio_pwr_pin, HIGH); 
    gpio_hold_en(GPIO_NUM_15); // lock state 
    gpio_hold_en(GPIO_NUM_16); // lock state 
    gpio_hold_en(GPIO_NUM_17); // lock state 
    gpio_deep_sleep_hold_en(); // to hold state during deepsleep
    
    // sleep until morning
    Serial.println("nightnight");
    goToDeepSleep(17*3600);
    
  }break;

   case WAKEFROMNIGHTSLEEP:{

     appState = CHECKTIME;// set next appstate

     days_since_sync++;
     Serial.print("Days since sync: ");
     Serial.println(days_since_sync);

     // sync clock if necessary
     if(days_since_sync > 14){ 
       appState = NTPSYNC;
     }

     //enable power to sensors
    gpio_hold_dis(GPIO_NUM_15); // disable lock
    gpio_hold_dis(GPIO_NUM_16); // disable lock
    gpio_hold_dis(GPIO_NUM_17); // disable lock
    digitalWrite(amg_pwr_pin, LOW);
    digitalWrite(ccs881_pwr_pin, LOW);
    digitalWrite(audio_pwr_pin, LOW); 
    gpio_hold_en(GPIO_NUM_15); // lock state 
    gpio_hold_en(GPIO_NUM_16); // lock state 
    gpio_hold_en(GPIO_NUM_17); // lock state 
    gpio_deep_sleep_hold_en(); // to hold state during deepsleep

  }break;
  }
}

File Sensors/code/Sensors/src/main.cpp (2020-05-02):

#include <Arduino.h>
#include <driver/gpio.h>
#include <driver/adc.h>
#include "Adafruit_CCS811.h"
#include "SparkFun_GridEYE_Arduino_Library.h"


#define GPIO_OUTPUT_IO_CCS811    32
#define GPIO_INPUT_IO_AUDIO    33
#define GPIO_OUTPUT_PIN_SEL  (1ULL<<GPIO_OUTPUT_IO_CCS811)
#define GPIO_INPUT_PIN_SEL  (1ULL<<GPIO_INPUT_IO_AUDIO)
#define ESP_INTR_FLAG_DEFAULT 0

 Adafruit_CCS811 sensor_CCS811;
 GridEYE sensor_AMG88;
 bool status;
 uint16_t data_CCS811[2];
 double temperature_CCS811=0;
 double* tempCCS = &temperature_CCS811;
 float pixeltemperature[64];
 float temperature_AMG8833=0;
 float* tempAMG = &temperature_AMG8833;
 int audio_level=0;
 int* audio = &audio_level;

/**
 * This function will initialize the CCC811-sensor
 * No input needed and no output will be returned  
 **/
void init_CCS811(){
    
  //INIT the GPIO pins for the sensors
  gpio_config_t io_conf;
  
  io_conf.mode = GPIO_MODE_OUTPUT;
  //bit mask of the pin that you want to set as output,GPIO32 =>nWake_CCS811
  io_conf.pin_bit_mask = GPIO_OUTPUT_PIN_SEL;
  //configure GPIO with the given settings
  gpio_config(&io_conf);
  
  gpio_pad_select_gpio(GPIO_NUM_32);
    /* Set the GPIO as a push/pull output */
  gpio_set_direction(GPIO_NUM_32, GPIO_MODE_OUTPUT);
  // Pin IO32 is for the CCS811_nWake 
  gpio_set_level(GPIO_NUM_32, 0);
   do{
    Serial.println("Try to initialize CCS811");
    status = sensor_CCS811.begin();
  }
  while(status == false) ;
  sensor_CCS811.setDriveMode(CCS811_DRIVE_MODE_250MS);
  // raise nWake to go to sleep
  gpio_set_level(GPIO_NUM_32, 1);
  
}

/**
 * This function will initialize GPIO33 as ADC-input
 * No input needed and no output will be returned  
 **/
void init_audio(){
    adc1_config_width(ADC_WIDTH_BIT_12);
    adc1_config_channel_atten(ADC1_CHANNEL_5,ADC_ATTEN_DB_0);   
}

/**
 * This function will initialize the AMG8833-sensor
 * No input needed and no output will be returned  
 **/
void init_AMG8833(){
  sensor_AMG88.begin();
}


/**
 * This function will wake both sensors
 * No input needed and no output will be returned  
 **/
void wake_sensors(){
  // Wake CCS811 
  gpio_set_level(GPIO_NUM_32, 0);
  // Wake AMG8833 
  sensor_AMG88.wake();
}


/**
 * This function will get the measurements from the CCS811, start delay 1ms
 * Input:  2 element array of the type uint16_t
 *  & pointer a double for the temperature
 * Output: None will be returned but the result will be set ion the array and pointer 
 **/
void get_measurements_CCS811(uint16_t data[2], double* temperature_CCS811){
  //Check is the data avaiable, wait for every check 10ms
  do {
    delay(1);
    status= sensor_CCS811.available();
  }
  while (status == false);
  // Calculate the temperature with the NTC-resistor applied.
  *temperature_CCS811 = sensor_CCS811.calculateTemperature();

  // Get the de eCO2- en TVOC-concentration, write to the array CCS811 array.
  sensor_CCS811.readData();
  data[1]= sensor_CCS811.geteCO2();
  data[0]= sensor_CCS811.getTVOC();

  // After getting the measurements put the sensor immediatly back to sleep, raise nWake
  gpio_set_level(GPIO_NUM_32, 1);
}


/**
 * This function will get the measurements from the AMG8833, start delay 10ms
 * Input:  64 element array of the type float
 *  & pointer a double for the temperature
 * Output: None will be returned but the result will be set ion the array and pointer 
 **/
void get_measurements_AMG8833(float* pixeltemperature, float* temperature_AMG8833){
  float data[2];
  //Check if the sensor has his data ready (first and last measurement not 0)
   
  do{
    //tim++;
    data[1] = sensor_AMG88.getPixelTemperatureRaw(63);
    data[0] = sensor_AMG88.getPixelTemperatureRaw(0);
  }
  while (data[0]==0 and data[1]==0);
  
  // When data is avaiable => het all pixels one by one
  for (int i = 0; i < 64; i++){
    pixeltemperature[i]=sensor_AMG88.getPixelTemperature(i);
  }
  //Get temperature of the AMG8833
  *temperature_AMG8833= sensor_AMG88.getDeviceTemperature();
  
  //After getting the measurements put the sensor immediatly back to sleep
  sensor_AMG88.sleep();
}


/**
 * This function will get level of the microphone from the ADC1 of th ESP32
 * Input:  pointer to the audiolevel variable if the type integer
 * Output: None will be returned but the result will be set ion the array and pointer 
 **/
void get_audio_level(int* level){
  *level = adc1_get_raw(ADC1_CHANNEL_5);
}  

/**
 * This is a call function. This will call all the initial function for the seperate parts
 * Input & Output: None
 **/

void init_sensors(){
  init_CCS811();
  init_AMG8833();
  init_audio();
}

/**
 * Setup of the program
 **/
void setup() {
    // Enable I²C serial for printing (serial for debug)
  Wire.begin();
  Serial.begin(115200);
  //Initialize the ADC GPIO 33, CCS811 and AMG8833
  init_sensors();
  
}

/**
 * Measurement loop
 **/
void loop() {
  //After choosen time may be more then several hours wake the sensors
  wake_sensors();
  //Audio level first avaiable koppeld to ESP32, or the settle time of the detector audiolevel
  get_audio_level(audio);
  //After 105ms the result of the AMG is fully avaiable
  delay(105);
  // Get result AMG after this is read out, the data of CCS811 is avaiable. After data was retrieve sensor will be put into sleep imemdiatly
  get_measurements_AMG8833(pixeltemperature,tempAMG);
  get_measurements_CCS811(data_CCS811,tempCCS);

  
      // print sensor data
    
    Serial.print("audio voltage: ");
    Serial.println(*audio);

    Serial.println("AMG pixels: ");
    for(int i=0; i<64; i++){
      Serial.print(pixeltemperature[i]);
      Serial.print(" : ");
    }
    Serial.println(" ");

    Serial.print(" AMG temp: ");
    Serial.println(*tempAMG);

    Serial.print("CO2: ");
    Serial.println(data_CCS811[0]);
    Serial.print("TVOC: ");
    Serial.println(data_CCS811[1]);
  //Delay time following run
 delay(5000);
}

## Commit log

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2020-02-28 Aanmaak MainPCB
    [MainPCB.kicad_pcb, MainPCB.sch]
2020-02-28 Toevoeging BOM excel file
    [BOM.xlsx]
2020-02-29 Batterij circuit beslissing genomen
    Beslissing genomen over het oplaad IC, protectie IC, dual N-ch mosfets, batterij. BOM aangepast me 3 verschillende sites bij (farnell, digi-key en mouser). + IC's geplaatst in MainPCB
    [BOM.xlsx, MainPCB.sch]
2020-02-29 Changed battery holder 1043 TH to 1042 SMD
    [BOM.xlsx, MainPCB.sch]
2020-02-29 Toevoeging LDO
    [BOM.xlsx, MainPCB.sch]
2020-03-02 Update BOM. Only Mouser links
    [BOM.xlsx]
2020-03-04 toevoeging 2x batterijen BOM
    [BOM.xlsx]
2020-03-04 Toevoeging 1 load switch
    [MCU.sch, MainPCB.kicad_pcb, MainPCB.sch]
2020-03-05 upload sensor board Robin + BOM
    [AMG8833_REV-B.brd, AMG8833_REV-B.kicad_pcb, AMG8833_REV-B.sch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]
2020-03-05 Discrete componenten rond IC's en IC's zelfs nagegaan. + toevoeging BOM
    [BOM.xlsx, MCU.sch, MainPCB.sch]
2020-03-05 schematic voor esp32 mainboard
    de esp toegevoegd en de nodige connecties gemaakt
    [MCU.sch, MainPCB.kicad_pcb, MainPCB.sch]
2020-03-06 added buttons to bom
    [BOM.xlsx]
2020-03-06 Main PCB volledig uitgerust met foorprints voor discrete componenten + BOM aangevuld met alles
    [BOM.xlsx, MCU.sch, MainPCB.kicad_pcb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]
2020-03-06 Eerste plaatsing van componenten op PCB
    [BOM.xlsx, MCU.sch, MainPCB.kicad_pcb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]
2020-03-07 Bom update package 0603 => 1206 sensor board
    [BOM.xlsx]
2020-03-08 Eerste pcb layouts ensorboard
    [AMG8833_REV-B.brd, AMG8833_REV-B.kicad_pcb, AMG8833_REV-B.sch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]
2020-03-09 Aux pin verwijderd + aanpassing gedaan VSS naar -VBAT en GND op de juiste plaats gezet
    [MCU.sch, MainPCB.kicad_pcb, MainPCB.sch]
2020-03-10 SEnsorboard PCB adapted to normal siezd pinheader
    [SesnorBoard.kicad_pcb, SesnorBoard_ORG.kicad_pcb, SesnorBoard_ORG.sch]
2020-03-11 wifi power test
    [data_1e_meting.csv, data_2e_meting.csv, data_3e_meting.csv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]
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2020-03-12 routed mcu part of main pcb
    [MCU.sch, MainPCB.kicad_pcb, MainPCB.sch]
2020-03-13 proberen oplossen
    [MainPCB.kicad_pcb, MainPCB.sch]
2020-03-13 Finished MainPCB + generated gerber files + aanpassingen BOM
    [BOM - kopie.xlsx, BOM.xlsx, MCU.sch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]
2020-03-14 insert pinnames on J1
    [SesnorBoard.kicad_pcb]
2020-03-14 Generate gerbers files of sensor board
    [SesnorBoard-B_Cu.gbr, SesnorBoard-B_Mask.gbr, SesnorBoard-B_Paste.gbr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]
2020-03-20 wifi fix: python + esp
    [_util.cpp, main.cpp]
2020-03-21 back up sensor board drawing files
    [SesnorBoard.kicad_pcb]
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2020-04-03 code update
    - static ip's for wifi => reduces connection time
    - RTC memory => retains variables in deepsleep
    - RTC timer with NTP sync => keeps time
    [data_1e_meting.csv, data_2e_meting.csv, data_3e_meting.csv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]
2020-04-07 Begin onderzoek CCS811 optimalisatie uitlezing
    In dit testrapport ga ik na hoe snel we een meting kunnen bekomen van de CCS811 en in een later stadium zijn energie verbruik eraan gekoppeld.
2020-04-11 Investigation and basic code sensors complete
    The investgiation on how long it takes for data is avaiable is done.
    Secondly, the basic code with functions for the sensors are completed. This is not yet implemented in a library.
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2020-04-12 Onderzoek mensendetectie
    Nog wat resultaten omtrent onze sensoren om mensen te detecteren.
    [Person tracking.csv]
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2020-04-16 Adding bom-file for sensor board
    Adding the Bom file as a CSV file in the hardware directory.
    [SesnorBoard.csv]
2020-04-18 BOM list mainPCB
    [BOM.xlsx, BOM_totaal.xlsx, MainPCB.csv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]
2020-04-18 Sensorboard toevoeging schematic pdf
    [MainPCB.sch]
2020-04-19 wifi power meting
    [3e_meting_static_ip_64ints.csv, NO_static_ip_64ints.csv, NO_static_ip_64ints_2e_meting.csv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]
2020-04-24 sensors and communication addition to main software
    completed:
    - integration of sensor code in main code (has to be tested)
    - transmission of dummy sensor data and processing in python of the
    received data
2020-04-24 full code ready (untested)
    [meting_all_sensorvalues.csv, meting_all_sensorvalues_2.csv, meting_all_sensorvalues_3.csv]
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2020-04-27 aanvulling protection IC
    [MainPCB.sch]
2020-04-28 Power management volledig aangevuld in report
    [MainPCB.sch]
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2020-04-30 verbruik metingen
    [3e_meting_static_ip_64ints.csv, NO_static_ip_64ints.csv, NO_static_ip_64ints_2e_meting.csv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]
2020-04-30 pwr grafieken
    [3e_meting_static_ip_64ints.csv, NO_static_ip_64ints.csv, NO_static_ip_64ints_2e_meting.csv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]
2020-05-01 battery life berekeningen in verslag
    [3e_meting_static_ip_64ints.csv, NO_static_ip_64ints.csv, NO_static_ip_64ints_2e_meting.csv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]
2020-05-02 Add some 3D-files and start on the sensor part of the report
    [sensorboard.iges]
2020-05-03 updated the sensor part of the report and corrected some issues of the PCB design.
    [SesnorBoard.kicad_pcb, SesnorBoard.sch]
2020-05-04 Text sensor and case done, only images and references need to be added to report for these parts
2020-05-05 Figures added sensor part in report
    [SesnorBoard.sch, SesnorBoard_ORG.sch]
2020-05-06 microcontroller added and started writing about finans
    [BOM_totaal.xlsx]
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
